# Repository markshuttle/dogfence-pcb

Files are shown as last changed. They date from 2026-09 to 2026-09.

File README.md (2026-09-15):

# Dog Fence Indicator & Surge Protection System

**Draft hardware revision: 1.2.1-dev. Reviewed baseline: 1.1.0. File-verified prototype artifacts are authorized; production and field release remain on hold. No upload or order is authorized.**

This repository documents a 4 km DogWatch SmartFence boundary with local DC fault
indicators and GDT surge paths. The implemented 16-part hybrid includes series
indicator branches and negative-voltage output shunts; it is not a qualified
lightning-protection design or completed hardware test report.

[REMEDIATION](REMEDIATION.md) owns the agreed requirements, issue decisions and
revision-specific results. [BOM.csv](pcb/BOM.csv) and the synchronized CAD/local
libraries own PCB population; [ASSEMBLY](pcb/ASSEMBLY.md#reviewed-components)
explains assembly applicability. [MATERIALS](MATERIALS.md#resistor-procurement-and-history)
preserves purchases, cancellations and allocations. A production pre-order is
not an implemented substitution, and prototype results do not qualify another part.

Use the working schematic, PCB, settings/rules and libraries under `pcb/`, not
generated `build/`, backups or `tmp/` copies, as design sources. File verification
does not close the [engineering holds and release gates](REMEDIATION.md#release-gates).

## 1. Deployment Baseline

| Item | Agreed requirement |
| :--- | :--- |
| Stations | **41**, at 0, 100, ..., 4000 m, covering 40 diagnostic spans. The 0 km and 4 km stations are separate boards at the shed. |
| Station types | **36 standard + 5 earth-connected**, retaining earth-connected locations at 0, 1000, 2000, 3000, and 4000 m. Five locations do not imply five independent electrodes. |
| Field equipment | One identical, fully populated board and two external LEDs per station. [MATERIALS](MATERIALS.md#1-station-inventory) owns total requirements, purchases and shortfalls. |
| Initial order | **Five fully assembled JLCPCB boards**, all required SMT and THT parts fitted. No field soldering. Prototype allocation and later production/spares are separate decisions. |
| Fabrication | Readily available **FR-4, two layers, 2 oz / 70 micrometres copper on both F.Cu and B.Cu, ENIG, nominal 1.6 mm finished thickness**. Green soldermask is the quote default, not a new performance qualification. No imposed high-Tg laminate, gold thickness upgrade, or filled-via process. |
| Enclosure | WISKA COMBI 308 with Essentra LCBSBM-6-01A-RT supports and WISKA **OneGel**, subject to assembled fit and process acceptance. Raised installation, not continuous submersion. |
| TEST duty | Nominal 36 V DC, usually one to two hours. **Continuous-safe normal TEST** is required for accidental extended operation; a timer is not the baseline safeguard. Fault/surge safety needs separate evidence. |
| Visibility | ON/OFF distinguishable at **5 m in full daylight**, at the final minimum field current and actual viewing angles. |

[MATERIALS](MATERIALS.md#assembly-and-quantity-allocation) separates field needs
from prototype consumption, the retained reference and spares. A five-board
prototype order is not five proven field spares.

## 2. Operation And Fault Localization

### Hub Contact Matrix

Both physical cable ends return to the shed. The full
[functional matrix](INSTALL.md#functional-matrix) uses **six independent ends**:
TEST feeds Start A/C positive and Start B negative, leaving End A/B/C individually
isolated. Required ties belong on source-side contacts only. No permanent End A/C
strap, opposite-end B return or dual-B negative return is permitted; those
connections defeat the agreed indication. OFF isolates all six ends at the hub,
but is not demonstrated lightning or maintenance isolation.

Follow [INSTALL's switch/source controls](INSTALL.md#switch-and-supply). Exact
switch configuration, DC suitability and global transfer require approval before
physical terminal assignment; extra poles remain unassigned. No direction
selector, automatic core classification or automatic return to RUN is required.

**TEST and OFF disable RF containment.** Provide clear RUN/OFF/TEST and fence-inactive labeling/indication, independent animal containment during testing, and an explicit operator return to RUN. See [INSTALL.md](INSTALL.md) for the controlled operating instructions and [RISKS.md](RISKS.md) for fault/earthing limitations.

### Indication For A Clean Cut

Use [INSTALL's clean-cut truth table](INSTALL.md#clean-cut-indications) for one
cut site with healthy indicators/GDTs and no additional inter-core shorts. The
first applicable state transition identifies the adjacent 100 m span, including
3900-4000 m; exact broken-core classification is not required. For multiple sites,
[repair and repeat TEST](INSTALL.md#repair-and-retest). Mixed open/short faults or
failed indicators/GDTs need separate troubleshooting; not every dark LED proves a cut.

### Station Connections

Three **WAGO 221-613** three-way splices maintain A/B/C cable continuity and provide short 2.5 mm^2 taps to `J_IN`. Normal perimeter current does **not** pass through every PCB's rails; each PCB draws its local indicator current. Surge current through a board is a different design case.

The [implemented circuit](pcb/ELECTRICAL.md#1-implemented-model) has separate
A-to-B and C-to-B one-way indicator branches. D3/D4 are output shunts after
D1/D2, not additional series parts. GDT paths join the core pairs and the separate
EARTH bus. Standard boards retain all parts but leave external `J_EARTH` unwired;
earth-connected stations follow the accepted site design.

RUN parallels the three cores at each transmitter end. The electrical record
preserves the historical parallel-resistance comparison, not RF compatibility
proof. Actual imbalance, faults, capacitance and earth coupling require checks
with the transmitter and receiver; the boards are not demonstrated RF-invisible.

## 3. Electrical Limits And Open Protection Work

Use [ELECTRICAL's named historical comparisons](pcb/ELECTRICAL.md#2-calculated-results)
and [DESIGN_BOUNDS](pcb/DESIGN_BOUNDS.md) for the current population's
cable/tolerance, leakage, power and fault screens. They are conditional models,
not measurements, enforced source limits, an exhaustive brightness minimum or
thermal qualification. The source/test commands and assumptions travel with those
records; do not copy retired-part values into current operating limits.

- Use **one TEST supply and one disconnected spare**, never interconnected
  supplies. Verify the actual unit and qualified settings under
  [INSTALL](INSTALL.md#switch-and-supply); a larger PSU does not coordinate faults.
- Negative shunts are not forward pulse-current regulators or reversed-lead
  immunity. Reverse recovery is not forward-clamp response. Ordinary RF,
  switching and nearby-lightning behavior remain unqualified.
- Cable-limited faults may not clear the fuse promptly. Powered-GDT recovery is
  unresolved, not an observed latched failure; conditional load lines do not
  predict extinction. Indicator resistors/shunts do not protect upstream GDT paths.
- Resistor wattage and SMT construction do not prove cool OneGel operation.
  Manufacturer mounting/rating transfer and actual chip/pad/PCB/material-interface
  temperatures require separate qualification; retired-part pulse/thermal data do
  not transfer. Continuous-safe normal TEST remains mandatory, without a timer.
- DC sparkover is not transient clamp voltage. Component impulse ratings,
  paralleled pins and heavy copper do not establish assembled surge/current,
  equal-sharing, direct-strike or lifetime ratings.

The [accepted risk boundaries](REMEDIATION.md#agreed-requirements) allow LED
damage from accidental installation polarity errors and rebuilding after a direct
strike, not all ordinary/nearby transient damage. Maintain the
[whole-boundary cattle-fence prohibition](INSTALL.md#cattle-fence-prohibition);
the withdrawn exposure is not qualified safe. [ACCEPTANCE](ACCEPTANCE.md) defines
the unperformed hardware tests; [RISKS](RISKS.md) explains their consequences.

## 4. Hardware Component Selection & Specifications

Use [BOM.csv](pcb/BOM.csv) and [Reviewed Components](pcb/ASSEMBLY.md#reviewed-components)
for the exact population, sourcing identities and assembly requirements. Detailed
component electrical ratings remain in [ELECTRICAL](pcb/ELECTRICAL.md#1-implemented-model);
reviewed drawings, maximum dimensions and rating conditions remain in the
controlled assembly/evidence notes. A C-code is not footprint or stock allocation
approval. The external indicator's limits, polarity, mounting and visibility
requirements are in [LED.md](LED.md).

[MATERIALS](MATERIALS.md#resistor-procurement-and-history) owns cancelled,
superseded and rejected selections. They are not substitutions or a second active
BOM. Sourcing parity does not establish job allocation; unresolved External rows
still block both publication modes under [AGENTS' sourcing rules](AGENTS.md#3-verification-and-publication).

## 5. Unapproved Alternatives

Retain these earlier sourcing suggestions for investigation, **not as approved upgrades or drop-ins**. No purchase, footprint fit, higher assembled surge capability, or lifetime benefit is established by this list. Differences in electrode configuration, body, lead diameter, pin mapping, RF loading, and thermal/pulse behavior may require redesign and new qualification.

| Intended references | Previously suggested alternatives |
| :--- | :--- |
| D1, D2 | Vishay 1N4007GP-E3/54 |
| R1, R2 | Vishay PR02000202201JA100, historical PR02 suggestion; both it and the former 1% FA100 selection are **retired, not the selected 2512 SMT part** |
| GDT_AB, GDT_BC | Littelfuse SH470 |
| GDT_AC | Bourns 2027-47-BLF or Littelfuse CG2-470L |
| Earth GDTs | Littelfuse SL1021A470R |
| J_IN, J_EARTH | Phoenix Contact 1731734, GMKDS 3/ 3-7,62 |
| LED terminals | Phoenix Contact 1715721, MKDS 1,5/ 2-5,08 |
| External LED | APEM Q14P5BXXHG02E, discussed in LED.md |

A higher resistor wattage does not reduce heat at the same resistance/current. A larger LED bezel does not prove better daylight contrast. Global sourcing/private inventory is an option only after engineering approval and a supplier quote; it is not a guaranteed route to stock or a fixed lead time.

## 6. PCB And Assembly Constraints

**Read [ASSEMBLY's Physical Guardrails](pcb/ASSEMBLY.md#physical-guardrails)
before changing geometry or process.** It owns the complete outline/mount,
copper/via, isolation, polarity, placement, land, forming and tolerance inventories.
Preserve protected geometry and distinct local LED mappings; do not narrow copper,
fold branches, add vias or trim courtyards to conceal an assembly problem.

The **2026-09-14 user-approved change** makes GDT_AC the same top-side Ruilon
SMT part as GDT_AB/BC and carries the B crossing on the rear layer. A/C main
rails remain 3.20 mm on both faces; the rear B main rail is **exactly 6.00 mm**,
with the approved front-B stop and minimal rear-return move controlled in
ASSEMBLY. The new **>=3.00 mm A/B/C inter-core copper rule is B.Cu-only**, not
a blanket front-layer rule. GDT_AC's axial overpass and two insertion holes are
retired; only the three earth GDTs still require lead forming. The board
dielectric at the crossing is not qualified impulse insulation. Circuit
connectivity, RUN/TEST operation and the distinct LED mappings are unchanged.

The subsequently approved **1.2.1-dev westward spacing change** relocates the
nine rail vias and three SMT GDTs and shortens front B. The
[current spacing controls](pcb/ASSEMBLY.md#smt-via-relocation) require **>=3.00 mm
between unlike-net pads of different GDTs and between AC pads and front B
copper**, with **3.20 mm nominal minimum**. Each tube's internal land/copper
gaps are a separate scope; neither the new spacing nor DRC proves flashover immunity.

The approved **2 mm east board extension**, still **1.2.1-dev**, makes the
outline **65 x 56 mm** and moves H2/H4 east without moving J_EARTH or functional
copper. [J_EARTH's edge-clearance controls](pcb/ASSEMBLY.md#earth-terminal-edge-clearance)
own the nominal-versus-budgeted body/pose and courtyard margins; neither is
supplier-tolerance or measured-fit approval.

The [retained resistor lands](pcb/ASSEMBLY.md#2512-smt-resistors) are an
alternative to the manufacturer's recommendation, not an exact-fit approval.
Actual parts, stencil/solder process, earth-GDT forming, edge clearance and
enclosure/support fit remain separate acceptance tasks. Source stackup arithmetic is not a finished
thickness guarantee; ENIG is not a hermetic seal. Use the controlled notes and
[ORDERING](ORDERING.md#3-hole-via-and-solder-process) for the actual handoff.

### Via and Component Hole DFM

**Policy updated 2026-09-07. Selected standard process: UNTENTED both sides, no fill/plug/cap, ENIG.** Source openings are nominal 1.80 mm with no via paste; no special 1.00 mm filling or reliable tenting is assumed. Recheck each actual order's processed data and assembly process. References: [JLCPCB capabilities](https://jlcpcb.com/capabilities/pcb-capabilities), [via covering](https://jlcpcb.com/help/article/pcb-via-covering), and [via versus component-hole tolerances](https://jlcpcb.com/help/article/difference-and-tolerance-explanation-between-via-and-pad-holes).

The following limits concern the **hole**, not its copper pad:

| Process | Published guidance | Consequence for the protected 1.0 mm holes |
| :--- | :--- | :--- |
| **Untented, selected** | Standard process; exposed copper receives ENIG. | No seal. Inspect solder ingress/beads and environmental protection. |
| Tented | Ideally at most 0.4 mm; normal coverage guidance at most 0.5 mm. | Larger holes are not guaranteed covered. A KiCad tenting flag is not proof. |
| Soldermask plugged | At most 0.5 mm, no mask openings on either side, at least 0.35 mm process clearance from other mask openings/pads. | Outside the normal limit. Ink plugging is not filled-and-capped via-in-pad processing. |
| Filled and capped | Detailed guide recommends at most 0.5 mm; capability table lists 0.15-0.55 mm. Resolve the applicable limit with CAM. | 1.0 mm exceeds both ranges; any exception needs written process acceptance. |

- Preserve **all 14 stitching vias at 1.0 mm drill / 1.8 mm pad** and the protected copper. Fix surrounding soldering geometry or seek an approved process/layout solution; do not delete or shrink vias to fit a covering option.
- Inspect full drill circles and exposed annuli against actual `F.Mask`, `B.Mask`, and `F.Paste`, then the processed mask/stencil. [ASSEMBLY's SMT/via inventory](pcb/ASSEMBLY.md#smt-via-relocation) records the corrected aperture gaps and selected metric lands; the drawing discrepancy and actual solder-volume/profile acceptance remain held. Adjacent same-net rail-via mask circles intentionally overlap, but no component paste/mask aperture is excused over a via hole.
- Identify treatment by **coordinates and hole function**, never diameter alone. Legacy resistor/diode and GDT_AC insertion holes are retired. All retained connector/earth-GDT insertion holes remain open. Ordinary via diameters may be adjusted in CAM; check that no protected nominal drill was reduced. No fill is requested.
- **70 micrometres of exterior copper is not 70 micrometres of barrel plating.** JLCPCB's published 18 micrometres average hole plating is not a guaranteed minimum in every barrel. Agree any finished minimum used in current/surge calculations separately. Nonconductive fill adds no conductive cross-section.
- Tenting, plugging, opacity, or gel encapsulation does not prove hermetic sealing, freeze-thaw immunity, or an assembled ingress rating.

Use **component PTH pads**, never ordinary vias, for lead insertion. Record the exact manufacturer/MPN, drawing revision, maximum finished lead dimensions, pitch, proposed hole, and assembly allowance. For round holes:

```text
Round pin envelope       = maximum finished lead diameter
Rectangular pin envelope = sqrt(maximum_width^2 + maximum_thickness^2)
nominal finished hole - 0.08 mm >= maximum pin envelope + 0.10 mm
```

The last line uses JLCPCB's ordinary component-hole **+0.13/-0.08 mm** tolerance and the project's starting **0.10 mm diametral allowance after tolerance**. Increase the allowance when required; also account for pin-pitch, hole-position, and forming tolerances, particularly rigid connectors. This is stricter than simply adding 0.10 mm to a nominal pin. Do not assume press-fit tolerances for this order.

The exact [SMA lands/polarity](pcb/ASSEMBLY.md#indicator-sma-and-resistor-assembly),
[resistor lands](pcb/ASSEMBLY.md#2512-smt-resistors) and
[component hole/pad/pin schedule](pcb/ASSEMBLY.md#hole-fit-evidence) are controlled
in ASSEMBLY. Diodes, resistors and all three inter-core GDTs are SMT, not insertion
or axial-forming parts. Allocated THT parts must pass free-insertion, earth-GDT
forming/standoff and solder inspection with separate position/pattern allowances. Supplier CAD or nominal
pitch is not actual lot acceptance.

After drill changes, recheck pad sizes, hole/copper spacing, edge clearances and **at least 0.254 mm nominal component PTH annular ring for two-layer 2 oz fabrication**. Generic via-ring rules do not establish component-pad compliance. Finished-ring acceptance also requires hole and registration tolerances. Resolve fit in CAD, not by forced insertion or reaming plated boards.

DRC alone cannot close hole-fit, solder-wicking, body/forming, or process approval. Record the accepted evidence in the controlled assembly notes, regenerate the production outputs, and inspect the final processed files.

## 7. Enclosure, Cable And Site

Follow [INSTALL's materials/site requirements](INSTALL.md#materials-and-site),
[workshop dry-fit](INSTALL.md#workshop-assembly) and
[gel/service procedure](INSTALL.md#gel-and-service). The coastal, wet and partly
sunlit route requires assembled thermal/environmental qualification, not reliance
on component IP or temperature labels. OneGel is single-component/no mixing;
its conflicting published process/temperature fields and missing thermal data
remain unresolved in [ENVIRONMENT_EVIDENCE](pcb/ENVIRONMENT_EVIDENCE.md).

Cable identity and red/black/plain-green colours are settled; supplied-lot,
UV/wet-conduit and impulse applicability still need evidence. Label A/B/C
end-to-end: plain green is not PE, and **green/yellow is never an active core**.
Keep the boundary electrically separate from supporting fence wires and inspect
and maintain the [whole-boundary cattle-fence prohibition](INSTALL.md#cattle-fence-prohibition).

A qualified installer must approve the site-specific PE/electrode/OEM protection
arrangement, including the proposed shared shed earth. Do not directly earth a
core, switch PE or invent unbonded rods or a DC-negative earth bond. Inventory is
not an approved discharge-path design. Apply [INSTALL's safety controls](INSTALL.md#safety-first).

## 8. Verification And Release

Use the headless environment and full
[verification/publication workflow](AGENTS.md#3-verification-and-publication).
Native DRC/ERC, parity, geometry, population and exported artifacts are checked
against a complete snapshot. All errors and unreviewed diagnostics block; narrow
reviewed warnings remain visible. Tested KiCad is **9.0.7**, not an unverified
7/8 compatibility claim.

```bash
make check
make prototype
```

`make check` verifies without publication and refreshes the draft CPL only after
all file/artifact checks pass. `make prototype` / `make gerbers` may publish
**FILE-VERIFIED PROTOTYPE ONLY** with all five ledger holds deferred, not closed.
Production targets retain their holds and win mixed goals; unresolved External
sourcing blocks both modes. The [east-extension handoff](REMEDIATION.md#east-board-extension)
controls current verification status and the matching source/controlled-note snapshot.

The earlier [westward-spacing checks](REMEDIATION.md#westward-gdt-spacing) and
SMT AC/rear-B publication remain historical evidence for their recorded inputs.
They do not verify the east extension or changed controlled notes, even where
the **1.2.1-dev** identifier is unchanged.

Require matching `build/status.json` and `build/manifest.json` with validated
revision/source/artifact hashes and **status=prototype, mode=prototype**, or
production **status=verified, mode=build**. Shared filenames alone prove nothing.
New attempts quarantine old outputs; run cleanup separately and preserve evidence.

[ORDERING's artifact guide](ORDERING.md#1-before-upload) describes Gerbers,
BOM/CPL, bare-board FlyTest and assembly aids. Generated mode/hold notices travel
inside both ZIPs; the seven controlled notes accompany the full release directory,
not the ZIPs alone. Never hand-edit artifacts or correct signed Y with `abs(Y)`.
Obtain separate processed CAM/stencil and parts-placement/assembly approvals.

The [release-gate definitions](REMEDIATION.md#release-gates) keep Gate P separate
from original A/B/C production/field holds. Supplier part/fit/forming, allocation,
panel/process and CAM/placement remain order tasks. Enclosure dry-fit and
prototype-dependent tests follow receipt, not as prerequisites to prototype files.
Neither file generation nor basic five-board tests authorize upload, an order,
containment/protection use or full rollout.

## 9. Documentation Map

| Document | Role |
| :--- | :--- |
| [REMEDIATION.md](REMEDIATION.md) | Agreed requirements, issue/evidence register, gates and session handoff. |
| [AGENTS.md](AGENTS.md) | Headless tooling, staging, mandatory guardrail reads and documentation maintenance. |
| [INSTALL.md](INSTALL.md), [RISKS.md](RISKS.md), [ACCEPTANCE.md](ACCEPTANCE.md) | Operating, risk and qualification procedures, synchronized by their owners with the final circuit. |
| [ORDERING.md](ORDERING.md), [MATERIALS.md](MATERIALS.md), [LED.md](LED.md) | Quote/approval workflow, procurement ledger, indicator limits and visibility target. |
| [REVIEW.md](REVIEW.md) | Reusable read-only audit brief, not a completed review or sign-off. |
| [ELECTRICAL](pcb/ELECTRICAL.md), [ASSEMBLY](pcb/ASSEMBLY.md), [DESIGN_BOUNDS](pcb/DESIGN_BOUNDS.md) | Circuit/model interpretation, physical/component controls and current parametric screens. |
| [DFM evidence](pcb/DFM_EVIDENCE.md), [environment evidence](pcb/ENVIRONMENT_EVIDENCE.md), [LED research](pcb/LED_PROTECTION_RESEARCH.md), [source research](pcb/SOURCE_PROTECTION_RESEARCH.md) | Manufacturer evidence, named historical investigations and later applicability corrections; not selected circuits or approvals. |
| [Makefile](Makefile), `pcb/pcb.kicad_sch`, `pcb/pcb.kicad_pcb`, `pcb/pcb.kicad_pro` | Build implementation and authoritative design/project sources, together with applicable rules and local libraries. |

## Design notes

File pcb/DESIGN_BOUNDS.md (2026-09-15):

# Conditional Design Bounds

Hardware **1.2.1-dev**, westward GDT/via relocation recorded 2026-09-14; TE
evidence/provenance correction retained from 2026-09-11. This note
owns current parametric screens from `scripts/analyze_limits.py` and
`scripts/design_bounds.py` for the **16-part TE 35212K2FT / BYG23T prototype
circuit**. [BOM.csv](BOM.csv) selects **TE Connectivity 35212K2FT / C4129105**;
**Yageo SR2512FK-7W2K2L / C876850 is not populated or qualified by this model**.
Its independent part/model/process/thermal review and controlled source updates
are required before production use under
[Reviewed Components](ASSEMBLY.md#reviewed-components).

The nodal solver, topology and cable/source/site assumptions are retained;
all normal-model numerical screens are unchanged. These are calculations, not
hardware qualification or closure of **C4/C5/W3/W1/W4** in
[verification.json](verification.json). Those holds are deferred only for
file-verified prototype artifacts, not production/field approval; no physical-test
prerequisite is added to Gate P. [Artifact controls](ASSEMBLY.md#prototype-artifacts)
explain the separate file, supplier and qualification scopes. Purchase history
is in [MATERIALS](../MATERIALS.md#resistor-procurement-and-history), an optional
**repository-only** reference, not part of the flat engineering-note package.

The user-approved AC conversion and subsequent westward placement change the
physical copper paths, not any of the six GDT endpoint connections. The [copper screen below](#ac-conversion-copper-screen)
is separate arithmetic, not a change to either DC script or a thermal
qualification. Native/file verification requires matching current reports and
artifact hashes; earlier results do not verify this changed snapshot.

## Selected Circuit

```text
WIRE_A -> R1 35212K2FT -> D1 BYG23T-M3/TR -> LED_A_POS -> external LED -> WIRE_B
WIRE_C -> R2 35212K2FT -> D2 BYG23T-M3/TR -> LED_C_POS -> external LED -> WIRE_B
D3 BYG23T-M3/TR: cathode LED_A_POS, anode WIRE_B
D4 BYG23T-M3/TR: cathode LED_C_POS, anode WIRE_B
```

D3/D4 are **negative clamps after the series diodes**, not input shunts or
positive-voltage regulators. Negative connector voltage forward-biases the
corresponding clamp. The [forward-only core-to-B model](ELECTRICAL.md#1-implemented-model)
remains applicable to healthy normal TEST; there is no new forward B-to-A/C path. Actual series-diode
reverse leakage, junction capacitance, recovery and harness ringing are not
solved. The electrical regression is not a source-connectivity guard or proof
that physical dark branches have zero leakage.

The user accepts installation lead-reversal LED damage and direct-strike
rebuilding. **Energized cattle fencing is prohibited near the ENTIRE boundary,
including the 4 km cable, every station and the hub**, not just the shed. This
supersedes the earlier 0.5 m / 300 m exposure assumption; no numerical safe
separation is established here. RF, ordinary switching, nearby lightning,
powered recovery and continuous thermal behavior remain unqualified. Normal
TEST must still be continuous-safe; no timer or active current-stage prerequisite
is added.

## Evidence And Inputs

- **User-confirmed reels:** `CM03/05.100`, labelled
  `3 CORE (3 x 35/0.30) TINNED BLACK 100 MTR`. Identity is settled, not measured
  conductor resistance. The user also confirmed **one LRS-75-36 for TEST and
  the second as a spare**, not interconnected supplies.
- **Resistance source:** IEC 60228:2004, edition 3, section 6.2 and Table 3,
  printed page 11, gives **8.21 ohm/km maximum at 20 C** for Class 5,
  metal-coated 2.5 mm^2 copper [1]. The plain-copper column is 7.98, not the
  tinned value. Section 2.1 explicitly includes tin in "metal-coated".
  Nexans reproduces the same values in its February 2021 table, page 3 [2].
- AMC's exact **2026 Update V.3** specifies Class 5 tinned conductors,
  **BS EN 60228:2005**, CM03/05 = 3 x 2.5 mm^2, and -30..70 C [3]. This
  supports using the standard maximum **conditionally**, without demanding an
  absent AMC numerical resistance column. BSI identifies the British edition
  as identical to EN 60228:2005 [4]; no claim is made that it is the latest edition.
- **Separate construction discrepancy:** Table 3 limits wires to **0.26 mm**;
  AMC's representative construction/reel label says **0.30 mm**. AMC permits
  representative strand configurations to differ. Do not call the label proof
  of complete Class 5 compliance or of measured resistance. Retain the 8.21
  conditional design ceiling while the construction declaration is reconciled.
- **Declared model envelope:** 41 stations at 100 m spacing; same-end A/C
  positive and B return; six independent ends and one-way branches. Source
  nominal 36 V; **35 V floor / 40.39597 V upper are current analysis inputs,
  not an enforced operating window or a guaranteed combined MCOV**. The floor
  must include hub/interface/contact losses at the feeds. The legacy **35..37 V
  proposal was never implemented**; selecting `--source-max-v 37` only changes
  a calculation. LRS adjustment is **32.4..39.6 V**; its **41.4..48.6 V OVP**
  enforces neither 37 V nor the 40.39597 V screen [5]. The deliberately stacked
  adjustment/tolerance screen remains:

  `39.6 * 1.01 * (1 + 0.0003 * (50 - 25)) + 0.1 = 40.39597 V`.

  The **+/-1% includes setup, line and load regulation**, not three additive
  tolerances. The **+/-0.03%/C** figure applies over **0..50 C**, not the whole
  -30..70 C operating range. Published ripple/noise is **200 mV peak-to-peak**
  under the stated measurement arrangement; **0.1 V is a selected ripple peak**,
  conservatively treated as continuous here. Accessible setting, tolerance
  interaction, startup/overshoot, malfunction and actual maximum still need
  evidence. A passive design qualified over the real normal source range is
  possible; the model does not demand an active 37 V cutoff to pass W3.
- **Cable/contact corner:** 70 C with the existing copper approximation
  `alpha = 0.00393/K`. Each core in **each 100 m span** is allowed 0.025 ohm of
  additional contacts/splices at service temperature: 1.00 ohm per 4 km core.
  This is a declared budget, not a WAGO specification or a measured result.
  It must bound the individual spans, not merely the whole-core sum. The script
  accepts separate A/B/C budgets and does not apply copper TCR to contacts.
- **R1/R2:** TE Connectivity **35212K2FT** (CGS 3521 Series), 2512 SMT, 2200 ohm,
  +/-1%, **+/-100 ppm/C at 2.2k**, catalogue **2 W P70** [12]. The currently served
  **9-1773463-5 Rev G, 02/2025** method calls for characterization at room and
  minimum/maximum operating temperatures (User Spec); it does **not** explicitly
  specify a 25 C TCR reference or -55/+125 C TCR endpoints. The **25 C reference,
  linear -30..125 C screen and supported -55..125 C helper inputs are declared
  engineering model assumptions**, not TE-confirmed test conditions. The unchanged
  screen gives **2156.22..2244.22 ohm**:
  `Rmin = 2200 * 0.99 * (1 - 100e-6 * (125 - 25))`.
  **No extension to the separate 155 C operating endpoint is modeled.** Temperature
  is an input, not a self-heating result. Aging, assembly/solder drift and
  unbudgeted tap/harness losses are excluded. Catalogue P70/derating transfer to
  the actual two-layer PCB remains conditional as described below.
- **Identity applicability:** JLCPCB independently confirms the TE prototype
  identity [13] and the unpopulated Yageo identity [14], not interchangeability
  or suitability of this TE model for Yageo. The historical rejected-code
  correction remains in [DFM's HP12 investigation](DFM_EVIDENCE.md#hp12-investigation-history).
- **Retained geometry, not an exact TE land-pattern match:** body containment
  does not establish land/process equivalence. Use the detailed
  [assembly land schedule](ASSEMBLY.md#2512-smt-resistors) and
  [TE drawing comparison](DFM_EVIDENCE.md#te-3521-body-and-lands-fit).
  The project alternative remains unchanged and requires W4 placement/stencil/
  solder-process acceptance; no reroute or thermal equivalence follows.
- **D1-D4:** Vishay **BYG23T-M3/TR**, 1300 V repetitive reverse, SMA [8].
  Preserve **36 V / 2.1 V LED + 0.7 V diode** as a named zero-leak historical
  comparison, not measured BYG23T Vf at roughly 15 mA. Its **1.9 V maximum at
  1 A / 25 C** is a 300 us, 1%-duty pulse test, not a minimum or typical value
  at indicator current. The **5.2 V = 3.3 LED + 1.9 diode** high-drop screen
  replaces 4.4 V for headroom/brightness studies. Neither the APEM family 3.3 V
  figure nor the BYG23T test point supplies a full-temperature low-current I/V
  bound. Zero junction drops still screen maximum branch current and heat.
- **Clamp leakage:** the only cited maxima are **5 uA at 25 C / 50 uA at
  125 C**, both at **1300 V reverse**, pulse width <=40 ms [8]. There is no
  guaranteed 5 uA limit at LED voltage across all temperatures. A deliberately
  conservative **50 uA per branch** screen assumes monotone leakage versus
  reverse voltage and temperature for normal positive LED voltage within
  rating and device temperature <=125 C. It is conditional, not a new vendor
  specification. It does not extend to the 150 C junction maximum, avalanche,
  transients or damaged parts.

Sources [1]-[9] preserve earlier evidence; [6]/[7] concern retired axial resistors
and [9] the superseded HP12 selection. For that HP12 SMT conversion, the supplied
research review visually confirmed [9], pages 1, 2, 4, 5, 6 and 8.
For the PS12 selection, the supplied research review read [10], pages
1, 2, 4, 5, 6, 7 and 8, and verified the historical JLCPCB identity [11].
The **2026-09-11 correction** uses the supplied TE review plus a fresh text
extraction of [12] through `https://r.jina.ai/` after direct webfetch returned
PDF binary. It confirms Rev G, 02/2025 and the stated method/mounting text;
this is not a new visual inspection of the pad leaders or supplier acceptance.
The supplied drawing review is controlled in ASSEMBLY/DFM. The live JLCPCB
page [14] was also fetched and independently confirms the Yageo identity.
No vendor reply, received part or physical test is inferred.

1. [IEC 60228:2004 public standard preview, including Table 3](https://cdn.standards.iteh.ai/samples/12024/921fee9a88c24612b68340a7330c2262/IEC-60228-2004.pdf), with [IEC edition metadata](https://webstore.iec.ch/en/publication/1065).
2. [Nexans IEC 60228 classification, February 2021](https://www.nexans.be/en/dam/jcr:efe5d9a2-f346-4047-87b4-99d1e319d768/IEC60228_ENG.pdf).
3. [AMC Tinned Copper 3 Core Cables, 2026 Update V.3](https://cdn.prod.website-files.com/62deaee72baf3ef3b83165ff/69fc985a23120ee62491a529_14%20-%20AMC%20Datasheet%20%20-%20Oceanflex%20Tinned%20Copper%203%20Core%20Cable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).
4. [BSI BS EN 60228:2005 metadata](https://knowledge.bsigroup.com/products/conductors-of-insulated-cables).
5. [Mean Well LRS-75 specification, 2025-04-07](https://www.meanwell.com/Upload/PDF/LRS-75/LRS-75-SPEC.PDF).
6. [Vishay 28766, MBE/SMA 0414, 11-Jul-2018](https://www.vishay.com/docs/28766/mbxsma.pdf), pp. 2-4/8/11: **historical** MBE rating modes and TCR, not the selected resistor.
7. [Vishay PR01/PR02/PR03, 28729, 08-Jul-2025](https://www.vishay.com/docs/28729/pr010203.pdf): **historical, retired PR02 only**. Cu/FeCu ratings, TCR, mounting/hot-spot examples and PR02-specific 220 C limit do not apply to SMT 2512.
8. [Vishay BYG23T-M3, 89429, 25-Feb-2020](https://www.vishay.com/docs/89429/byg23t.pdf): pp. 1-2 ratings, exact `/TR` ordering, leakage/Vf test conditions and typical forward recovery. Original pulse/thermal curves are not a system qualification.
9. [Uni-Royal HP Series, SMD-SP-003, V.7, 08-Jan-2026](https://www.uni-royal.cn/en/images/userfile/file/1784806233a2e6d381ea80b5d9.pdf): **historical, superseded HP12 selection**.
10. [Uni-Royal PS Series, SMD-SP-007, V.7, 08-Jan-2026](https://www.uni-royal.cn/en/images/userfile/file/1784854235b7c79f8d8a205c5d.pdf): **historical PS12 review**, not current population or TE/Yageo specifications.
11. [JLCPCB C2793873](https://jlcpcb.com/partdetail/C2793873): historical Uni-Royal PS122WF2201T4E identity.
12. [TE Connectivity CGS 3521 Series, Data Sheet 9-1773463-5 Rev G, 02/2025](https://www.te.com/commerce/DocumentDelivery/DDEController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): active prototype selection 35212K2FT. P1 catalogue 2 W at 70 C ambient, derating to zero at 155 C, -55..155 C operation and 250/500/500 V working/overload/dielectric ceilings; p2 working-voltage formula; p3 recommended pads and four-layer 2 oz outer / 4 oz inner mounting; p4 +/-100 ppm/C at 2.2k, characterized at room/min/max operating temperatures (User Spec), without numeric TCR reference/endpoints. No short-time overload voltage/duration is established by the 500 V ceiling. AEC-Q200 qualification is not board qualification.
13. [JLCPCB C4129105](https://jlcpcb.com/partdetail/C4129105): exact TE Connectivity 35212K2FT, 2.2k/2 W/1%/100 ppm/2512 prototype identity, not job allocation.
14. [JLCPCB C876850](https://jlcpcb.com/partdetail/C876850): exact Yageo SR2512FK-7W2K2L, 2.2k/2 W/1%/100 ppm/2512 identity. The listing does not establish suitability of the TE model for Yageo or independent manufacturer/process/thermal qualification.

The machine-readable output distinguishes catalogue data, assumptions and unknowns:

| Field | Decision / provenance |
| :--- | :--- |
| `model_scope` in both CLIs | `prototype_only`; selected-part data describes TE 35212K2FT, not Yageo. |
| `resistor.datasheet` in `design_bounds.py` | Document `9-1773463-5`, revision `G`, date `02/2025`. |
| `resistor.reference_temperature_c`, `screen_temperature_range_c`, `supported_temperature_range_c` | Retain `25`, `[-30,125]`, `[-55,125]`; both `reference_temperature_basis` and `temperature_screen_basis` are `declared_engineering_assumption`. `analyze_limits.py` also exposes the reference and linear model under `resistor_model_assumptions`. |
| `resistor.tcr_test_method` | Room and minimum/maximum operating temperatures (User Spec); not numeric test endpoints. |
| `resistor.tcr_test_reference_temperature_c`, `tcr_test_temperatures_c` | `null`: numerical manufacturer test parameters are not established by the reviewed evidence. |
| `resistor.short_time_overload_test_v`, `short_time_overload_test_s` | `null`: do not import the historical PS/HP overload multiplier or five-second duration. |
| `resistor.catalogue_mounting`, `board_rating_transfer_verified` | Four layers, 2 oz outer / 4 oz inner; transfer to this two-layer board is unverified (`false`), not a demonstrated failure. |

## Normal Current

At 20 C the conditional conductor maximum is **32.84 ohm/core**, versus the
old nominal **27.60 ohm/core**. At 70 C it is **39.29306 ohm/core**, or
**40.29306 ohm/core** including the declared contact budgets.

The solver's existing `led_currents_a`, `led_min_ma`, `A40_ma` and related
fields are **branch currents before clamp diversion**, equivalent to LED
current at zero leakage. They are retained for the historical comparisons.
The new `*_after_clamp_leakage_ma` fields subtract at most 0.05 mA locally:

```text
I_branch = max(0, (V_core - V_B - V_LED - V_D) / R)
I_LED_lower = max(0, I_branch - 50e-6)
I_branch = I_LED + I_clamp
P_R = I_branch^2 * R
P_D = I_branch * V_D
P_LED + P_clamp = I_branch * V_LED
```

This is a supported-parameter subtraction screen, not a constant leakage sink
on an unpowered/floating branch or a new nonlinear solver. At fixed conducting
LED Vf, clamp leakage **does not add to PSU/cable/R/series-diode current**. If
leakage consumes the branch current, the fixed-Vf partition needs actual I/V
data; `branch_budget()` rejects an overdrawn partition. The named normal
corners below retain conducting LEDs after diversion; clipped zero bounds in
other input studies are not physical OFF-current predictions.

| Case | Feed V | A40 branch mA | A40 LED lower mA after diversion | Source A |
| :--- | ---: | ---: | ---: | ---: |
| Historical 6.9 ohm/km, 20 C, 2.8 V Vf / 2200 ohm | 36 | 8.044804 | 7.994804 | 0.847705 |
| Standard maximum, 20 C, no contacts, same nominal loads | 36 | 7.300320 | 7.250320 | 0.804701 |
| Declared 70 C cable/contact corner, same nominal loads | 36 | 6.410705 | 6.360705 | 0.752464 |
| Uniform 5.2 V high Vf / 2512 SMT Rmax at every branch | 35 | 5.717067 | 5.667067 | 0.666615 |
| Only A40 high Vf; all other Vf zero; Rmax everywhere | 35 | 4.452016 | 4.402016 | 0.781940 |
| Only A40 high Vf / Rmax; all other Vf zero / Rmin | 35 | 4.277619 | 4.227619 | 0.802694 |
| Previous case with the other positive rail C at zero ohms | 35 | 3.793669 | 3.743669 | 0.860225 |
| Zero cable/contact R, zero Vf / 2512 SMT Rmin everywhere | 40.39597 | 18.734624 | 18.684624 | 1.536239 |

The last row is a zero-drop upper stress screen, not a physical LED operating
point. A real clamp need not draw the full 50 uA, especially at zero bias;
maximum possible LED current uses **zero** diversion, not forced subtraction.

Uniform Vf overstates A40 current by **1.265050 mA** even before the additional
**0.174397 mA** reduction from asymmetric resistor tolerance. Lower resistance
in C can increase shared B loading and further reduce A current. Mirrored
C40 cases are also calculated; they agree only for symmetric cable inputs.
The named corners are **not** an exhaustive joint-tolerance minimum.

For a conservative all-station floor without assuming equal source contacts
or uniform loads, two independent comparisons reuse the existing solver:
ground B and load the positive rail with Rmin/zero Vf at the **35 V floor**;
then hold A/C ideal at the **40.39597 V upper screen** and load B with both
Rmin/zero-Vf channels. Actual positive potentials cannot be lower than the first comparison,
and actual B cannot exceed the second, within the stated healthy passive
envelope. Their worst differences occur at the far end. Subtract the declared
maximum Vf and divide by Rmax, clipped at zero, then subtract the conditional
leakage bound. The positive-rail lower value is **24.8554792613 V**, B upper is
**18.7821480669 V**, and this intentionally loose all-station floor becomes
**0.3891468726 mA branch / 0.3391468726 mA LED after diversion**. It is much
lower than the coupled-corner currents, not predicted installed brightness.

The old **1.4945906084 mA** floor belonged to **MBE 50 ppm/K, 35..37 V and
4.4 V high Vf with zero clamp leakage**. It is reproduced by an explicitly
named historical regression, not silently reused for TE 3521/BYG23T. Even merely
subtracting 50 uA would make that old comparison 1.4445906084 mA; that does not
account for the changed source/R/Vf inputs and is not the current floor.
Neither number is an optical dark threshold. The existing **1 uA** cut-state
classifier tests the ideal one-way model only; reverse leakage through series
D1/D2 can exceed that classifier and is not solved. Verify actual ON/OFF
distinguishability, including leakage-induced glow, sunlit lenses and the
minimum accepted current at **5 m in full daylight**. No brightness or physical
blackout guarantee follows from the cuts passing or the floor being positive.

The independent upper bound is **18.7346235542 mA/branch**,
**1.5362391314 A / 62.0578698666 W** for 82 branches, and
**37.4692471084 mA at the local PCB B tap**. WAGO through-splices
carry distributed perimeter current, not just that tap current. One LRS-75-36
needs at least **82.0871%** of its rated current/power capacity available for this
upper load, before auxiliary/interface losses. Actual input/thermal derating
still applies; its spare contributes no capacity.

## Thermal Screens

TE 3521's **catalogue** rating is **2 W from -55 to 70 C ambient**, derating
linearly to **zero at 155 C ambient** [12]:

`P_allow(T_local) = 2 * clamp((155 - T_local)/(155 - 70), 0, 1)`.

**Mounting transfer is conditional:** TE p3 specifies a **four-layer PCB with
2 oz outer and 4 oz inner copper**. The actual board is **two-layer, 2 oz per
side**. The unchanged equation and all rating-only margins/ceilings below are
catalogue arithmetic, not an established 2 W allowance for this mounting.
Accept the [alternative-land/process review](ASSEMBLY.md#2512-smt-resistors)
and establish actual thermal performance separately. The difference is **not
evidence that the two-layer board fails** and does not authorize a geometry/
topology change.

**155 C is the zero-power ambient/operating endpoint, not a demonstrated
powered-chip or material-interface temperature.** No separate 3521 hot-spot
ceiling or mounted K/W parameter is established in this model. SMT sends heat
through chip terminations, solder lands and the PCB differently from the retired
axial parts; it does not remove the dissipated watts or prove a cooler result.
PR02 body standoff, lead forming and its thermal examples do not apply to the
selected no-hole SMT resistor. Ambient derating alone is not W3 closure.

The TE 3521 family maxima are **250 V working, 500 V overload and 500 V dielectric
withstand** [12]. Rated continuous working voltage (RCWV) is limited by
`min(250, sqrt(P * R_nominal))`: **66.3324958071 V at 2 W / 2200 ohm**.
That is valid catalogue arithmetic, not the qualified working voltage of this
board. The **500 V overload ceiling does not specify a short-time test voltage,
multiplier or duration** for the selected TE part. Both test voltage and duration
are therefore unknown/`null` in this model. The historical PS/HP overload formulas
and PS one-pulse curves are not TE evidence and are not used here. Neither the
working-voltage calculation nor the overload ceiling establishes repetitive surge
or board-lightning qualification. Dielectric withstand is a component test, not
assembled insulation approval or permission to expose this system to that voltage.

| Source-end condition | Branch mA | One resistor W | Two resistors W | Rating-only local ambient ceiling C |
| :--- | ---: | ---: | ---: | ---: |
| 36 V, nominal R / 2.8 V Vf comparison | 15.090909 | 0.501018 | 1.002036 | 133.707 |
| 36 V, 2512 SMT Rmin / zero Vf | 16.695884 | 0.601052 | 1.202104 | 129.455 |
| Legacy 37 V proposal, now 2512 SMT Rmin / zero Vf | 17.159659 | 0.634907 | 1.269815 | 128.016 |
| Current 40.39597 V screen, 2512 SMT Rmin / zero Vf | 18.734624 | 0.756803 | 1.513607 | 122.836 |

At the current upper screen, **0.7568032911 W/resistor** leaves
**1.2431967089 W below catalogue 3521 P70**. The rating-only local ambient ceiling is
**122.8358601301 C**. At 125 C ambient, allowance is only **0.7058823529 W**,
so this screen exceeds it by **0.0509209381 W**. Do not extrapolate below
70 C to permit more than 2 W, or treat the arithmetic ambient ceilings as
simultaneous safe operating points: the resistance model separately assumes
-30..125 C resistor temperature, while powered hot spots exceed ambient.
The lower calculated upper power than the retired PR02 case comes solely from
the changed TCR/reference resistance envelope, not a modeled SMT cooling benefit.

The helper still distinguishes fixed-current ceilings using **Rmax** from
voltage-fed power using **Rmin**. Its thermal-only 70 C source ceiling of
**65.669171 V** is **not** an allowed source voltage: it exceeds the cable's
60 V working rating and the LED-current screen. It neither sizes a substitute
resistor nor supplies a positive-voltage clamp. Under just the selected initial
R/TCR screen, 20 mA with zero drops corresponds to **43.1244 V**, not a hardware
OV limit, startup/aging margin or full-temperature APEM current qualification.

The nominal heat remains **1.0020363636 W in the two resistors**, plus
**0.0211272727 W** in D1/D2 at the illustrative 0.7 V each. At 2.1 V LED voltage,
two 50 uA clamp diversions move at most **0.000210 W** from the external LEDs
to D3/D4, giving **1.0233736364 W** in these PCB parts at the comparison point.
That heat is not removed by SMT mounting or the 2 W resistor rating, and clamp
leakage is not added again to the PSU current or whole-branch input budget.

**Bulk/local interfaces:** **60 C interface** and **110 C film** remain
conservative **proposed development targets**, not user hard future/all-temperature
requirements or measured temperatures. The 60 C example leaves 10 K to the
complete cable's actual 70 C limit; the old 15 K MBE film margin no longer applies.
Film, body, adjacent gel and cable-entry hot spots are different temperatures.
Measure or otherwise establish each with uncertainty; a cool bulk reading
does not establish safe cable or gel contact temperature near a hot resistor.
OneGel's conflicting service fields and missing thermal data remain as recorded
in [ENVIRONMENT_EVIDENCE](ENVIRONMENT_EVIDENCE.md#wiska-onegel); adhesive,
connector and LED limits also apply.

For the **two selected branches only**, assigning all their electrical input to
heat bounds it by **1.5136065821 W** at 40.39597 V. This already includes any
partition between resistor, series diode, LED and clamp; adding a separate
clamp-input load would double-count energy. At an illustrative 30 C outside / 60 C
bulk target, allowable **effective** bulk-to-outside resistance is at most
**19.8202097920 K/W**. At 60 C local ambient / 110 C film, the paired-load effective
film-to-local allowance is **66.0673659733 K/W per resistor**. These are required
heat-rejection capabilities, **not OneGel properties or self-heating claims**.
Add through-contact/auxiliary heat, mutual heating and solar exposure before
using the budget for a real enclosure. 30 C observed outdoor ambient is not a
guaranteed design maximum. No normal TEST timer substitutes for this envelope.

Actual 2512 SMT chip/pad/PCB and adjacent-material temperatures are not calculated
from an assumed package K/W. Instrumented steady-state evidence with both
branches, solar exposure and output-short conditions remains a separate physical
qualification activity, not a new prerequisite imposed on prototype exports.

**Historical only:** the retired PR02 calculation used +/-250 ppm/K and a 20 C
reference, giving **2120.8275..2280.3275 ohm** and **0.7694328710 W** at the upper
source screen. Its **220 C hot-spot limit, typical 75 K/W mounted example and
>=1 mm body standoff** [7] belong to that axial part, not 2512 SMT. The old example's
**57.7074653257 K rise** is not retained as an SMT or OneGel prediction.
The named historical regression also retains the former MBE **2166.5655 ohm**
minimum, **0.631876 W at 37 V** and **0.753190 W at 40.39597 V**, with its
**0.65 W standard / 1 W power rating modes** [6], rather than
calling them 2512 limits. Neither retired resistor's analysis was physical qualification;
their 20 C arithmetic is explicit in the historical test, not a compatibility
mode in the selected-part helpers.

## AC Conversion Copper Screen

**2026-09-14, 1.2.1-dev approved westward geometry, not a current or surge rating.**
[ELECTRICAL: SMT AC Conversion](ELECTRICAL.md#smt-ac-conversion) records the
front B cutback, **exactly 6.00 mm rear B**, minimal return-stem shift,
single-layer A/C stubs and retained six-path connectivity.
Assembly/DFM, not this arithmetic, controls
actual copper, laminate and process acceptance under
[Physical Guardrails](ASSEMBLY.md#physical-guardrails).

Compare equal-length uniform conductors of the same material at the same
initial temperature, using **nominal 0.070 mm surface copper**. The reference
is the old **ideal equal-sharing pair of 3.20 mm rails**, or one ideal
**6.40 mm** strip of the same thickness, **not the selected rear width**:

```text
S_old_ideal = 2 * 3.20 * 0.070 = 0.448 mm^2
S_rear_B   =     6.00 * 0.070 = 0.420 mm^2
S_rear_B / S_old_ideal = 0.9375
R_rear_B / R_old_ideal = 0.448 / 0.420 = 16/15 ~= 1.0666667
DeltaT_rear_B / DeltaT_old_ideal = (0.448 / 0.420)^2 = 256/225 ~= 1.1377778
```

Thus 6.00 mm retains **93.75% of the reference metal area**, with **6.6667%
higher fixed-temperature resistance**. The **13.7778% higher low-rise adiabatic
temperature rise** assumes the same total-current waveform/integral of I^2 dt,
uniform current distribution, constant resistivity/heat capacity and negligible
cooling during that rise. It is a cross-section ratio, not a prediction of
actual pulse temperature, fusing, lifetime or equal transient sharing in the
old dual-layer path. No pulse amplitude or site exposure is selected here.

The last dedicated B stitching via at **X=112.00** and retained GDT_B_E
core-side PTH at **X=131.00** bound the **19.00 mm rear strip** used in this
separate resistance estimate. This idealized length between interlayer datums
does not imply that front copper is absent throughout the interval or that all
current takes this path. With **assumed annealed-copper resistivity at
20 C of 1.724e-8 ohm*m**:

```text
L_strip = (131.00 - 112.00) mm = 19.00 mm
R_strip_20 = rho_20 * L_strip / S_rear_B
           = (1.724e-8 ohm*m) * (19.00e-3 m) / (0.420e-6 m^2)
           = 0.000779904762... ohm = 0.779905... milliohm
```

**Historical 1.2.0-dev comparison:** the former last B via at X=115.50 gave
15.50 mm and **0.636238095 milliohm** under the same assumptions. The approved
westward via move lengthens this modelled strip; the cross-section ratios above
remain unchanged. Neither number is a measured whole-path resistance.

This is **only that uniform strip**, not whole-path impedance or a guaranteed
finished-copper, pin, solder or plated-barrel model. Existing component PTH
leads/solder connect both layers as well as the dedicated stitches; **not all
current is forced solely through the three B via barrels**. Removing the two
AC PTHs removes those particular A/C interlayer links, not the remaining
dedicated stitches, input and earth-GDT links. The new A/C stubs are also
single-layer and cannot be credited with the old dual-layer area. Current
crowding, inductance, real interlayer sharing, joints/barrel copper and actual
thermal spreading remain outside these formulas. Do not credit other GDTs
with guaranteed sharing to reduce stress in this path.

The historical ignored `tmp/gdt-ac-smt-analysis-2026-09-14.py` (repository-only
scratch evidence) compared **3.20/6.40 mm only**; it does **not** validate the
selected 6.00 mm strip. The normal DC scripts, current screens and TE resistor
loss/thermal results above remain unchanged; their model checks do not verify
the copper's actual pulse performance. Widening B
does not establish resistor cooling or OneGel/continuous-duty qualification;
the new front/laminate insulation path and all **C4/C5/W3/W1/W4** and
production/field holds remain open.

## Fault Screen

The existing solver supplies only selected AB/CB prospective CV examples,
with explicitly illustrative **0.25 ohm source series R** and **0.1 ohm arc
slope**. At 40.39597 V / declared cable / zero-Vf 2512 SMT Rmin loads, a near-source
100 ohm fault dissipates **16.0526650917 W** at **0.4006577728 A in the fault**
with just **1.3207708739 A total**, below even the healthy upper envelope.
A hub overcurrent threshold is not complete coverage.
The near-source ideal short's **161.58388 A** is invalid CV demand, not LRS current.

The same far-end 10 V arc case with the selected load gives
**0.1308380267 A / 1.3100921262 W** in the path and **0.9769095285 A total**.
Neither it nor the higher old nominal arc value below is a maximum over
cable/load/fault conditions or evidence of
improved physical recovery. D3/D4 do not alter the upstream GDT paths.

K.12's known 135 V / 1300 ohm DC-feed comparison is retained from
[SOURCE_PROTECTION_RESEARCH](SOURCE_PROTECTION_RESEARCH.md#2-what-holdover-actually-specifies),
sections 2/9 [N1,N2]. Ignoring the test diode
drop gives **103.846 / 96.154 / 92.308 mA** at **0 / 10 / 15 V**. The old
nominal far 10 V arc remains **0.259543 A / 2.602168 W**. Ratios in the new CLI
use the actual modeled terminal voltage, including arc slope, not just its
10 V knee. A simple 40.39597 V source would need at least **388.9982296296 ohm**
for this sufficient pointwise DC-feed dominance, not an acceptable rail-resistor design.
This does not prove dynamic extinction or non-extinction; K.12 also has surge/
RC conditions and does not qualify this powered fence by voltage comparison.
The **0.256 W** bound for a <=0.1 ohm failed-short path requires an **actually
enforced 1.6 A** ceiling and does not cover resistive damage or external energy.
That is an unimplemented historical source proposal, not a newly required
active stage or a safety limit imposed by this update.

**C4 mechanism, not transient approval:** D3/D4 provide an ordinary forward
conduction path for negative LED-connector voltage. BYG23T's datasheet forward
recovery is **typical 9 V peak / 620 ns at 1.5 A and 12 A/us, 25 C** [8],
**not proof of <=5 V at the LED**. The 75 ns reverse-recovery maximum is a
different test and does not fix this gap. No positive regulation or forward
pulse-current limit is introduced, and neither the 1300 V diode rating nor
the 2 W resistor label qualifies ordinary switching/RF/nearby-lightning stress.
The installation-lead reversal exclusion does not waive normal-operation safety.

## Reproduction

Repository-only commands, run from the checkout root:

```bash
TMPDIR=/tmp/opencode python3 -B scripts/design_bounds.py --json
TMPDIR=/tmp/opencode python3 -B scripts/analyze_limits.py --json
TMPDIR=/tmp/opencode python3 -B -W error -m unittest discover -s tests -p test_design_bounds.py -v
TMPDIR=/tmp/opencode python3 -B -W error -m unittest discover -s tests -p test_electrical.py -v
```

CLI output is deterministic and offline, with explicit units and no file writes.
Focused tests reuse `analyze_limits.cut_sweep` for all **280 cuts** at the updated
asymmetric corner with 50 uA ON-current diversion margin. Raw OFF currents must
still be zero; leakage subtraction cannot conceal a forward backfeed. The
original **280 nominal cuts and 615 prospective inter-core fault cases** are
retained, along with repair/retest, floating-island and legacy-topology controls.
No second network solver, full transient solver or shared-source guard is added.

On **Python 3.14.4**, the preceding **HP12** SMT-focused runs passed **23 electrical
tests and 13 design-bound tests**. Both normal `--json` CLIs exited 0; human/JSON/error
paths were also exercised by the isolated suites. These results concern only
the bounded analysis, not the concurrent PCB/production integration.

For the **earlier TE 3521 prototype synchronization on 2026-09-11**, the reproduction commands
passed on **Python 3.14.4**: **23 electrical and 13 design-bound tests, no skips**,
and both `--json` CLIs exited 0. Both CLIs also exited 0 without `--json`.
Those tests predate this evidence/provenance correction; they did not establish
the inherited TCR test conditions, overload rating or actual mounting equivalence.

For the **TE evidence/provenance correction on 2026-09-11, before deduplication**,
isolated tests on **Python 3.14.4** pass: **23 electrical +14 design-bound =37 tests, no failures
or skips**. Both read-only model commands without `--json` exit 0; JSON and
error paths also pass in the focused suites. The nominal **0.501018 W** and
upper **0.756803 W** per-resistor screens, both 280-cut sweeps and existing
615 inter-core fault cases remain unchanged. The owned-file `git diff --check`
passes. No integrated/native or physical qualification result is asserted.

Those suites cover selected 3521 catalogue rating/TCR, the **assumed** 25 C
reference/temperature screen, unknown manufacturer TCR/overload test parameters,
250/500/500 V family ceilings, working-voltage arithmetic, unverified catalogue
mounting transfer, prototype-only scope, historical named values, BYG23T
headroom, clamp diversion/blackout margin, unchanged resistor/PSU power and
nonzero clamp body heat, finite/invalid inputs, thermal arithmetic and CLI JSON.
These checks verify declared calculations, not actual LED polarity survival,
source limits, optical darkness, recovery or physical temperatures. That bounded
analysis update ran no integrated/native, manufacturing/staging, approval or
physical-qualification operation. The dated results do not extend an earlier
artifact PASS to changed note hashes; fresh integrated verification remains
separate from this documentation cleanup.

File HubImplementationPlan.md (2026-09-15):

# Hub Wiring And Protection Implementation Plan

**Reviewed and extended for C5:** 2026-09-15. **Station context:** Dog Fence 1.2.1-dev.
**Proposed subsystem:** A shed-cabinet interconnect and TEST-source protection PCB.
**Proposed directory:** `hub-pcb/`, separate from the implemented `pcb/` design.

**Status: reviewed planning document, not an approved circuit or wiring drawing.**
No hub PCB, component selection, switch pinout, surge rating or C5 closure follows
from this review. The [agreed requirements](REMEDIATION.md#agreed-requirements),
[operating matrix](INSTALL.md#functional-matrix) and
[release gates](REMEDIATION.md#release-gates) remain controlling.

## 1. Review Findings

The wiring-consolidation goal is reasonable, but the original draft mixed three
different jobs: cabinet interconnection, incoming-surge protection and interruption
of PSU-fed remote faults. One PCB may support them; one eFuse cannot establish all
three. The following findings replace the draft's implementation-ready claims.

| Priority | Finding | Required disposition |
| :--- | :--- | :--- |
| High | A 1.5 A total-current trip misses documented remote follow-current and resistive-fault cases. | Do not call the hub an arc-quenching solution or close C5. See [fault coverage](#32-remote-fault-coverage). |
| High | SMCJ58CA can exceed the TPS26600 voltage limits before it even reaches its specified clamp current. | Reject that pairing as a completed protection design; budget both power ports and control pins. See [component review](#4-component-review). |
| High | The draft promises RF neutrality and source isolation without the necessary transmitter and switch evidence. | Retain OEM protection, six independent field ends and global transfer isolation. See [RF routing](#21-smartfence-rf-routing). |
| High | Input reverse-polarity protection does not correct field-core swaps, reversed LED leads or field-side surge voltage. | Specify each fault and its safe response separately. See [polarity scope](#31-polarity-and-miswiring). |
| High | A 470 V GDT, a PE terminal and generic 3 mm spacing do not define an entrance protector or protect 60 V electronics. | Separate discharge paths and establish insulation, residual-voltage and failure-containment requirements before layout. |
| Medium | The 37 V/1.4004 A load budget, eFuse resistance/timing and resistor substitution claims are stale or incorrect. | Use current prototype bounds and exact manufacturer conditions; preserve unselected candidates as research only. |
| Medium | The proposed `build/hub/` output can be removed by the existing station transaction; sibling libraries also violate its local-project validation. | Isolate hub outputs and stage complete local dependencies; do not treat `--board hub` as a path-only change. |

**C5 planning decision:** develop a fault-tolerant TEST-source interface **plus**
qualified station recovery/failure protection and a separate cable/joint safety
case. First evaluate retention of the current stations; require an approved local
redesign wherever retention fails. A hub-only implementation is acceptable only
if the remote safety obligations are independently demonstrated, not assumed.
[Section 3](#32-remote-fault-coverage) specifies mechanisms, failure coverage and
finite decision gates; [C5 release evidence](#35-c5-limits-and-release-evidence)
defines what must be delivered before the hold can close.

## 2. Proposed Wiring

### 2.1 SmartFence RF Routing

**Recommended baseline: keep the SmartFence boundary-output pair on its OEM
protected wiring path to the rotary switch's RUN source-side contacts, not through
the TEST power electronics.** "Straight to the switch" does **not** mean bypassing
the OEM lightning/surge protector.

This recommendation assumes "antenna leads" means the two conductors connected to
the transmitter's **`LOOP` socket**. Any separate communications antenna/coax belongs
with its OEM radio equipment and should go through **neither** this switch nor an
ordinary hub-PCB terminal network. Identify the actual connector before wiring.

The [SmartFence owner's guide, Rev. E.1, June 2026][dw-guide], printed pp. 11-12,
specifies the boundary connection through its surge protector, original zip cord
to `LOOP`, and a separate `GND` connection. It does not approve this six-end selector
modification. Preserve the transmitter's OEM supply and any backup arrangement;
do not power it from the 36 V TEST source.

```text
SMARTFENCE RUN BRANCH, outside the PCB's TEST electronics:
  SmartFence LOOP pair
       <-> original OEM wiring / OEM surge protector
       <-> direct paired wiring to RUN source buses T1 and T2
                                             |
                                         RUN throws
                                             |
                                      SIX independent
                                      rotary-switch poles
                                             |
                                       six commons
                                             |
  4 km cable <-> HUB PCB: six separate field-interconnect paths
                 Start A/B/C and End A/B/C

TEST BRANCH, on a segregated section of the SAME hub PCB:
  One LRS-75-36 (+/-), existing fuse/holder pending coordination review
       -> reviewed input/reverse-polarity and port protection
       -> Q: current/OV control and reverse blocking
       -> K1 -> K2: independent normally-open two-pole DC disconnects
       -> protected TEST source harness -> TEST throws of the same switch
          positive to Start A/C throws; negative to Start B throw
          End A/B/C TEST throws remain individually unconnected

ENTRANCE PROTECTION, separate function, topology/parts not yet selected:
  Six field paths -> reviewed surge branches -> accepted earth/discharge bar
  Required PE/OEM grounds remain unswitched, outside the mode-selection paths.
```

This is a **functional proposal**, not physical terminal numbering. T1/T2 have the
meaning defined in INSTALL: protected transmitter connections. RUN grouping is
Start A/B/C to T1 and End A/B/C to T2, only on RUN source-side contacts. The OEM
protector's exact terminals, physical position and permissible switch placement
need regional OEM acceptance. A protector connected only through RUN contacts
cannot be credited with protecting the field-side switch terminals or TEST
electronics in OFF/TEST; the separate entrance stage must address those exposures.

**The six field paths on the PCB still carry RF in RUN**, even when the
transmitter-side pair bypasses the PCB. Keep these paths passive and separate
from the TEST regulator/eFuse, reverse-polarity devices, sensing returns and
control ground. Any protection or sensing branch attached to them needs loading
and isolation assessment in every mode. Do not add a blanket PE/DC-negative plane
under them without a justified coupling and insulation design.

A passive PCB route for the transmitter pair is not inherently forbidden. Regional
[DogWatch dealer evidence][dw-frequency] gives 4/8 kHz at family level, not a verified
frequency or loading allowance for the installed SmartFence. Short traces at those
frequencies are not automatically a controlled-impedance RF design problem. Direct
wiring is preferred here to minimize added interfaces and coupling to TEST circuitry.
If complete RF-harness consolidation is later wanted, use a separately reviewed
passive RF section, never the DC conditioning chain.

Neither a single-point hub clamp nor low-capacitance station GDTs prove acceptable
RF loading. Inter-core and core/earth capacitances are different network elements;
adding every capacitor as though it were across the transmitter is also invalid.
Obtain output/load limits for the exact transmitter and assess the actual cable,
station and hub network. Verify receiver coverage and loop monitoring with required
OEM protection retained in both the reference and modified configurations.

### 2.2 PCB Interfaces And Isolation

The proposed interfaces below define electrical roles, not connector pin numbers.

| Interface | Connection and constraint |
| :--- | :--- |
| PSU input | One LRS-75-36 positive/negative pair, with the existing fuse/holder subject to coordination review. The second PSU stays disconnected as a spare. |
| Protected TEST source harness | Positive split to the two Start A/C TEST throws and negative to the Start B TEST throw. A PCB positive split is permitted only within this source-side harness, not on field/common nets. |
| Switch-common harness | Six separately identified connections, one for each boundary end. No copper bus joining commons. |
| Field terminals | Six individually accessible paths: Start A, Start B, Start C, End A, End B, End C. No permanently paralleled cores or End A/C strap. |
| Surge-earth connection | Only according to the accepted discharge/bonding drawing; not a DC-negative or logic-ground connection by default. |
| Reset/status harness | Touch-safe, appropriately protected control wiring with no hidden bypass around source isolation or input reverse protection. |

Use the complete [RUN/OFF/TEST matrix](INSTALL.md#functional-matrix), not a new
matrix in this plan. OFF disconnects all six ends from the sources **at the hub**;
TEST keeps the three End connections individually open and uses the same-end feed
and return. This does not make the distributed field wiring globally voltage-free.
Preserve the WAGO through-splice/PCB-tap station architecture.

The provisional [CA10.A364/WAA364](pcb/ENVIRONMENT_EVIDENCE.md#ca10a364-switch)
has eight poles, but supplied configuration, DC application and **global
break-before-make in both directions** remain unapproved. All old-source paths
must open before any new-source path closes. Individual-pole timing, centre-off
and an eFuse's off state are not substitutes. Both TEST positive and return must
be disconnected from the field/RF branch in RUN. The two extra poles remain
unassigned; do not assume they provide reset, mode sensing or safety isolation.

Keep the 0 m and 4000 m shed-end stations as the same passive evaluation baseline
as the other 39; do not modify station CAD/BOM in this planning task. If C5 requires
local protection changes, propose them for every applicable station, not just the
two shed ends. A serviceable shed hub is a sensible place for source controls,
but a local hub arrestor does not insert a quenching element into a remote bare-GDT
path. No special-station redesign, doubled-tooling-cost claim or assumed outdoor
mounting of both shed-end boards is needed to justify this proposal.

### 2.3 Mechanical And Earthing Boundary

Target one serviceable low-voltage/field-interface PCB in a guarded cabinet,
with an appropriate 35 mm DIN carrier if accepted. The LRS chassis supply retains
its own mounting/ventilation requirements; it is not inherently DIN-mountable.
Mains distribution and required protective-earth continuity stay outside this PCB.
No required PE connection may depend on a removable ordinary PCB connector/trace.

The draft's 72/108 x 100 mm sizes, 2-layer/2 oz construction, terminal families,
1.50 mm power traces and 3.00 mm separation are **planning candidates, not approved
dimensions or insulation ratings**. Select them from thermal, fault-current,
impulse, pollution/environment, access and enclosure requirements. A 300 V connector
marking does not establish surge withstand or safe interruption; do not hot-unplug
field or power connectors unless specifically rated and authorized.

Keep the field entrance/discharge area physically separated from protected
electronics, with short, direct, suitably rated discharge connections. A reviewed
external DIN surge module may be necessary if impulse paths or failure containment
cannot be supported on the interconnect PCB. The single-PCB wiring goal must not
force high-energy diversion through small control traces or bypass OEM protection.

The qualified installer must accept the actual building PE/electrode bonding,
OEM protector/transmitter grounds and proposed shared shed-end station earth.
Do not copy US outlet-faceplate instructions into an Isle of Man installation,
add arbitrary unbonded rods, directly earth a core, bond DC negative by assumption,
or switch PE. OFF is not demonstrated storm isolation. Do not handle boundary
conductors during storms; follow [INSTALL's safety controls](INSTALL.md#safety-first).

## 3. Protection Requirements

### 3.1 Polarity And Miswiring

| Fault or mistake | Required treatment |
| :--- | :--- |
| Reversed PSU input | Block unsafe energization and protect the complete hub, including auxiliary supplies, sense pins, reset wiring and any externally referenced connections. Specify sustained-voltage/current and temperature limits. |
| Field/load drives the output above the input | Provide reverse-current blocking **and** a separate energy/clamp budget. Blocking alone does not absorb energy or protect an isolated OUT pin. |
| Negative field-side pulse or combined reversed-input/energized-output condition | Check positive and negative limits at every power/control port, including IN-to-OUT differential stress. Input reversal protection is not output surge protection. |
| Start/End or A/B/C swap, short, or wrong switch harness | Prevent with distinct/keyed connectors, permanent labels and isolated continuity checks. Input polarity protection cannot correct these errors; no automatic polarity bridge belongs in the RUN path. |
| Reversed external LED flying leads | The user's acceptance of accidental installation LED damage remains. Verify/correct polarity while isolated; this hub does not make the station LEDs reversal-proof. |
| Foreign supply or mains at a field terminal | Not covered by the nominal 36 V reverse-input function. Prevent by segregation and identification; define credible misconnection withstand/safe-failure requirements rather than imply universal protection. |

Mark field connections by **end and core**, not permanent positive/negative roles,
because all three cores carry RF in RUN. Verify the colour-to-core mapping end to
end. The supplied plain-green core is active, never PE; green/yellow is reserved
for protective earth. The accepted LED-damage risk does not waive hub/source,
earthing, continuous-duty or ordinary-transient safety.

### 3.2 Remote Fault Coverage

**C5 remains open.** Source shutdown can remove PSU follow energy only if the fault
is detected and the actual source paths open. It cannot remove all energy already
stored in the cable or delivered by an external surge.

The existing [powered-fault model](pcb/ELECTRICAL.md#4-powered-faults-c5-open)
already supplies counterexamples to the proposed 1.5 A trip. The following are
conditional DC calculations: 36 V, 41 stations, 27.6 ohm per 4 km core,
2200 ohm/2.8 V branches, 0.25 ohm source-path resistance, and 0.1 ohm slope for
the assumed ignited arcs. They are not measured tube behavior or a dynamic PSU model.

| Modeled AB fault | Total source A | Fault-path A | Fault-path W |
| :--- | ---: | ---: | ---: |
| 10 V ignited arc at 4 km | 0.979810 | 0.259543 | 2.602168 |
| 15 V ignited arc at 4 km | 0.913626 | 0.134598 | 2.020787 |
| 100 ohm fault at 0 km | 1.197071 | 0.357007 | 12.745423 |
| Hard short at 4 km | 1.112913 | 0.507648 | 0 ideal, excluding real contact resistance |

The current [upper-screen fault case](pcb/DESIGN_BOUNDS.md#fault-screen) is also
material: at **40.39597 V**, the declared hot cable/contact corner and zero-Vf
TE R-min loads, a near-source 100 ohm AB fault dissipates **16.052665 W** at only
**1.320771 A total**. This is a separate model case, not a measured worst case
or a reason to reuse the nominal table's inputs for every result.

All are below 1.5 A; some dissipate material local power without reaching either
the eFuse threshold or PSU overload. Normal and fault current ranges overlap.
Lowering a threshold, detecting a current step, or memorizing an assumed healthy
startup load does not establish complete coverage of a cable being tested for damage.
An AC short can also mask a cut without drawing significant additional current.

Do not infer certain holdover or certain extinction from these calculations.
The original "36 V above 135 V" statement was arithmetically wrong. Current Ruilon
data gives typical arc/glow test points of **15 V at 1 A / 135 V at 10 mA** for
SMD5050-470NA and **10 V / 60 V** at those currents for 2R470TD-8. Those are not a
10-50 mA holding-current specification or a 10-100 ms recovery guarantee. The
separate telecom holdover test network is discussed in
[SOURCE_PROTECTION_RESEARCH](pcb/SOURCE_PROTECTION_RESEARCH.md#2-what-holdover-actually-specifies).

Nor is exceeding 2 A a prompt fuse trip: the selected 2 A Littelfuse 217 specifies
**60 minutes minimum at 3 A** under its test conditions. LRS-75 overload is
**110-150% of rated power**, with unestablished actual hiccup/clearing waveforms.
The existing fuse/holder is intended as backup wiring protection, pending
coordination review, not as a remote-arc detector.

#### C5 Resolution Path

Address three independent obligations. Passing the first is not permission to
skip the other two. The proposed default is **retain-and-qualify**, with a required
retain-or-redesign decision before field design freeze, not indefinite research
followed by an unqualified installation.

| Obligation | Exit for retaining the current station/installation | Required response if the exit is not met |
| :--- | :--- | :--- |
| **Powered GDT recovery** | The actual Ruilon population recovers, or undergoes credited safe interruption, within accepted voltage/current/energy/temperature limits on every relevant powered path, including post-stress conditions. | Evaluate the supported DC-recovery cells below or qualified local interruption. Change every affected path; a new device only at the hub leaves remote bare paths intact. |
| **Damaged station/protector safety** | Each credible failed-open, failed-short, intermediate-resistance or tracking state is benign continuously, or a qualified safeguard interrupts/contains it before its limits are exceeded. Include joints, PCB/taps and adjacent materials, not just the tube body. | Prefer qualified local thermal opening at the hazardous path. If no suitable branch assembly can be established, propose a reviewed local module or station redesign. Healthy-tube extinction is not this evidence. |
| **Cable and splice safety** | Credible hazardous shunt and series faults are detectably outside permitted observations before damage, or have a demonstrated benign continuous thermal/containment envelope. | Require an approved spatial sensing/local-protection or cable/installation change. Station GDT protection cannot stand in for protection of the intervening cable. |

The designer and qualified laboratory must define the credible fault set and
abnormal-condition limits from actual materials and exposure. This is not a demand
to detect every infinitesimal leakage or survive arbitrary simultaneous failures.
It must include faults present before TEST starts, faults developing during TEST,
credible common-cause surge damage and failure of a credited protective element.
Neither a successful nominal run nor the user's acceptance of direct-strike
rebuilding removes those obligations.

If a hazardous class is unobservable at the hub and unprotected locally, **C5 cannot
close while station/installation changes are prohibited**. The required output is
a specific approval request describing the necessary change and its impacts, not
a lower current threshold or a claim that supervision makes the fault harmless.
The current station Gate P files remain usable for their authorized evaluation
scope; no station geometry, BOM or field wiring changes are authorized here.

#### Detection Credit

Use instrumentation for the functions it can demonstrate. Do not add increasingly
complicated hub sensing without a measurable separation margin between permitted
operation, including all required clean cuts, and hazardous states.

| Technique | Useful function | Coverage limitation |
| :--- | :--- | :--- |
| Total-current/current-limit trip | Gross overload and some shorts | Misses the documented sub-rated faults. Total-energy accumulation without an independent fault decision would eventually stop healthy continuous TEST. |
| Separate A/C feed measurements | Diagnostics and validated abnormal-current patterns | Clean cuts legitimately create imbalance; symmetrical faults can remain balanced. Fault current can replace some indicator current instead of adding its full value to source current. |
| Residual current, `I_A + I_C - I_B` | Returns outside the monitored conductors | AB/BC paths and two-tube earth loops can have zero residual while heating. It is not a differential-fault or universal earth-fault detector. |
| Surge/voltage/current event latch | Fast shutdown for demonstrated event classes | A remote event can be attenuated or missed; an existing resistive fault need not create a detectable event. Do not credit every station merely because a hub clamp has an event output. |
| ADC/model comparison or startup baseline | Characterization of a bounded network | Resolution cannot remove model ambiguity. Never learn a possibly damaged cable as the healthy reference or attach shared-reference End sensing that creates a hidden return. |
| Local thermal sensing/opening | Acts on heat that hub electrical readings may miss | Must cover the real hot spot with qualified response, coupling, power/failure behavior and interruption. A bulk box-temperature sensor or communications heartbeat alone is insufficient. |

Periodic blanking, polarity alternation or diagnostic voltage excursions are
**not** the baseline solution. They change the TEST waveform/topology and need
explicit approval and renewed functional/transient qualification. Periodic arc
quenching would still not remove a permanent resistive fault; repeated reapplication
can repeat its heating. Normal TEST remains steady, continuous-safe DC with no
session timeout or automatic retry into a known fault.

#### Local Recovery And Failure Protection

Use these ordered evaluation routes, not an interchangeable protection BOM:

| Route | Basis and design action | Limit that must still be closed |
| :--- | :--- | :--- |
| **1. Retain Ruilon** | Request an application envelope for SMD5050-470NA and 2R470TD-8, then perform bounded powered type tests where necessary. Record actual source/cable RLC, recovery voltage, temperature, both pulse polarities, life conditioning, residual current and restart conditions. | [SMD5050 A3][ruilon-smt] and [2RD-8 A6][ruilon-earth] do not supply a powered extinction-time/network guarantee. Check supplied-lot applicability; neither typical arc/glow data nor post-reflow recovery language supplies it. Damaged-device safety is separate. |
| **2. DC-rated stack fallback** | Evaluate **TDK LN8-A1200DC-4 / B88069X1993B501**, version 05, 2019-07-25, with its exact three-capacitor network in each affected path. [The manufacturer][tdk-dc-stack] specifies 48 V +/-20% DC with a **30 A DC-source condition**. This is the preferred already-supported recovery fallback where primary surge capability and a mechanical redesign are acceptable. | Compare the actual source and stored-energy network with the specified test circuit; do not infer arbitrary dynamic recovery. With its capacitors, front voltage is <850 V initially but <1600 V after life under the stated test, not automatically better insulation coordination. Include capacitor/stack failures and local damaged-state protection. |
| **3. Series GDT/MOV alternative** | Evaluate **Bourns GMOV-14D500K** or an equivalently supported series cell if its actual surge/thermal envelope is accepted. The MOV supports the DC voltage after the surge rather than leaving only a bare arc path. | GMOV has **no thermal fuse** according to the [manufacturer's explanation][gmov-failure]. A shorted MOV returns the bare-GDT problem; common-cause damage can defeat both elements. Its surge ratings are not equivalent to every present station tube. Recovery does not close damaged-device containment. |

The detailed historical cells are in
[SOURCE_PROTECTION_RESEARCH](pcb/SOURCE_PROTECTION_RESEARCH.md#4-dc-power-and-mov-alternatives).
They are not current station assemblies. Do not leave an original bare tube in
parallel with a replacement cell, put a blocking element only in the external
EARTH lead, reuse retired AC holes, or treat a carrier as automatically compliant
with [the current physical guardrails](pcb/ASSEMBLY.md#physical-guardrails).

**Preferred damaged-device mechanism: a qualified local opening assembly.** Place
the interruption in the actual surge/fault branch, with thermal coupling to every
credited heat source. It must carry the specified surge waveform/charge/repetition,
interrupt the full DC recovery voltage and relevant current/inductance, operate
before adjacent materials exceed their limits, and remain safely open without
tracking, restrike or hazardous leakage. Qualify aging, soldering, OneGel exposure,
mechanical movement and loss-of-protection indication/service. No reviewed generic
thermal fuse or the previously suggested TMOV establishes this combined duty.

A guaranteed low-resistance fail-short mechanism is an alternative **only** with
limits for pre-activation temperature, final resistance and continuous connection
heating, including low-power faults that might never activate it. Its diagnostic
masking and core/EARTH consequences need explicit acceptance. Do not turn that
fault disposition into an intentional direct core-earth bond. A TCO in a surge
branch is distinct from the required PE conductor: **PE is never opened**.

If branch-local protection cannot be qualified, an alternative proposal is a local
module disconnecting all three **station taps**, leaving WAGO through-splices
intact. It still needs actual sensor coverage, DC/impulse interruption and fit
review; it is a station wiring/protection change, not a hub-only fix. It cannot
isolate a fault in the through-cable or splice. No such module is selected here.

#### Fault Coverage Matrix

For each row, record the exact credited mechanism, numerical limits, failure
assumptions, test/report identifier and final service disposition. A proposed
mechanism or a blank evidence cell is **HELD**, not PASS.

| Fault class | Required coverage and discriminator |
| :--- | :--- |
| AB/BC ignition | Independently qualify both paths' recovery or local interruption over source/cable/load asymmetry. Below-threshold follow current cannot rely on hub overcurrent. |
| AC ignition or short | Include asymmetry, cuts and other fired/failed paths. Equipotential A/C in one healthy case is not universal safety; a short can mask a later cut. |
| Intermediate-resistance GDT/cell/PCB/tap fault | Sweep resistance and location, including the documented multiwatt cases. Demonstrate benign temperature or effective local interruption/detection, not just intact-GDT recovery. |
| Single core/EARTH path | Bound actual leakage, capacitance, common-mode and external energy. Zero steady DC in an ideally floating circuit is not zero voltage or touch-safety evidence. |
| Two earth tubes sharing an unwired EARTH node | Treat as AB/BC/AC differential paths. An external earth-lead device is bypassed; residual-current balance can remain zero. |
| Earth paths between stations | Test actual source/return combinations and site impedances, unequal sharing and one tube already failed short. A surviving element may see full recovery voltage; no DC-negative/PE bond is needed to form the loop. |
| Stable failed-short component | Bound real device/joint resistance and continuous temperature under the actual current ceiling and protective-failure envelope. Zero-ohm model dissipation is not real thermal evidence; record diagnostic masking and replacement. |
| Failed-open protector/local release | Demonstrate safe loss-of-protection indication and a service restriction before renewed reliance. An open DMM reading does not prove a functional arrester. |
| Clean cuts; cuts plus other faults | Preserve all 280 clean-cut diagnoses without tripping simply for low load/imbalance. Apply fault-safety criteria to remaining energized paths in mixed cases; localization may be ambiguous and islands may remain charged. |
| Cable shunt or concentrated series/joint fault | Apply the separate cable safety case below. Current can decrease; local station protection and residual-current sensing cannot cover every such fault. |
| Q shorted; one disconnect or driver stuck closed | The surviving independent shutdown path must remove both TEST source conductors within its accepted energy/time limits. Include upstream PSU capacitance and actual current, not the failed Q's nominal limit. |
| Sensor/reference/controller failure; source OV/dropout | Fault analysis must demonstrate release despite a stuck controller, missing/plausible-stuck sensor, reference fault or repeated hiccup. Shared surge damage and other common causes cannot be labelled independent. |
| Fault before startup; reset held or supply cycled | Startup protections remain active; no automatic re-energization or repeated reset attempts into the fault. Verify a new deliberate reset action and disconnect feedback. |
| Selector contact remains connected | Exact selector/interlock design must prevent unsafe RF/TEST connection. K1/K2 interrupt TEST only and cannot be credited with opening a welded RUN path; obtain an accepted interlock or separately reviewed source-isolation change if needed. |
| External surge/earth rise | Use the coordinated entrance/local discharge and insulation design in all modes. Removing TEST power does not remove externally supplied energy; direct-strike rebuilding is not blanket nearby-event acceptance. |

#### Cable And Joint Coverage

Electrical terminal measurements determine aggregate behavior, not the spatial
distribution of heating. Within a span, the same series resistance can be
distributed through sound cable or concentrated at a bad joint. Establish whether
the observationally overlapping cases are thermally benign; do not infer that
they are harmless from low total current or that every small resistance is hazardous.

If a hazardous cable class cannot be separated with adequate margin, the release
decision must require a qualified physical containment/installation solution or
additional spatial protection. Per-span current comparison could address some
shunt faults, but not every series hot spot; a station thermometer does not monitor
100 m of cable. Any sensing/power/communications design credited for shutdown must
survive the core cuts that TEST is required to diagnose, or provide another safe
means of completing that diagnosis. Do not silently introduce a new feed, a fourth
conductor, wireless safety dependence or a changed TEST waveform. Those need a
specific proposal and user approval.

Use the existing
[failure-coverage record](pcb/SOURCE_PROTECTION_RESEARCH.md#6-failure-coverage-and-prototype-boundary)
as supporting evidence. Recovery, damaged-station safety and cable/joint coverage
must all have accepted dispositions before claiming full C5 closure.

### 3.3 Surge Coordination

Separate these functions in the circuit and acceptance records:

| Function | Boundary |
| :--- | :--- |
| Field-entrance surge diversion | Six distinct field connections; differential and common-mode exposure in RUN/OFF/TEST and during transfer. Must not introduce permanent end ties. |
| OEM transmitter protection | Retained OEM arrangement in the RF branch; not replaced or qualified by the custom hub. |
| TEST electronics protection and shutdown | Positive/negative surges at IN and OUT, control-pin stresses, stored energy, reverse energy, follow current and independent interruption if a semiconductor fails short. |

A **series** GDT/MOV branch and a **parallel** GDT/MOV pair are not interchangeable.
A series MOV can limit follow current in its own branch; a parallel MOV does not
insert impedance into a conducting bare-GDT path. A hub hybrid also leaves remote
bare paths unchanged. Specify firing/clamp coordination and failed-device behavior,
not "series or parallel" as an assembly choice.

MOV capacitance, TVS pulse capability and thermal failure behavior are part-specific.
The draft's blanket station-MOV prohibition and 20-50 A 8/20 us limit for all SMT
TVSs are withdrawn. Small TVSs can be coordinated secondary protection, not assumed
replacements for a high-energy primary. Do not sum all 246 protection capacitances
as one transmitter shunt or assume incident kA currents from GDT component ratings.
A shunt across an LED alone still does not guarantee forward pulse-current control.

Specify residual voltage and energy at the switch, cable, connectors, PCB barriers
and electronics, including lead inductance and clamp tolerances. The cable's 60 V
DC service rating is not impulse withstand; the station GDTs' specified impulse
sparkover can reach 950/1100 V at 1 kV/us. Neither those parts nor a new hub are
qualified by nominal 3 mm gaps, solder mask, gel, copper thickness or kA labels.
Direct-strike survival is not required; ordinary switching/RF and a defined
nearby-lightning scope remain. The entire-boundary energized-cattle-fence
prohibition remains, not a test configuration to reintroduce.

### 3.4 Source Control And Operator State

Recalculate normal input/output limits using
[DESIGN_BOUNDS](pcb/DESIGN_BOUNDS.md#evidence-and-inputs), including hub/contact
losses and auxiliary power. The current TE prototype zero-drop/R-min upper screen
is **1.536239 A at 40.39597 V**, before new bypass/auxiliary loads. This voltage is
a declared adjustment/tolerance screen, not an enforced or guaranteed maximum.
The draft's **1.4004 A at 37 V** came from a historical resistor model; neither that
load budget nor the historical 35-37 V window is the current source specification.

Do not freeze 8 kohm current programming, 36.8 V OV or 30 V UV thresholds yet.
Choose operating and fault limits with tolerance, startup, ripple, thermal and
visibility margins. Qualifying the actual normal source range is an alternative
to a precision operating cutoff; source-malfunction protection still needs review.
A lower cutoff alone does not qualify closed-OneGel station temperatures.

#### Independent Shutdown

Adopt the following **functional design target**, not a selected relay/controller
BOM: a single credited protective-device failure must not defeat TEST-source
energy removal, and one welded disconnect must not defeat two-conductor TEST
isolation. Use **Q plus two independently driven, normally-open, two-pole DC
disconnects K1 and K2 in series**. Each disconnect opens positive before its A/C
split and negative before the Start B source contact. One relay plus Q alone is
not redundant galvanic isolation of both conductors under a welded-contact fault.

Q supplies fast limiting/reverse blocking/shutdown. Two protection channels must
be able to release their respective K devices without permission from a common
MCU; each also requests Q shutdown and fault latching. Provide independent
source/output OV supervision and the required fault/health inputs with separate
references/release paths. Shared PSU loss must de-energize the system safely.
Diagnostic software may inhibit or request shutdown, but cannot override a trip.
Do not derive both release channels solely from Q's `FLT` output: a failure of Q
or that signal must not erase the only detection needed to operate the surviving
disconnect. Verify each credited trigger through its applicable independent path.
Detection credit remains limited by the matrix above: duplicating an overcurrent
detector does not detect the sub-rated faults.

Specify actual DC breaking/current/voltage/inductance ratings, contact feedback,
driver failure behavior, coil-suppression release delay and proof-test method.
Prove each isolation path without removing the remaining field-isolation barrier.
Review common-cause surge/contamination, shared-reference faults, and bypasses
through sensing, fuse-holder indicators, auxiliary wiring or test instruments.
Two copies sharing a vulnerable node are not independent protection. External
approved DIN hardware is acceptable where PCB hardware cannot meet the duty.
No SIL/PL or certified functional-safety claim follows from this block diagram.

The exact selector/interlock remains part of the safety case. TEST-position
feedback alone does not prove every RF contact is open. Establish the accepted
mode/isolation proof without assigning spare poles or modifying OEM RF protection
in this plan; if the chosen fault contract needs additional RF isolation, obtain
its separate OEM/design approval.

#### State And Reset Contract

| State | Required behavior |
| :--- | :--- |
| Unarmed | Q disabled, K1/K2 released after initial power-up, brownout/control loss or leaving the permitted mode. Source restoration alone cannot enable TEST. |
| Precheck | Require verified TEST isolation, valid source/references/protection, released reset button and satisfactory disconnect feedback. Do not require a healthy-cable current signature that rejects legitimate cuts. A known fault requires inspection/disposition before reset. |
| Startup | One deliberately requested, energy-bounded transition to normal TEST. Independent OV/OC and local safeguards remain active; bound any device-specific startup flag masking and maximum startup duration. Failure to establish the expected state latches off. |
| TEST enabled | Steady DC, continuous-safe within the qualified normal envelope. Valid clean cuts remain diagnosable; no periodic blanking or session timeout. All credited fault channels remain active. |
| Tripped | Disable Q and release K1/K2, verify the expected contact/output state, record the reason and inhibit retry. Discharge only nodes actually connected to the reviewed discharge network. Persistent feedback failure inhibits reset. |
| Reset | Require fault disposition, valid source/mode, protection readiness and a fresh release-then-press action. A held button, cleared fault flag or mains power cycle is not permission for repeated re-energization. Reset never selects RUN automatically. |

Retain fault/service information across power loss where needed to enforce the
reset restriction. Specify how physical inspection/authorization is recorded;
do not make a fleeting fault LED the only record of a known damaged protector.

Opening a pass FET does not actively force its output to zero. Budget cable/hub
capacitance, inductance, turn-off overshoot and upstream energy through a failed
switch, then establish interruption time, discharge and recovery before reset.
Use measured or justified conservative bounds and `integral(v*i*dt)`; do not assign
an arbitrary safe arc duration. A fault-triggered shutdown is not a timer on healthy
TEST, which must remain continuous-safe.

Label power indication **TEST SOURCE AVAILABLE/ENABLED**, as appropriate to what
is actually sensed, and **TEST FAULT/TRIPPED**, not "NORMAL" or containment health.
Mode labels must independently identify TEST/OFF as **NO CONTAINMENT** and require
deliberate restoration and verification of RUN. Use [INSTALL](INSTALL.md#switch-and-supply).

### 3.5 C5 Limits And Release Evidence

Replace guessed trip values with a **completed numerical fault contract** owned by
the future hub electrical record and accepted test protocol. For each credited
mechanism, specify source voltage/current versus time, permissible output/drop,
IN/OUT/control/common-mode limits, cable/source RLC and stored-energy bounds,
temperature/energy limits at the actual material interfaces, detection uncertainty,
maximum clearing time, recovery/off interval and post-fault service condition.
Record provenance and covered failures for each value. Missing limits hold the
corresponding stress test or release claim, not unrelated bounded evaluation work.

Use these design/acceptance calculations, with valid operating-region assumptions:

```text
Healthy load:
  I_limit,min > I_healthy,max + I_added_downstream,max + design_margin
  P_field + P_interface_loss + P_auxiliary <= accepted_derated_PSU_capacity

Resistive path in a valid linear/CV region:
  I_fault = V_th / (R_th + R_fault)
  P_fault = V_th^2 * R_fault / (R_th + R_fault)^2

Continuous benign-state acceptance at every affected interface:
  T_measured,max + measurement_uncertainty + uncovered_corner_allowance
      <= accepted_temperature_limit
  R_failshort,max <= P_continuous,accepted / I_fault,max^2

Detected-fault interruption:
  t_clear = t_detection + t_logic + t_actuator + t_current_extinction
  E_fault = integral(v_fault(t) * i_fault(t) dt)
  E_C = 0.5 * v^T C v; E_L = 0.5 * i^T L i
  E_stored,max + P_feed,max * t_clear + E_overshoot,max + E_external,max
      <= E_allowable
```

Use a justified local allocation or conservative total-network bound for the
energy inequality; do not double-count the same pulse/capacitor contribution.
`P_feed,max` must remain valid with the credited failed protection element.
If Q is shorted, its former current ceiling no longer bounds feed power or the
upstream PSU capacitor discharge. Check the voltage/time and temperature criteria
as well as joules; an allowable pulse energy is not continuous thermal approval.
If the remaining energy budget is nonpositive, the architecture must change.

The current conditional healthy screen is **1.536239 A / 62.057870 W**, excluding
new bypass/auxiliary loads. Do not double-count leakage already passing through
R1/R2. The old 8 kohm eFuse setting's approximately **1.4236 A minimum** does not
cover that screen. Neither the historical **1.6 A ceiling** nor **0.10 ohm failed
short** is guaranteed; their illustrative **0.256 W** must be recalculated from
the adopted source and failure envelope. Do not raise the current limit without
rechecking local fault energy and source/interface thermal margins.

For a detector credited with remote safety, demonstrate that uncertainty-expanded
permitted observations, including clean cuts, and hazardous observations are
separable **within the allowed clearing interval**. Include sensor saturation,
drift, noise, startup and fault evolution. Overlap requires local protection,
benign-state evidence or an approved requirement/design change, not more ADC bits.

For recovery, qualify the actual current/voltage trajectory, restart conditions
and off time. A lumped `R*C*ln(V_initial/V_reset)` discharge estimate applies only
to the connected network it models, not every cut island or externally charged
core. Neither K.12's 150 ms nor a proposed 10-100 ms interval is a universal safe
duration. Use [the existing energy analysis](pcb/SOURCE_PROTECTION_RESEARCH.md#7-cable-and-source-energy-bounds)
for the distinction between source-fed, stored and external energy.

**Required closure deliverables:**

| Deliverable | Owner and completion criterion |
| :--- | :--- |
| Fault contract | Electrical designer plus qualified reviewer/lab: accepted numerical bounds, credible faults/common causes, safety functions and test stop conditions. No safety-critical TBD remains for the claimed scope. |
| Station retain-or-redesign report | Protection/assembly engineer plus lab: separate recovery and damaged-state evidence for the actual population/process. A failure produces a specific local-change proposal and renewed affected checks, not automatic retention. |
| Cable/joint coverage report | Electrical/site reviewer: demonstrate detector margins or benign physical bounds for each hazardous class. Otherwise specify the required spatial/installation change and obtain approval. |
| Hub implementation package | Hub designer: actual Q/K1/K2/control/port-protection circuit, tolerances, state transitions, failure analysis, single-path proof tests and source/thermal/energy budgets. An unimplemented block diagram does not complete this deliverable. |
| Integrated qualification and service record | Qualified lab/site reviewer: each fault-matrix row linked to actual measurements, protective-failure tests, uncertainty and accepted recovery/replacement/return-to-service instructions; preserve failures and sample history. |

Only after those deliverables support the implemented revision may the design
owner propose evidence-backed C5 closure in REMEDIATION and the machine ledger.
An independently aborted recovery test is a failed DUT recovery result unless a
different **implemented and credited** safeguard achieved the required safe
outcome; the laboratory abort is never that production safeguard. Preserve
separate C4/W3/site/supplier holds. A bounded prototype may defer qualification
explicitly, but full C5 closure cannot contain an unprotected hazardous class.

## 4. Component Review

These corrections retain candidate identities for traceability, not as a hub BOM.

| Draft candidate or claim | Reviewed correction and remaining work |
| :--- | :--- |
| **TPS26600PWPR**, 40 milliohm / <=0.10 W | [TI SLVSDG2G][ti-tps2660] specifies total `R_ON` **150 milliohm typical**, 160 maximum at 25 C and 250 maximum over the specified junction-temperature range. At 1.5 A, `I^2 R` is 0.3375 W typical or 0.5625 W using the full-temperature resistance limit, not <=0.10 W. Limiting-state loss requires `(VIN-VOUT)*I` and transient thermal/SOA assessment. |
| **8.00 kohm +/-0.1% current setting** | `I_OL[A] = 12 / R_ILIM[kohm]` gives 1.50 A nominal. TI's 1.425-1.575 A limits expand to about **1.4236-1.5766 A** with resistor tolerance alone, before TCR and application allowances. Preserve the table's input/drop conditions; not a universal peak ceiling or adequate healthy-load margin. |
| **<250 ns latched disconnect** | Fast-trip response is **250 ns typical**, at roughly `1.87*I_OL + 0.015 A`, not at 1.5 A. The FET subsequently turns back on into limiting. **402 kohm MODE-to-RTN** provides latch-off only after thermal shutdown. MODE-open TPS26600 circuit-breaker operation retries; TPS26601 is a different option. An external latch must account for startup and fault-flag deglitch; no complete maximum disconnect time is established. |
| **SMCJ58CA input TVS** | [Littelfuse][lf-smcj] gives 58 V standoff, **64.4-71.2 V breakdown** and **93.6 V maximum clamp at 16.1 A, 10/1000 us, 25 C**. This is not protection for the eFuse's ordinary 62 V absolute maximum. TI's limited 70 V/10 ms/25 C allowance for IN and IN-OUT is not an unrestricted OUT allowance. Select a coordinated clamp, limiting impedance and adequately rated switch from the complete transient envelope. |
| **Series diode/FET for all polarity faults** | TPS26600 already has conditional reverse-input protection down to -60 V and reverse-current blocking; redundant series parts are not automatically needed. TI requires correct **RTN/GND** treatment: tying them together disables reverse-input protection. OUT-to-RTN remains **-0.3 to 62 V**; reverse-current blocking is not an energy rating. Protect control circuits and combined-port conditions too. |
| **REF5025ID + TLV1701, 36.8 V +/-0.2 V** | [REF5025ID][ti-ref50] has an 18 V maximum input; [TLV1701][ti-tlv1701] operates up to 36 V, with 40 V supply absolute maximum. They need an appropriately protected auxiliary rail. The historical 136.8 kohm/10 kohm divider gives **36.70 V nominal**, with a limited 36.51-36.89 V static screen, not a complete cutoff guarantee. Include bias/offset, temperature, noise, readiness, hysteresis and delay. An output-only monitor cannot validate an excessive input while disconnected before reset. |
| **MOV-14D101K / TMOV14RP115E** | Not interchangeable: [Bourns][bourns-mov] specifies **85 VDC MCOV / 165 V max clamp at 50 A** for the former; [Littelfuse][lf-tmov] specifies **150 VDC / 300 V at 50 A** for the latter. Neither clamps a 62 V power port safely by itself. TMOV's thermal function has specific abnormal-overvoltage conditions and requires containment of possible heating/arcing/venting; it is not proven 36 V damaged-GDT interruption. |
| **GMOV-14D500K station alternative** | [Bourns][bourns-gmov] describes a series GDT/MOV mechanism, not "back-EMF": 65 VDC MCOV, <=4 pF at the stated conditions, up to 800 V front-protection level and 150 V **typical** clamp. Its 16.5 mm diameter/20 mm height maxima do not establish a drop-in or prove every possible mounting impossible. No reviewed fit/recovery/containment is demonstrated; current station outline is **65 x 56 mm**, not 63 x 56. |

Use [the existing source-interface research](pcb/SOURCE_PROTECTION_RESEARCH.md#candidate-source-parts-and-behavior)
for the historical calculations and their limitations, not as permission to
populate those parts. No TVS, relay/disconnect, controller or surge branch is
selected by this review.

### Station Resistors

Do not turn the hub project into a second station BOM or resistor-selection task.
[ASSEMBLY](pcb/ASSEMBLY.md#reviewed-components) owns the implemented TE 35212K2FT
prototype population and [MATERIALS](MATERIALS.md#resistor-procurement-and-history)
owns the unimplemented Yageo production order. TE's nominal 2 W does not qualify
the actual two-layer/OneGel mounting, and prototype results do not qualify Yageo.
Keep station placement, lands, routing and topology unchanged.

Corrections to the draft's alternative table, without selecting replacements:

- **Yageo SR2512FK-7W2K2L:** [SR V.14, 2025-02-14][yageo-sr] gives 2 W for the
  7W option and **500/1000 V family working/overload ceilings**, not 200/500 V.
  Actual working voltage is also power/resistance limited. Pulse, thermal,
  land/process and source/model review remain, not "pending only W3".
- **Bourns CHP2512-FX-2201ELF / CRM2512-FX-2201ELF:** retain as unselected
  candidates. [CHP][bourns-chp] gives **250/500 V**, not 300/600 V, and mounting/
  board-temperature conditions for its 3 W rating; [CRM][bourns-crm] has a stated
  copper-area basis for 2 W. Do not transfer AEC-Q200 status from A/Q variants
  to an ordinary MPN, rank pulse margin from watts, or claim drop-in approval.
- **Vishay CRCW25122K20FKEGHP / TT PWC2512LF2K20F:** remain unselected.
  [CRCW-HP][vishay-hp]'s 1.5 W ambient and 2 W terminal-temperature conditions
  differ; [PWC][tt-pwc]'s 1.5/2 W ratings use different termination copper areas.
  Neither proves this assembly safely dissipates 0.756803 W per resistor.

`950 V / 2200 ohm` and `950^2 / 2200` are instantaneous stress screens only,
not pulse-energy, repetitive endurance or complete branch-voltage predictions.
GDT sparkover timing, clamping, overshoot and exact resistor pulse curves matter.

## 5. Implementation Sequence

The following work is **proposed**, not performed by this review. Keep a bounded
bench-evaluation scope possible without pretending unresolved field safety is
complete. Do not make this hub work a new prerequisite for station Gate P files.

### Phase 1: Interface And Protection Decisions

1. Identify the installed SmartFence/regional model, `LOOP` wiring, OEM protector,
   supply/backup and accepted earthing arrangement. Obtain acceptance of the
   nonstandard loop, selector and entrance protection; record loading limits.
2. Accept the exact switch article, factory links and DC/global-transfer application
   before assigning physical terminals. Produce a six-end harness schedule keyed
   to the canonical INSTALL matrix, including all source and sensing connections.
3. Complete the [C5 fault contract](#35-c5-limits-and-release-evidence) before
   selecting limits or crediting a detector. Establish the independently protected
   fixture scope, numerical stop conditions and sufficient sample allocation.
4. Execute the station retain-or-redesign decision and the separate cable/joint
   coverage assessment. Request approval for any necessary local or installation
   changes; do not freeze a hub-only field design with those obligations unresolved.
5. Implement the proposed independent shutdown/state architecture using actual
   parts and accepted port, thermal and insulation budgets. Complete the hub and
   remote coverage records before claiming a C5-complete design. Bounded prototypes
   can carry explicit qualification deferrals; no board size or arbitrary trip
   threshold substitutes for a resolved protection mechanism.

### Phase 2: Hub Sources And Layout

1. Create `hub-pcb/hub.kicad_pro`, `.kicad_sch`, `.kicad_pcb`, `.kicad_dru`,
   local library tables/definitions, reviewed `BOM.csv` and a hub-specific
   `verification.json`. Use conventional numbered references where practicable;
   station diagnostic exceptions/approval hashes do not authorize hub warnings.
2. Keep libraries within the complete staged hub project using `${KIPRJMOD}`.
   Do not depend on `${KIPRJMOD}/../pcb/DogFence.pretty`: the current validator
   rejects that escape and an isolated hub snapshot would lack the dependency.
   Reused definitions must be deliberately reviewed and snapshotted locally.
3. Capture the field interconnect, TEST-only path, protected auxiliary power,
   Q/K1/K2 shutdown/proof-test paths and actual entrance branches as distinct
   domains. Review every connector pin, source-side tie and failure bypass.
4. Lay out to the accepted carrier, thermal and insulation requirements, with
   independent geometry guards for discharge paths, isolation, copper/drills,
   component seating and service access. Do not transfer station-specific 3 mm
   rules or footprint assumptions into a different surge assembly without review.

### Phase 3: Verification Tooling

1. Preserve existing station targets, `build/`, mirrors and release semantics.
   Prefer separate hub output/staging namespaces such as **`build-hub/`** and
   **`tmp/hub-manufacturing/`**. The station transaction quarantines/removes all
   of `build/`; merely using `build/hub/` is unsafe. Add scoped cleanup, locking
   and cross-board concurrency tests before enabling simultaneous builds.
2. Reuse tested parsing/export primitives, but explicitly separate project names,
   source/note inventories, geometry guards, net/BOM expectations, diagnostic
   reviews, manifests and mirrors. The present `scripts/manufacturing.py` is
   station-specific; a `--board` flag alone does not make its validators generic.
3. Add proposed `check-hub` and `prototype-hub` targets only after the complete
   hub pipeline exists; keep `make check` station behavior unchanged. Both
   transactions must retain strict diagnostics, pre/post source hashes, private
   exports, artifact validation and mode-specific publication gates. Hub holds
   and prototype-file authorization require their own review, not copied approval.
4. Use the CLI resolver's actually probed KiCad 9 invocation, tested here as
   `/snap/bin/kicad.kicad-cli`. Run project-aware native checks in complete
   Snap-accessible staging; retain readable and JSON reports on failure too.
   Extend unsupported geometry with tested validators, never silent exclusions.

### Phase 4: Models And Controlled Records

1. Reuse the 41-station solver, all 280 clean-cut cases and existing 615
   prospective inter-core fault cases. Add focused hub
   connectivity/state/fault tests, including both legacy backfeed/masking
   negative controls. A DC load-line test must not assert GDT extinction.
2. Test actual current/OV tolerances, auxiliary/startup/reset behavior, fast-trip
   versus latch timing, thermal loss, reversed input, energized output, shorted
   switch and port-clamp limits. Include the below-threshold faults in section 3
   as **missed by overcurrent-only protection**, not falsely passing arc-clearing
   tests. Add fault-matrix coverage for floating-EARTH bypasses, mixed cuts/faults,
   sensor/controller failures, Q short, each K/driver stuck closed, reset held,
   brownout and upstream stored energy. Sweep fault resistance/location and
   asymmetric/earth paths; do not treat the existing DC solver as a transient or
   spatial thermal model. Bench-test the actual states and single-path proof tests.
3. Create hub electrical and assembly/DFM records that own the accepted circuit,
   interface schedule, limits, source evidence and unclosed holds. Keep BOM
   identity in CAD/BOM and purchases in MATERIALS. Ship essential context within
   a self-contained hub package rather than relying only on this root plan.
4. Update INSTALL, ACCEPTANCE, RISKS, REMEDIATION and tooling guidance when an
   actual design changes their scope. Record numerical acceptance limits,
   instrumentation/uncertainty and required evidence before hardware tests.
   **Do not mark C5 resolved merely because a hub board or model exists.**

## 6. Verification And Acceptance

### File And Prototype Scope

For a separately authorized hub prototype-file release, require complete current
sources, reviewed exact population/sourcing, local libraries, native DRC/ERC with
no unreviewed warnings, full schematic/PCB/native-netlist/IPC connectivity checks,
and independent source/export geometry checks. Connectivity is compared by
terminal membership and supported coordinate tolerances, not "bit-level parity"
between unlike file formats.

Validate Gerbers/drills, signed-Y CPL, BOM, assembly data and archive contents;
require a matching hub revision/source/artifact manifest and explicit deferred
holds. Exercise failed/stale builds, mixed publication goals, scoped cleanup and
real serial/parallel publication. Rerun affected station regressions and refresh
its matching artifacts if shared tooling or controlled inputs change.

File verification does not authorize uploading, ordering, installation or surge
tests. Supplier CAM/placement, allocated parts, panel/process and received fit
acceptance are separate. The existing station Gate P does not automatically
authorize publication of a new hub design.

### Hardware And Field Scope

1. Verify the full accepted contact matrix and absence of unintended source/field
   ties with sources and field disconnected. Obtain rated DC/global-transfer
   evidence; static continuity alone cannot prove dynamic transfer isolation.
2. Qualify source loss, reversed input, reverse output energy, clamp behavior,
   independent interruption, latch/reset and continuous normal thermal duty
   against declared limits. Verify TEST/OFF labels and deliberate RUN restoration.
3. Measure RF operation with the actual transmitter/receiver and intended cable/
   station network, checking coverage, unwanted responses, branch stress and
   loop-alarm limitations. A resistor-only DC emulator is not an RF-equivalent
   4 km cable; remaining parallel cores can conceal a core break from the OEM alarm.
4. Use a qualified, independently protected fixture for powered recovery/fault/
   surge tests. Measure local branch voltage/current/temperature and energy,
   with independent abort and containment; do not rely on the hub current trip
   being evaluated. Execute every row of the C5 fault matrix and validate the
   numerical fault contract, including fresh/conditioned components, both surge
   polarities and relevant RLC/temperature/source extremes. A resistor mounted
   elsewhere is not proof of a damaged tube's internal/contact hot spot. Test
   residual energy and re-energization, and inhibit repeated restart after a
   failed test. Do not perform ad-hoc field
   lightning tests or use ordinary grounded instruments on exposed surge paths.
5. Complete all [C5 closure deliverables](#35-c5-limits-and-release-evidence),
   including the cable/joint and damaged-device reports, then close only
   evidence-supported scopes in REMEDIATION and the appropriate machine ledger.
   C4/C5/W3 and supplier/site holds remain until their actual
   criteria are met; direct-strike survival and a board-level kA rating are not
   acceptance claims.

### Review Evidence

The **initial 2026-09-15 review** changed the plan and its REMEDIATION handoff only.
It checked project requirements, source/control logic and manufacturer documents;
no schematic, PCB, BOM, library, rule, approval hash or generated artifact changed.
Retrieved PDF text supports the cited specification corrections, not fine drawing
inspection or acceptance of the actual supplied equipment.

| Command run during review | Result and scope |
| :--- | :--- |
| `python3 -B scripts/analyze_limits.py` | Exit 0; reproduced 280 clean-cut cases and the conditional below-threshold fault examples. |
| `python3 -B scripts/design_bounds.py` | Exit 0; reproduced the current TE 1.536239 A / 0.756803 W-per-resistor upper screen and its assumptions. |
| `TMPDIR=/tmp/opencode python3 -B -W error -m unittest discover -s tests -p test_electrical.py -v` | 23 tests PASS. |
| `TMPDIR=/tmp/opencode python3 -B -W error -m unittest discover -s tests -p test_design_bounds.py -v` | 14 tests PASS. |
| `git diff --check` and `git diff --no-index --check /dev/null HubImplementationPlan.md` | PASS, including the untracked plan. |
| Independent document reviews | RF/switch/earthing, protection corrections, local links and current-tooling constraints reviewed; no remaining scoped findings after removing the implied fuse-coordination approval. No full Markdown-renderer or external-link reachability test claimed. |

These are existing model regressions, not hub implementation or physical tests.
No native KiCad check or publication was run for this root-document-only review;
the existing station package was left untouched. No supplier/OEM acceptance,
upload, order, hardware qualification or issue closure is implied.

The **C5 planning follow-up on 2026-09-15** adds the three-obligation resolution
path, limited detector credit, ordered local recovery/failure alternatives,
fault matrix, Q/K1/K2 independence and state requirements, numerical acceptance
equations and five closure deliverables. This is an actionable design and
qualification plan, not a completed C5 protective circuit. Station changes remain
approval-required proposals; the existing station design and all release holds
are untouched. Follow-up verification is recorded in
[REMEDIATION](REMEDIATION.md#hub-c5-closure-planning), separately from the initial
review results above.
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

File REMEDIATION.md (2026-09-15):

# Remediation Plan

Prepared: 2026-09-06. Reviewed hardware baseline: v1.1.0.
Implementation handoff: **2026-09-15, hardware 1.2.1-dev**.

**The user-approved 2.00 mm east board extension and consistency fixes are
file-verified; fresh 1.2.1-dev Gate P prototype files are published.** See
[East Board Extension](#east-board-extension) for this source and its verification
status. [Westward GDT Spacing](#westward-gdt-spacing) and
[SMT AC Conversion](#smt-ac-conversion) preserve earlier snapshots, not
verification of the changed source or notes. The
next board priority remains the five-prototype **P3/P4 supplier queue**, not renewed
switch/environmental research. [Reviewed Components](pcb/ASSEMBLY.md#reviewed-components)
owns the implemented population and assembly limits;
[MATERIALS](MATERIALS.md#resistor-procurement-and-history) owns purchasing history.
All engineering and supplier/physical acceptance holds remain open.

This is the starting context and implementation checklist for subsequent sessions. It consolidates the review and the user's later decisions, including changes to the originally proposed TEST wiring. It is not manufacturing approval, a completed hardware test report, or a board-level lightning certification.

## Start Here

1. Read [AGENTS.md](AGENTS.md) for operating instructions and physical guardrails, then this file. Read the relevant source files before editing them.
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

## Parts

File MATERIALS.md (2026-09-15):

# Materials And Procurement Tracker

**Draft hardware revision 1.2.1-dev; reviewed baseline 1.1.0. Procurement reconciliation: 2026-09-11.**

This ledger preserves recorded **ORDERED**, **ON HAND**, existing and pending items. ORDERED alone does not mean delivered, inspected, suitable for the revised design, or allocated to a particular test/field unit. Only the user-confirmed corrections below update purchase history; this document places no order and claims no supplier allocation. Confirm receipts and usable quantities before ordering shortfalls.

The field baseline is **41 stations at 0, 100, ..., 4000 m**, including two separate shed-end boards, with **36 standard + 5 earth-connected stations** and one additional shed control hub. This ledger covers PCB procurement and external system materials; [pcb/BOM.csv](pcb/BOM.csv) controls only PCB population and sourcing metadata, not all system purchases.

**Gate P covers file-verified prototype artifacts, not upload/order authorization or allocation.** The five planned prototypes still need supplier acceptance under [ORDERING](ORDERING.md); production/field [release gates](REMEDIATION.md#release-gates) remain held. [ACCEPTANCE](ACCEPTANCE.md) controls qualification and sample use, not purchase status.

Manufacturer sources and unresolved product/process discrepancies are in [pcb/ENVIRONMENT_EVIDENCE.md](pcb/ENVIRONMENT_EVIDENCE.md). The latest reel-label and TEST/spare confirmations below supersede the research handoff's earlier open cable-identity and PSU-allocation statements.

## 1. Station Inventory

Field requirements below exclude spare/attrition quantities and additional assemblies retained or consumed by qualification.

| Item | Recorded quantity / status | 41-station requirement | Balance / qualification |
| :--- | :--- | :--- | :--- |
| PCBA | **5 prototypes planned**, no confirmed fabrication order. Earlier 40-board follow-on figure was planning, not a purchase. | **41 installed boards** | Quote five complete prototypes first; determine follow-on quantity using section 2. Standard JLCPCB two-layer FR-4 / 2 oz both sides / ENIG is available; nominal 1.6 mm, green mask default. Selected via process is **UNTENTED both sides, no fill/plug/cap**, not a special filling request. Availability is not design-specific CAM/process acceptance; no assumed high-Tg upgrade. |
| Panel LEDs | **80 APEM Q10F5SXXSG02E, ORDERED** | **82**, two per station | **Shortfall 2**, before separate prototype use/loss or spares. No-internal-resistor model, not a regulated 2 V lamp. Limits and 5 m daylight acceptance: [LED.md](LED.md). |
| Installation LED spares | **Required by the user's accepted polarity-error replacement strategy; quantity unallocated, no additional order recorded** | In addition to the 82 installed LEDs and any retained/consumed test units | Allocate before installation. The existing two-LED field shortfall is not spare stock. This acceptance concerns indicator damage from installation errors, not overheating or general surge qualification. |
| Adhesive PCB supports | **160 Essentra LCBSBM-6-01A-RT, ORDERED** | **164**, four per station | **Shortfall 4** before extra assemblies. Nominal 9.53 mm spacing, 3.18 mm support hole and 1.57 mm panel specification; obtain tolerances and verify board/box/adhesive fit. |
| Through-splice connectors | **120 WAGO 221-613, ORDERED** | **123**, three per station | **Shortfall 3** before extra assemblies. Three-way 0.5-6 mm^2 / listed 41 A component series; verify applicable conductor/termination data. Each splices incoming/outgoing core and PCB tap. |
| Junction boxes | Prior plan: **40 WISKA COMBI 308, Pending**; none recorded ordered | **41 field boxes** | All 41 remain to procure, plus any separate test/spare boxes. **PP enclosure with TPE gasket, not polycarbonate**. Nominal external 85 x 85 x 51 mm; dry-fit the complete assembly, not the PCB alone. |
| Boundary cable glands | Prior plan: **80 M20 glands/locknuts, Pending**; none recorded ordered | **82 boundary-cable entry positions** at two per field box | If both entries use glands, procure 82 correctly sized glands, **plus separately determined earth/hub entry hardware**. Select the actual WISKA-compatible gland/seal arrangement and cable diameter range, not M20 thread or an IP68 label alone. |
| OneGel | Confirmed **WISKA OneGel**, correcting the mistaken **MP0100** identity. Historical record: **approximately 7-8 litres, ORDERED**, quantity **unverified**; not a new purchase. | Old planning estimate only: **7.38-7.79 litres** for 41 boxes at **180-190 ml/box**, not a validated fill requirement | **Single-component 300 ml cartridge, 10108963; no mixing.** Reconcile cartridge count, usable yield, dispensing waste and qualified fill/test needs. Cure/temperature conflicts and material acceptance remain open; no proven surplus or assembled thermal/IP qualification. |
| Internal PCB tap wire | **Approximately 20 m, ON HAND**, spare 2.5 mm^2 cable strippings | **123 taps**, about **18.45 m of single-conductor wire** at 0.15 m/tap | Verify usable single-core length, A/B/C identification and actual routing; nominal 1.55 m remainder is before trimming, test use and waste, not reserved spare stock. Never use green/yellow for active A/B/C taps. |
| Historical WAGO Gelbox suggestions | Earlier candidates: WAGO **207-1333** size 3 or **207-1331** size 1; optional planning quantity 40 or 120, **no purchase recorded** | Not part of the agreed station baseline | **Not a supported 221-613 selection:** **207-133x is the 4 mm^2 connector series**, not a verified match for the 6 mm^2-series **221-613**. Retain as history only; no substitute, fit or allocation approved. See the environment evidence. |

WISKA's published COMBI 308 IP66 membrane / specified IP67 gland arrangements are **component/enclosure conditions**, not a tested rating for drilled LED lids and gel-filled stations. Earth wire entries may need different approved sealing hardware; do not assume multiple single cores seal in an ordinary single-cable gland. Both shed-end boxes and hub-side cable tails must be counted in the final entry drawing.

## 2. Prototype And Spare Allocation

The initial requirement is **five individual fully assembled boards**, including all SMT and THT work, 2512 SMT resistor assembly and controlled earth-GDT lead forming, with **no field soldering**. The authorized design specifies **16 electrical parts (nine SMT, seven THT)** plus four mounting footprints. Five boards therefore need **80 electrical parts before attrition**; these are design/population counts, not accepted assemblies or purchase quantities. Use the reviewed [PCB BOM](pcb/BOM.csv) for their identities and sourcing metadata.

D1-D4 remain **Vishay General Semiconductor BYG23T-M3/TR / C145454**: five boards need twenty fitted diodes before attrition; no new diode purchase is recorded.

### GDT Procurement And History

**Design-quantity update, 2026-09-14, not a purchase:** the user-approved
GDT_AC conversion selects **Ruilon SMD5050-470NA / C39692533**, the same reviewed
SMT identity as GDT_AB/BC. Five boards now require **15 fitted SMT GDTs instead
of 10, plus actual supplier-specified attrition**. The extra five fitted parts
are a requirement, not an order, receipt, stock quote or PCBA-job allocation.
Reusing the reviewed code does not establish current stock or reserve parts.

**Retired AC selection:** **Bencent B5G470L / C5337217**, formerly five fitted
positions in the five-board plan. Removing those positions and their axial
forming task does **not** cancel, return or reallocate any purchase; no such
user-confirmed transaction is recorded for this change. Preserve any actual
legacy purchase/receipt history separately from the revised requirement.

The three **Ruilon 2R470TD-8 / C2836978 earth GDTs per board** remain axial:
**15 fitted across five boards**, plus the supplier's actual attrition. Their
forming/fit/process acceptance remains open. The existing Ruilon metric/inch,
placement/stencil/profile hold also applies to the third SMT position; use
[ORDERING's process queue](ORDERING.md#3-hole-via-and-solder-process), not an
assumed approval from the repeated code. No new GDT purchase, cancellation or
allocation is claimed here.

### Resistor Procurement And History

**Active prototype BOM only:** **TE Connectivity 35212K2FT / [C4129105](https://jlcpcb.com/partdetail/C4129105)**, 2512 SMT, 2.2 kohm / 2 W / 1% / +/-100 ppm/C, AEC-Q200 qualified. In stock at JLCPCB as an Extended Part. Selected for the five prototype boards (ten fitted resistors plus supplier-defined attrition), not a recorded TE purchase or PCBA-job allocation.

**User-confirmed production order:** **Yageo SR2512FK-7W2K2L / [C876850](https://jlcpcb.com/partdetail/C876850)**. The JLCPCB listing confirms YAGEO, 2512 SMT, 2.2 kohm / 2 W / 1% / 100 ppm/C identity. The user confirms this order with an advised **20-day wait**, not receipt, inspection or PCBA-job allocation; its quantity is not established here. Do not transfer the cancelled PS12 order's 110-piece quantity to Yageo. No Yageo manufacturer mounting, thermal or pulse qualification is claimed from the identity listing.

**Corrected code history:** the earlier **C19451159** pairing with SR2512FK-7W2K2L was a documentation error, not the user's ordered part. The confirmed production order is C876850 above; the rejected pairing is not a separate purchase or a substitute.

**Historical order record, 2026-09-08:** **110 Uni-Royal PS122WF2201T4E / [C2793873](https://jlcpcb.com/partdetail/C2793873), ORDERED into the user's JLCPCB parts library**. The former shared prototype/production plan budgeted 55 two-resistor populations, not approved boards: 10 prototype plus 82 field resistors would have left 18 before attrition if prototypes were not reused. This preserves the original order and planning arithmetic, not available stock.

**Current PS12 disposition, 2026-09-11: CANCELLED AND REFUNDED** by JLCPCB due to distributor stockout. No receipt, inspection or allocation is established by the historical order. Its former 18-part arithmetic balance is not current spare stock and is not transferred to TE or Yageo.

Yageo remains a **production selection awaiting separate engineering review and integration**, not a second implemented BOM. Before production release, review its own manufacturer/rating, land-pattern, thermal, pulse and process evidence; update the controlled BOM/CAD, libraries, models and notes and reverify. TE prototype results do not establish Yageo thermal qualification. Procurement lead time does not close any engineering hold.

**Superseded, not ordered:** the prior **Uni-Royal HP122WF2201T4E**, HP12 / 2512, 2.2 kohm / 2 W / 1%, had pending `External` sourcing with no verified code. Its [SMD-SP-003 V.7 datasheet](https://www.uni-royal.cn/en/images/userfile/file/1784806233a2e6d381ea80b5d9.pdf) and [NAC Semi listing](https://store.nacsemi.com/products/detail?stock=XSJMZ0000010410), retrieved MOQ 3,600, remain historical evidence, not an order or current procurement queue. **C2791283 in commit `02661d8` is HP122WJ0472T4E, 4.7 kohm / 5%, not HP122WF2201T4E**; that mapping remains rejected and must not be renamed as PS12 history.

**Retired design/procurement history:** onsemi **1N4007G** and Vishay **MBE04140C2201FC100** preceded the PR02/BYG23T hybrid implemented after checkpoint `ad282e3`. That hybrid selected **Vishay BCcomponents PR02000202201FA100**, copper-lead PR02, 2.2 kohm / 2 W / 1% / +/-250 ppm/K, with external sourcing, no verified LCSC code and the [Vishay inventory reference](https://www.vishay.com/search?type=inv&query=PR02000202201FA100). Only **Mouser availability** was identified, not JLC allocation, purchase or reservation. **C3009798 was a rejected 220-ohm part**; the earlier PR02 **JA100** suggestion was not the selected **FA100** 1% variant. These axial selections and their forming/standoff instructions are now retired, not substitutes or current procurement tasks. Preserve any actual legacy purchase/receipt separately if confirmed; the SMT change neither invents purchases nor reallocates old parts.

Current R1/R2 metadata is **manufacturer `TE Connectivity`, MPN `35212K2FT`, C4129105, `Sourcing=LCSC`, empty `Sourcing Reference`** in the prototype BOM/CAD only. This resolves prototype resistor sourcing, not file verification or qualification. Public stock and this ledger do not set machine allocation: whole-BOM **`allocation_verified` remains `false`**. Obtain accepted PCBA-job allocation and supplier-specific attrition separately; unresolved External sourcing still blocks prototype and production publication. [REMEDIATION](REMEDIATION.md) owns file/publication results.

### Assembly And Quantity Allocation

Use the adopted [hole/pin and SMT-land controls](pcb/ASSEMBLY.md#physical-guardrails), [assembly envelopes](pcb/ASSEMBLY.md) and [DFM evidence](pcb/DFM_EVIDENCE.md) on the procurement traveller. TE 35212K2FT's **6.45 x 3.40 x 0.65 mm maximum body** fits the existing body envelope, but its recommended lands differ from the retained **alternate project lands**. Obtain supplier placement/stencil/solder acceptance for that difference, **not resistor holes, axial standoff or forming**; no exact-fit claim or geometry change follows from the TE evidence. Retained Kefa **E pin/body limits** and the independent **0.050 mm radial per-pin pattern limit for Kefa/earth GDTs** are controlled incoming requirements, not manufacturer guarantees or accepted lots. Inspect every allocated controlled-envelope part, including attrition, with uncertainty and separate pattern/body checks. W4 actual lot fit, solder fill and earth-GDT forming remain open. Apply [J_EARTH's current edge-clearance and inspection requirements](pcb/ASSEMBLY.md#earth-terminal-edge-clearance) to panel acceptance and the later complete-enclosure dry-fit; nominal in-board body/pose and courtyard margins do not approve supplier tolerances or physical fit. Physical dry-fit is not a prerequisite to generating prototype files.

- Retain at least **one unpotted reference**. Identify boards used for destructive tests, gel trials or earlier design revisions; do not automatically count them as field spares or installed boards.
- Let **p** be same-release prototypes individually accepted and allocated to the field, and **s** the explicitly approved field-spare quantity. With one retained reference, **0 <= p <= 4**; more test retention/losses can reduce p. The follow-on assembled-board requirement is **41 - p + s**. Neither p nor s is yet allocated; TE-built prototypes are not automatically same-release Yageo field units.
- Bench tests can share suitable removable LEDs/harnesses. Do not deduct the same purchased LEDs/supports/WAGOs from both a retained test box and the field inventory. Record actual consumption and recovery.
- If **q extra complete station assemblies** remain outside the 41 field units, those assemblies plus the field require **41 + q boards/boxes, 82 + 2q LEDs, 164 + 4q supports, 123 + 3q WAGOs**, and **82 + 2q boundary glands** where using two glands per box. Count any additional unboxed reference/test boards, loose harnesses, test losses, earth/hub entries, cable, gel and consumables separately. This is an allocation formula, not an order.
- As a budgeting example only, five separately boxed prototypes would use 10 LEDs, 20 supports, 15 WAGOs, five boxes, ten boundary glands and about 2.25 m of single-core tap wire. Not all five need be boxed or potted; preserve the unpotted reference and determine gel use from the test plan. Those items are **not new purchases** recorded here.

The field-only shortfalls of **2 LEDs / 4 supports / 3 WAGOs** are therefore minimums against the recorded orders, not a complete shopping list for qualification and spares. Five prototypes do not imply a purchase of five spare enclosures or ten spare LEDs.

## 3. Shed Hub Inventory

| Item | Recorded quantity / status | Current requirement / action |
| :--- | :--- | :--- |
| Previously described 4PDT centre-off switch | **1, ORDERED** in the historical record; exact received identity not verified | Preserve the purchase record, **not the old wiring design**. That description does not meet the six-independent-cable-end requirement. Keep unapproved for this function pending identity and contact review; no replacement purchase recorded. |
| Eight-pole switch candidate | **Kraus & Naimer CA10.A364**, provisional; no purchase recorded. Replaces the earlier **CA10.A362** candidate, not the recorded old-switch purchase. | Current **WAA364 (formerly A364), eight poles/eight stages, 1-0-2, 60 degrees**, not six-pole. Obtain the complete offered order code, contact development, DC load-breaking and global-transfer approval before assigning physical numbers. The six-end matrix is unchanged; **two extra poles remain unassigned**. A 20 A thermal rating is not DC or lightning-isolation approval. |
| Historical PSU description | Earlier record: **one 36 V PSU ORDERED, believed LRS-35-36**; identity was not confirmed | Preserve the belief as history, **not a separate confirmed unit or third PSU**. The current confirmed order is the two LRS-75-36s below. |
| TEST PSU and disconnected spare | **2 MEAN WELL LRS-75-36, ORDERED**, user confirmed | Each **36 V / 2.1 A / 75.6 W**. **One for TEST; second a disconnected spare**. No parallel, series, separate-channel or opposite-end feeding. Verify receipts/nameplates and qualified output settings; the order does not resolve C5 fuse/GDT coordination. |
| Fuse holder and fuses | **1 Phoenix Contact 3004139 (UK 5-HESILED 60) holder, one working fuse plus 5 spare Littelfuse 0217002.MXP fuses, ORDERED** | Historical specification is 5 x 20 mm, fast 2 A. Verify supplied parts and 36 V indicator operation. Published fuse DC interrupting capability does not demonstrate clearing of every cable-limited fault or a safe powered GDT. |
| Switchboard jumper wire | **Approximately 3 m of 2.5 mm^2 tri-rated single-core copper, ON HAND** | Check usable lengths, insulation, termination and identification against the approved six-end hub layout; no fixed unverified terminal numbering. |
| DogWatch SmartFence transmitter and protector | **1 system, Existing** | Confirm actual model, all supply/backup sources and regional OEM requirements for the proposed boundary and earthing. |
| Hub enclosure / mounting plate | **1, Pending** | Select after switch/PSU dimensions, protective segregation, terminal access, ventilation and labeling/indication requirements are established. |

The same-end TEST connection is **Start A/C positive, Start B DC negative, End A/B/C individually isolated**; RUN connects all start cores to T1 and all end cores to T2 using source-side ties. OFF isolates all six cable ends. See the [functional matrix](INSTALL.md#functional-matrix); no permanent field-end straps or unverified switch pin assignments. TEST/OFF mean the RF fence is inactive, not storm-safe isolation.

For source sizing, use [ELECTRICAL's named load cases](pcb/ELECTRICAL.md#2-calculated-results) and [DESIGN_BOUNDS](pcb/DESIGN_BOUNDS.md). Budget the working PSU for the full 41-board load, including the low-cable-resistance case, actual input/thermal derating and added protection/auxiliary loads. Five-board operation does not establish full-system capacity; the disconnected spare contributes none. Neither supply wattage nor a DC calculation resolves cable-fault clearing or powered-GDT recovery.

Those models cover the **TE-prototype / BYG23T population**, not retired-part values or unreviewed Yageo extrapolations. Their voltage screens are declared inputs, not enforced source limits or continuous-duty approval. TE's catalogue power/derating transfer from its reference mounting to this two-layer board remains unverified, not a demonstrated failure. SMT does not remove dissipated heat or prove cooler OneGel operation; procure and qualify for the intended population and actual material interfaces.

## 4. Cable And Site Materials

| Item | Identity / purchase status | Requirement / evidence |
| :--- | :--- | :--- |
| Boundary cable | User confirms actual **AMC Oceanflex CM03/05.100** reels labelled `3 CORE (3 x 35/0.30) TINNED BLACK 100 MTR`, with **red, black and PLAIN green** cores. Earlier supplier reference **P01018 / [12 Volt Planet](https://www.12voltplanet.co.uk/CAB3CTNTW2.5PNT.html)** retained. No new order recorded; total purchased/usable length still needs reconciliation. | 4 km route plus measured tails, bends, slack and installation allowance. AMC **2026 Update V.3 CM03/05 row**: **3 x 2.5 mm^2, Class 5 tinned copper, 7.4 mm maximum OD, 60 V max DC, -30 to +70 degrees C complete cable**. Identity is settled; distinguish supplied manufacturing revision/lot and conditional standard-resistance applicability below. |
| Route supports and conduit | No purchase quantity/status recorded | Survey the 0.3-1.0 m elevated timber-fence route and driveway/gate crossings. Verify exposed UV/weather suitability and wet-conduit compatibility; conduit can flood and is not electromagnetic shielding. Do not assume the cable is SWA/armoured or mains-rated. |

The older listing's 105-degree core reference is not a complete-cable rating; no -40-degree arctic or impulse-withstand claim is established. The confirmed plain-green core is not green/yellow. Record and verify A/B/C assignments end-to-end, with no green/yellow active conductor. The current V.3 sheet does not automatically establish which manufacturing revision applies to supplied stock.

Use the [conditional cable-resistance evidence](pcb/DESIGN_BOUNDS.md#evidence-and-inputs), not an assumed reel measurement or an invented AMC numerical specification. Reconcile the **0.30 mm strand label/representative construction versus the standard's 0.26 mm maximum** and applicable supplied-lot declaration before relying on the design ceiling; do not reopen settled reel identity or colours.

Select materials for the [coastal/solar/wet-route conditions](INSTALL.md#materials-and-site), including salt and condensation, not just nominal outdoor ambient. Inspect and maintain the [whole-boundary cattle-fence prohibition](INSTALL.md#cattle-fence-prohibition); changed land use or reintroduced exposure requires reassessment before use. Keep the boundary electrically separate from supporting fence wires.

## 5. Earthing Inventory

Earth-connected station locations remain 0, 1000, 2000, 3000 and 4000 m. The proposed shed connection is shared with the DogWatch protector and both shed-end boards. **Five stations do not automatically require five independent electrodes.** A qualified installer's site-specific PE/bonding design and regional OEM instructions determine installed allocation.

| Item | Recorded quantity / status | Action before installation |
| :--- | :--- | :--- |
| Copper-bonded steel rods | **5, ORDERED**. Historical requested specification: UL 467 / BS EN 62561-2, minimum 250 micrometres copper | Confirm actual manufacturer, dimensions and conformity evidence. Preserve stock; do not automatically install one unbonded rod per station or claim a service-life guarantee. |
| Rod clamps | **5, ORDERED**, described as bronze/brass B-clamps for 5/8-inch rods | Verify supplied rod diameter, conductor number/size, torque, corrosion suitability and approval. Do not assume two conductors are permitted in a clamp without its instructions. |
| Green/yellow earth wire | **Approximately 30 m total of 2.5 mm^2 6491X, ORDERED** | Historical plan used two parallel 2.5 mm^2 leads at each earth station. Final size, routing, termination and quantity are subject to the earthing/protection design; combined area is not proof of equal surge sharing or adequacy. |
| Inspection pits | **5, Pending** in the earlier plan | Final count follows actual electrode design and inspection access, not simply station count. |

The PCB's three `J_EARTH` pins are connected together; this does not create a 72 A terminal rating. Do not directly earth a fence core or assume PSU negative should be bonded to earth. Inventory ownership is not installation authorization or evidence of a qualified surge path.

## 6. Tools And Consumables

All tools below were pending in the existing ledger unless explicitly identified as an added requirement. No tool purchase is asserted.

| Tool / item | Recorded status | Use / qualification |
| :--- | :--- | :--- |
| 10 mm step drill / punch | Pending | Nominal Q10 LED cutout; use the exact indicator drawing, tolerance, seal and panel-thickness requirements. |
| Terminal screwdriver | Pending | Earlier suggested 3.0-3.5 mm flat blade; verify actual screw fit and manufacturer's terminal torque. |
| Wire strippers / cutters | Pending | Suit the cable cores and fine LED flying leads without strand damage. |
| IPA cleaning wipes | Pending | Earlier proposed support-base cleaning; verify enclosure/adhesive/gel compatibility and required preparation rather than assuming any solvent process is suitable. |
| Digital multimeter | Pending | De-energized continuity/diode checks and appropriate DC measurements per [INSTALL](INSTALL.md#optional-dmm-checks) and [ACCEPTANCE](ACCEPTANCE.md); not proof of GDT firing, tiny leakage or surge survival. |
| Outdoor labels / tags | Pending | **41 station positions, 0 to 4000 m**, A/B/C identities, LED polarity, and clear hub RUN/OFF/TEST/fence-inactive labeling. |
| Suitable torque tool for LEDs | Required; no purchase recorded | APEM mounting torque **0.20-0.25 Nm**, subject to exact supplied model instructions. Do not substitute terminal screw torque. |
| Thermal logging and qualification equipment | Required scope; no purchase recorded | Determine with ACCEPTANCE and qualified test personnel. Temperature must be measured; touch is not thermal acceptance. |

## 7. Outstanding Procurement Actions

- Confirm quantities/receipts/usable stock without inventing new orders: **user-confirmed Yageo SR2512FK-7W2K2L / C876850 order (20-day wait)**, **80 LEDs, 160 supports, 120 WAGOs**, gel, hub items, rods/clamps/wire and on-hand tap/jumper wire. Preserve the historical 110-part Uni-Royal order separately from its current cancelled/refunded status.
- Allocate prototypes, retained reference, test consumption and any spares. Field minimum shortfalls remain **2 LEDs, 4 supports and 3 WAGOs** before those allocations.
- Procure **41 field enclosures** and choose/count **82 boundary gland positions** plus approved earth/hub entries and any separately allocated test/spare boxes. These remain pending, not purchased.
- Inspect receipts/nameplates and qualified output settings for the **two ordered LRS-75-36s**, retaining **one TEST / one disconnected spare** allocation. Reconcile the old ordered switch; quote **CA10.A364/WAA364** only as a provisional eight-pole candidate, subject to DC/contact/global-transfer approval.
- Record the cable's supplied manufacturing revision/lot and total usable length; confirm conditional standard-resistance applicability and resolve the strand-construction discrepancy, alongside environmental/impulse evidence, without reopening product identity or colours.
- Reconcile OneGel cartridge count and usable yield against the **unverified historical 7-8 litres**, not a new purchase quantity. Resolve the manufacturer process/temperature conflicts and material compatibility, component/enclosure fit and site earthing design.
- Obtain independent allocated-part E/pattern/body reports, earth-GDT forming/solder-fill acceptance and the Ruilon metric/inch resolution for all three SMT GDT positions. Include explicit placement/stencil/solder acceptance for TE on the retained alternate project lands and the BYG23T process. Design limits and standard untented fabrication are not lot/process approval; no special filling concession is requested.
- Obtain **job-specific allocation of ten fitted TE Connectivity 35212K2FT / C4129105 resistors and fifteen fitted Ruilon SMT GDTs**, plus accepted line-specific attrition for five prototypes; use the [GDT requirement/history update](#gdt-procurement-and-history), not the former ten-SMT-GDT budget or an assumed Bencent cancellation. Allocate later production/spares separately against the [production resistor order](#resistor-procurement-and-history) after quantity, receipt, inspection and production-part review/integration are established. Whole-BOM `allocation_verified` remains `false`. Cancelled, rejected and superseded selections in that history are not stock or current procurement tasks; no axial-resistor or GDT_AC forming applies to SMT. Request the five-board JLCPCB quote and parts/attrition/CAM/placement/solder/earth-GDT-forming approvals only after separate authorization to share/order; prototype file publication does not grant it.

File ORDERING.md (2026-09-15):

# JLCPCB Prototype Ordering Guide

**Draft hardware revision 1.2.1-dev; reviewed baseline 1.1.0. File-verified prototype artifacts are authorized; uploads and orders are not. Production/field holds remain in force.**

The agreed first order is **five individual, fully assembled boards**, with no field soldering. This guide describes the required quote and approval process; it does not certify the current files as ready for upload. **Gate P is the authorized file-verified prototype-artifact scope**, separate from the original [A/B/C production/field gates](REMEDIATION.md#release-gates). Supplier CAM, placement, allocated parts and separate user authorization remain necessary before an actual order.

The field requirement is **41 stations, 36 standard + 5 earth-connected, and 82 LEDs**, including both shed-end boards. Future production quantity depends on qualified prototype reuse, retained/destructive test units, and explicitly approved spares. Do not turn a five-board prototype order into five multi-up panels or automatically reorder the old production quantity. [MATERIALS](MATERIALS.md#assembly-and-quantity-allocation) controls quantity allocation.

## Board Finalization Queue

For **board/prototype-file** work, follow P3/P4 while preserving the
[physical guardrails](pcb/ASSEMBLY.md#physical-guardrails) and
[prototype population](#4-parts-and-allocation). Keep the supplier-response queue
below for a later, separately authorized five-board order. Do not restart switch,
cable or environmental research; those independent holds do not themselves
select a different circuit.

| Next board decision | Exact response/evidence needed |
| :--- | :--- |
| **SMT job allocation** | Accept **ten fitted TE prototype resistors and fifteen fitted Ruilon SMT GDTs, each plus supplier-specified attrition**, for five boards; record packaging and exact job allocation under [Parts And Allocation](#4-parts-and-allocation). No resistor or GDT_AC lead forming/insertion-hole approval is needed. |
| **Remaining part/fit acceptance** | Exact KF129 variant and allocated Kefa/earth-GDT pin/body/pattern limits; accepted forming drawings for the three axial earth GDTs. The retained hole/body envelopes are already implemented, not still awaiting a CAD resize; actual lot acceptance remains open. |
| **SMT and THT process** | Accept the retained **alternate project resistor lands for TE**, not a claimed manufacturer-exact pattern, and the selected metric Ruilon/SMA lands. Resolve Ruilon's 4.00 mm/0.165-inch conflict and approve actual placement, processed stencil and heavy-copper solder/inspection process for **all three SMT GDT positions**, including GDT_AC. |
| **Panel and drill preservation** | Drawing for five finished individual boards with the [revised outline and four mount positions](pcb/ASSEMBLY.md#physical-guardrails), retaining all fourteen 1.00/1.80 untented vias and protected copper; apply [J_EARTH's edge/fit requirements](pcb/ASSEMBLY.md#earth-terminal-edge-clearance). |
| **Placement approval** | Compare all sixteen anchors and 34 terminal datums in generated Assembly.txt with exact supplier models, using the pad-outline/courtyard Assembly.pdf. Pin numbers/nets are explicit in the text; native PDF pad numbering is not assumed. Record any supported model transform; do not hand-edit CPL or PCB pads to fix import conventions. |

This is a **supplier-response checklist, not an order authorization or a claim
that responses have been received**. [Gate P](REMEDIATION.md#release-gates) may
publish checked prototype files with **C4/C5/W3/W1/W4 deferred, not closed**;
every file/sourcing check still applies. Supplier responses above are order
tasks. Enclosure dry-fit and prototype-dependent physical tests follow receipt
under [ACCEPTANCE](ACCEPTANCE.md), not as prerequisites for prototype files.
Original A/B/C holds remain; no upload is authorized.

External material/switch evidence and unresolved discrepancies remain in [ENVIRONMENT_EVIDENCE](pcb/ENVIRONMENT_EVIDENCE.md), not this board-response queue.

## 1. Before Upload

Use the working design/project sources under `pcb/`, not backups, archived ZIPs or scratch copies. `pcb/BOM.csv` is reviewed sourcing data; `pcb/CPL.csv` is a **native-generated draft reference**, not an independently edited coordinate list or upload approval. [Electrical analysis](pcb/ELECTRICAL.md) and [controlled assembly notes](pcb/ASSEMBLY.md) record the current corrections and remaining decisions.

For Gate P file verification and the later, separately authorized supplier review, verify the actual implementation and reports for:

- The authorized **16-part SMT/THT hybrid** and [six-end functional matrix](INSTALL.md#functional-matrix). D3/D4 are output shunts after D1/D2, not extra series parts or qualified forward pulse-current regulators. The [electrical record](pcb/ELECTRICAL.md#9-simplified-indicator-direction) controls protection limitations; historical active candidates are not required purchases.
- Exact parts and local footprints against the [BOM](pcb/BOM.csv) and [reviewed component index](pcb/ASSEMBLY.md#reviewed-components), not retired selections or stock-library substitutes. D1-D4, R1/R2 and all three inter-core GDTs are SMT; GDT_AC's former axial part and two holes are retired. The retained resistor lands are an alternative to TE's recommendation requiring supplier acceptance under section 3.
- The adopted [hole/pin/pattern limits](pcb/ASSEMBLY.md#hole-fit-evidence), [body envelopes](pcb/ASSEMBLY.md#body-and-courtyard-evidence), real courtyards, reproducible local libraries, legend and earth-GDT forming drawing. Actual allocated-lot fit and solder/process acceptance are supplier order tasks, not file-check results. A standard-looking footprint name or matching C-code is not a mechanical match.
- All three SMT GDTs' mask/paste geometry around the protected vias, native signed-Y placement, and complete population/net parity. Verify the [layer-specific rail/crossing guardrails](pcb/ASSEMBLY.md#physical-guardrails): **exactly 6.00 mm rear B main width**, approved front-B stop and rear-return move, and **>=3.00 mm different-core A/B/C clearance on B.Cu only**. Both native and independent geometry checks are required; do not impose that inter-core rule on F.Cu's reviewed SMT gaps.
- Verify the approved **1.2.1-dev westward placement** and its separate **>=3.00 mm unlike-net inter-GDT pad / AC-pad-to-front-B copper controls**. Accept processed clearances and placement against [the current evidence](pcb/DFM_EVIDENCE.md#westward-clearance-evidence), not the old coordinates or a blanket 3 mm front-layer claim.

Use the [current normal-current cases](pcb/DESIGN_BOUNDS.md#normal-current) and [thermal screens](pcb/DESIGN_BOUNDS.md#thermal-screens) to define separate qualification work, not procurement acceptance bands, enforced source limits or a guaranteed field-current minimum. Preserve INSTALL's [one TEST source/disconnected spare configuration](INSTALL.md#switch-and-supply) and [whole-boundary cattle-fence prohibition](INSTALL.md#cattle-fence-prohibition); neither is changed by a PCB order.

Apply [AGENTS' verification/publication workflow](AGENTS.md#3-verification-and-publication) for complete-project DRC, ERC, parity, geometry, population and artifact checks. Errors, unreviewed warnings/export diagnostics and stale review inputs block; narrowly reviewed diagnostics remain visible. Do not weaken gates or refresh approval hashes to obtain a package.

`make check` verifies without publication; `make prototype` / `make gerbers` may publish **FILE-VERIFIED PROTOTYPE ONLY** after all file/sourcing checks. Unresolved external sourcing blocks both modes; file parity or public stock is not job allocation. Production targets retain all engineering holds and win mixed goals. Detailed native commands, diagnostic reviews, locking and evidence-preserving cleanup belong to AGENTS.

Current verification for the approved **2 mm east board extension**, still **1.2.1-dev**, is controlled by the [east-extension handoff](REMEDIATION.md#east-board-extension). Require a fresh matching source/controlled-note snapshot and manifest; the earlier [westward-spacing](REMEDIATION.md#westward-gdt-spacing) and SMT AC/rear-B checks are historical and do not verify the changed geometry or notes. A shared revision label, part selection or old PASS is not current release evidence.

| Intended file | Use after verification |
| :--- | :--- |
| `build/Gerbers.zip` | PCB quote/fabrication: F.Cu, B.Cu, F.Mask, B.Mask, F.SilkS, B.SilkS, F.Paste, Edge.Cuts and separate PTH/NPTH drills. Generated mirror: `pcb/Gerbers.zip`. |
| `build/BOM.csv` | Assembly references, population and reviewed sourcing identities. |
| `build/CPL.csv` | Native-generated placement for **all required SMT and THT** parts, excluding mechanical holes/DNP items. |
| `build/pcb.d356` | IPC-D-356 connectivity for bare-board test/CAM comparison. |
| `build/FlyTest.zip` | Netlist and fabrication package for bare-board electrical testing, not an assembled functional/surge test. |
| `build/README.txt` | Generated mode and open-hold notice, included inside both ZIPs so prototype restrictions travel with the files. |

Inspect fresh exported geometry, layer/drill classification, schematic/PCB/IPC connectivity, BOM/CPL completeness, and archive members. Check `build/status.json`, `build/reports/verification.json`, readable/JSON DRC/ERC reports, and the published `build/manifest.json` revision/source/artifact hashes. Require **`status=prototype`, `mode=prototype`** for prototype files, or **`status=verified`, `mode=build`** for production files. **No matching manifest means no current file-verified package; neither pair authorizes upload or order.** Both modes use the same filenames and Gerber mirror. Assembly outputs include native pad outlines and courtyards in `Assembly.pdf`, exact footprint/terminal datums with pin numbers/nets in both coordinate conventions in `Assembly.txt`, `ViaTreatment.csv` and all seven controlled engineering notes. These are supplier-review aids, not accepted centroid corrections. Never hand-edit generated Gerbers, drills or ZIPs to bypass a failed check.

Compare the reports with [ASSEMBLY's expected file inventory](pcb/ASSEMBLY.md#reviewed-components). Design counts alone are not evidence that the current native exports passed.

## 2. Quote Specification

After Gate P file verification and **separate authorization to share the files**, request the actual quote at [JLCPCB](https://jlcpcb.com/quote). Capture the accepted options and any exceptions in the release record. The current authorization is file generation only, not this upload/quote/order step.

JLCPCB offers **standard two-layer FR-4 with 2 oz copper on both sides and ENIG**. Use the standard quote options for this combination, not an assumed special-stackup exception. No special CAM approval is implied or recorded; availability does not accept this design's hole/via, land-pattern, soldering or assembly details. The design-specific reviews below remain required.

| Item | Five-board prototype baseline / supplier confirmation |
| :--- | :--- |
| Quantity | **Five individual usable boards, all five fully assembled**. State panel-to-individual-board conversion explicitly. |
| Material | Readily available standard **FR-4**. Do not impose High-Tg 170, a particular Shengyi grade, or a claimed lifetime requirement without an approved engineering need. |
| Layers / size | **Two layers, 65 x 56 mm** per individual board. Both layers carry isolated fence and earth copper; B.Cu is not a blanket ground plane. |
| Thickness | **Nominal 1.6 mm finished board**. Confirm supplier measurement convention, including over-mask thickness, tolerance and support fit against the [controlled stackup/acceptance requirements](pcb/ASSEMBLY.md#thickness-and-process), not just the nominal arithmetic. |
| Copper | **2 oz / 70 micrometres on both F.Cu and B.Cu**. This does not specify finished barrel plating or an assembled surge rating. |
| Finish / mask | **ENIG, green soldermask default**. Record actual finish specification; do not mandate 2-microinch gold or claim a pore-free environmental seal. |
| Hole/via process | Selected standard **UNTENTED on both sides, no fill/plug/cap** for all **14 protected 1.00 mm nominal drill / 1.80 mm copper vias**, with nominal **1.80 mm F.Mask/B.Mask openings and no via paste**. Preserve positions/drills and inspect the processed data; this is not a sealed-hole process. See section 3. |
| Assembly | All **nine SMT and seven THT parts per board**, top-side, fitted and soldered, with three SMT inter-core GDTs and controlled lead forming for the three axial earth GDTs. Confirm against the accepted design before quote acceptance. |
| Service | Current public guidance permits THT under **both Economic and Standard PCBA in principle**. Confirm the exact mixed SMT/THT, 2 oz/ENIG job, part sourcing, manual operations and test scope in the actual quote. |
| Panel / tooling | Supplier-proposed rails, fiducials and tooling, with an approved drawing and depanelization method. Standard PCBA processing-size requirements may require panelization for this small board. |
| Solder process | Explicit acceptance of heavy-copper soldering, 2512 / all three Ruilon GDT / BYG23T SMT paste volume, THT fillets/barrel wetting and earth-GDT forming/standoff inspection. No axial resistor or GDT_AC forming, field soldering or forced insertion/reaming to repair fit. |
| Additional coating | Not part of the agreed baseline. Do not assume **OneGel** makes coating universally redundant or that adding coating is automatically compatible. Its process/material acceptance remains open under the [OneGel evidence](pcb/ENVIRONMENT_EVIDENCE.md#wiska-onegel) and [installation controls](INSTALL.md#gel-and-service). |
| Testing | Agree bare-board continuity/isolation test coverage and any assembled testing separately. Do not label flying probe as LED, reversal, thermal, RF or surge qualification. |
| Price / schedule | Obtain a dated itemized quote: PCB finish/copper, parts, loading/extended fees, attrition, SMT/THT labor, forming, tooling, tests, shipping and applicable taxes/import costs. No fixed stock, cost or lead-time promise is established here. |

The supplier must propose the actual panel/rail dimensions. The old **73 x 76 mm** assumption is not an approved panel plan, and rail removal is not automatic. Confirm five finished boards will be delivered in the agreed condition, with no cuts/tooling holes in protected functional copper and no damage to board edges or mounting features. Absence of fiducials on the single PCB is not itself a defect if approved panel fiducials/tooling satisfy assembly needs.
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

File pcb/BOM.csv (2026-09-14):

Comment | Designator | Footprint | LCSC Part # | MPN | Manufacturer | Sourcing | Sourcing Reference
KF128-7.62-3P | J_IN | DogFence:KF128_7.62_3P_Input | C474957 | KF128-7.62-3P | Cixi Kefa Elec | LCSC
KF128-7.62-3P | J_EARTH | DogFence:KF128_7.62_3P_Earth | C474957 | KF128-7.62-3P | Cixi Kefa Elec | LCSC
KF129-5.08-2P | J_LED_A | DogFence:KF129_5.08_2P_LED_A | C475092 | KF129-5.08-2P | Cixi Kefa Elec | LCSC
KF129-5.08-2P | J_LED_C | DogFence:KF129_5.08_2P_LED_C | C475092 | KF129-5.08-2P | Cixi Kefa Elec | LCSC
2.2k 2W | R1 | DogFence:R_2512_6332Metric | C4129105 | 35212K2FT | TE Connectivity | LCSC
2.2k 2W | R2 | DogFence:R_2512_6332Metric | C4129105 | 35212K2FT | TE Connectivity | LCSC
BYG23T-M3 | D1 | DogFence:BYG23T_SMA_K_Right | C145454 | BYG23T-M3/TR | Vishay General Semiconductor | LCSC
BYG23T-M3 | D2 | DogFence:BYG23T_SMA_K_Right | C145454 | BYG23T-M3/TR | Vishay General Semiconductor | LCSC
BYG23T-M3 | D3 | DogFence:BYG23T_SMA_K_Right | C145454 | BYG23T-M3/TR | Vishay General Semiconductor | LCSC
BYG23T-M3 | D4 | DogFence:BYG23T_SMA_K_Right | C145454 | BYG23T-M3/TR | Vishay General Semiconductor | LCSC
SMD5050-470NA | GDT_AB | DogFence:SMD5050-470NA | C39692533 | SMD5050-470NA | Ruilon | LCSC
SMD5050-470NA | GDT_BC | DogFence:SMD5050-470NA | C39692533 | SMD5050-470NA | Ruilon | LCSC
SMD5050-470NA | GDT_AC | DogFence:SMD5050-470NA | C39692533 | SMD5050-470NA | Ruilon | LCSC
2R470TD-8 | GDT_A_E | DogFence:2R470TD-8_P15.24mm | C2836978 | 2R470TD-8 | Ruilon | LCSC
2R470TD-8 | GDT_B_E | DogFence:2R470TD-8_P15.24mm | C2836978 | 2R470TD-8 | Ruilon | LCSC
2R470TD-8 | GDT_C_E | DogFence:2R470TD-8_P15.24mm | C2836978 | 2R470TD-8 | Ruilon | LCSC

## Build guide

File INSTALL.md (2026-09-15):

# Installation and Operation

**Draft revision: 1.2.1-dev. Production/field release remains held; prototype-file authorization is not installation approval.**

This manual applies the [agreed requirements](REMEDIATION.md#agreed-requirements) to installation and operation; it is not an approved hardware release. **Gate P permits file-verified prototype artifacts only**, not uploads, orders or installation. Supplier acceptance and production/field qualification remain separate under the [release gates](REMEDIATION.md#release-gates).

[ELECTRICAL](pcb/ELECTRICAL.md) records the remaining circuit limits: negative clamps are not qualified pulse protection, powered-GDT recovery is unresolved and actual OneGel thermal testing is unperformed. Use [ACCEPTANCE](ACCEPTANCE.md) for controlled prototype qualification and commissioning records, and [RISKS](RISKS.md) for limitations. Do not roll out this draft or rely on it for containment or lightning protection.

[MATERIALS](MATERIALS.md) owns purchases, receipts and allocations, including [resistor history](MATERIALS.md#resistor-procurement-and-history); [ENVIRONMENT_EVIDENCE](pcb/ENVIRONMENT_EVIDENCE.md) owns manufacturer/site evidence and unresolved discrepancies.

## System Layout

- Install **41 stations at 0, 100, ..., 4000 m**, with one board and two external LEDs per station: **82 LEDs and 40 diagnostic spans**. The 0 m and 4000 m stations are separate stations even though both cable ends reach the shed.
- Retain the five earth-connected station locations at 0, 1000, 2000, 3000, and 4000 m, subject to the accepted earthing design. This leaves **36 standard stations**. Five earth-connected stations do not imply five independent earth electrodes.
- Preserve the WAGO through-splice/PCB-tap arrangement. Use three WAGO 221-613 splices and four supports per station. Reconcile total requirements and prototype/spare allowances against the [recorded inventory](MATERIALS.md#1-station-inventory); required quantities are not evidence of purchases.
- The first order is five fully assembled prototypes, with no field PCB soldering. Retain an unpotted reference and qualify the assembly before preparing the perimeter batch; passing basic tests on five boards is not field-release approval.

Each core has its own through-splice. Do not join different cores at a station:

```text
Incoming A ---- WAGO A ---- Outgoing A
                  |
                J_IN A

Incoming B ---- WAGO B ---- Outgoing B
                  |
                J_IN B

Incoming C ---- WAGO C ---- Outgoing C
                  |
                J_IN C
```

At the two shed-end stations, the corresponding hub lead occupies the end connection. Normal perimeter current follows the cable and WAGO splices, not a series path through every PCB. Each PCB takes its local indicator current; surge current through a board is a separate qualification case.

## Safety First

- **TEST and OFF disable the RF fence.** Secure animals using independent containment before selecting either mode, opening a box, or testing the transmitter. Do not use an animal as a test receiver. Provide clear hub mode indication and an operator reminder to restore RUN.
- OFF is ordinary hub disconnection, **not demonstrated lightning isolation or safe maintenance isolation**. Long outdoor conductors can acquire dangerous induced voltage even with local supplies off. Do not handle the fence, earth connections, or test equipment during electrical storms.
- Before wiring or resistance checks, isolate the transmitter, TEST PSU, their mains feeds and every battery/backup source using the accepted safe-isolation procedure. Prevent reconnection, allow stored energy to discharge, and verify absence of voltage before touching terminals, using a suitable instrument and a check-before/check-after procedure. Then disconnect all six boundary ends from the hub and keep them individually separated for the work/checks. Energized cattle fencing is prohibited near the entire boundary, stations and hub; if discovered, **stop work/use** and arrange safe isolation and reassessment before handling conductors or resuming use. Apply the [whole-boundary prohibition](#cattle-fence-prohibition) below. A switch label or fuse-holder lamp is not an isolation test.
- A qualified installer must design and install the mains enclosure, protective earth (PE), supply protection, bonding, electrode arrangements, and transmitter protectors to applicable Isle of Man/regional and OEM requirements. Do not copy US outlet-faceplate grounding instructions into this installation. Never switch PE as part of RUN/OFF/TEST.
- Retain the actual DogWatch transmitter's required protector(s) and obtain regional OEM approval for this nonstandard boundary configuration. The station boards are not replacements for the OEM protection. A nominal 36 V supply is not permission to touch wet or surge-exposed wiring.

### Cattle-Fence Prohibition

**No energized cattle fencing is permitted near the whole 4 km boundary cable, any station or the hub**, as explicitly confirmed by the user. The former **0.5 m / up to 300 m parallel scenario is withdrawn and historical**, not an accepted installation or current energizer-on/off test requirement. Inspect the whole route, including every station and the hub, before use and maintain the prohibition. If land use changes or the hazard is reintroduced, reassess before use; no numerical safe separation, zero induction or zero lightning exposure is established. Ordinary RF, switching and nearby-lightning exposure remain relevant.

## Materials and Site

| Item | Installation requirement / unresolved evidence |
| :--- | :--- |
| Indicators | Purchased baseline **APEM Q10F5SXXSG02E**, the **no-internal-resistor** option. Published family limits are **20 mA maximum forward current and 5 V maximum reverse voltage**, subject to applicable temperature/pulse conditions. `02` does not mean regulated 2 V operation. Use the qualified board drive, not a direct 36 V connection. |
| Boundary cable | User-confirmed **AMC Oceanflex CM03/05.100** reels labelled `3 CORE (3 x 35/0.30) TINNED BLACK 100 MTR`. AMC **2026 Update V.3** lists **3 x 2.5 mm^2, Class 5 tinned copper, 7.4 mm maximum OD, 60 V max DC, -30 to +70 degrees C** complete-cable service. Product identity is settled; confirm supplied manufacturing-revision/lot applicability and reconcile the [conditional resistance/strand-construction evidence](pcb/DESIGN_BOUNDS.md#evidence-and-inputs). A model ceiling is not a reel measurement. |
| Core identification | Confirmed colours are **red, black and PLAIN green**, not green/yellow. Plain green is an identified active core, **not PE**. Identify every core end-to-end and record/label its A/B/C assignment at every termination; no colour-to-net mapping is assigned here. **GREEN/YELLOW MUST NOT BE USED AS AN ACTIVE A, B, OR C CONDUCTOR**, including by re-sleeving it. |
| Cable exposure | The older listing's 105-degree core reference is not a complete-cable rating. Obtain evidence for exposed-weather/UV service, wet conduit, and the required insulation/impulse performance. The 60 V operating rating neither establishes surge withstand nor proves failure at every brief higher voltage. Do not assume armoured, arctic, or mains cable properties. |
| Enclosure | WISKA **COMBI 308**, **polypropylene (PP) with TPE gasket, not polycarbonate**, external dimensions 85 x 85 x 51 mm. Internal usable space must be measured with the actual assembly. Its published IP66 membrane/IP67 specified-gland arrangements are not automatic ratings for a drilled, wired, gel-filled assembly. No continuous submersion is intended. |
| Supports and gel | Essentra **LCBSBM-6-01A-RT** supports and confirmed WISKA **OneGel**, correcting the mistaken MP0100 identity: **single-component 300 ml cartridge, order no. 10108963; no mixing**. Obtain the exact support tolerance/retention drawing and supplied-lot gel process/safety clarification before filling. Do not substitute a related gel formulation's instructions. |
| Environment | Isle of Man, less than 1 km from the coast, with frequent rain, salt and possible condensation. Observed outdoor ambient is approximately **-10 to +30 degrees C**; some boxes receive direct sun. These observations are not lifetime extremes or maximum internal temperatures. Gel, cable, seals, adhesives and electronics need a qualified solar/thermal envelope. |

Route the cable mostly 0.3-1.0 m above ground on timber fencing, with abrasion protection, suitable supports, slack for movement, and no electrical connection to the horizontal supporting metal wires. The supporting fence is not energized. Plastic conduit under driveways/gates can become wet and is not electromagnetic shielding; verify cable suitability, mechanical protection, drainage arrangements, and utility locations before ground work.

## Hub Wiring

### Functional Matrix

The following is a **functional contact matrix, not a physical terminal-number diagram**. T1 and T2 mean the transmitter's two boundary connections through the required OEM protector arrangement. They do not authorize bypassing those protectors.

| Boundary-cable end | RUN | OFF | TEST |
| :--- | :--- | :--- | :--- |
| Start A | Transmitter T1 | Isolated | +36 V |
| Start B | Transmitter T1 | Isolated | DC negative |
| Start C | Transmitter T1 | Isolated | +36 V |
| End A | Transmitter T2 | Isolated | Isolated |
| End B | Transmitter T2 | Isolated | Isolated |
| End C | Transmitter T2 | Isolated | Isolated |

Use **six independent boundary-end connections**, individually accessible and isolated at the hub in OFF. All three End connections remain **separately isolated in TEST**. Required RUN ties and the TEST positive tie belong on the appropriate **source-side contacts**, never as permanent boundary-side straps. TEST feeds and returns at Start; no additional End return connection is permitted.

**No permanent End A/C strap, opposite-end B return or dual-B negative return is permitted.** An End A/C strap can backfeed a broken core; an opposite-end-only B return leaves both sides dark after a complete cut; connecting both B ends to negative masks a B-only break.

The transmitter must be isolated from the TEST source in TEST, and the TEST source isolated from the boundary/transmitter in RUN. Transfer must also preserve isolation: **all old-source connections must break before any new-source connection can make across the entire six-end contact program**, in either direction. Per-pole timing or a centre-off label alone does not establish this global break-before-make requirement.

### Switch and Supply

1. Confirm the actual switch and obtain its manufacturer's contact development, DC load-breaking suitability for the actual circuit, global transfer sequence, mounting details, and applicable insulation conditions. **Kraus & Naimer CA10.A364** is provisional; the current **WAA364 (formerly A364) is eight-pole, 1-0-2 centre-off, 60-degree switching, not six-pole**. The six-end matrix is unchanged and the **two extra poles remain unassigned**. Its 20 A thermal rating does not prove DC breaking or lightning isolation. Previously purchased switch inventory is not evidence of compliance. Do not assign terminal numbers or energize the hub until the exact offered program is accepted.
2. Use **one MEAN WELL LRS-75-36, 36 V / 2.1 A / 75.6 W, for TEST; keep the second disconnected as a spare**. No parallel, series, separate-channel or opposite-end feeding is authorized. Verify receipt/nameplates and the intended unit's output setting against the [hub inventory](MATERIALS.md#3-shed-hub-inventory); an order is not inspected hardware. LRS-75-36 has adjustable output and hiccup overload protection. Set and record only the voltage range authorized by the final electrical/thermal analysis; do not raise it to compensate for poor visibility.
3. Install the PSU using its actual mounting and ventilation instructions inside a dry, guarded mains enclosure. Do not assume an LRS chassis supply snaps onto DIN rail. A 35 mm rail may carry the compatible fuse holder and other approved rail-mounted parts. Keep mains terminals finger-safe and mains wiring segregated from the field/test wiring as the installer specifies.
4. Verify the specified **Littelfuse 0217002.MXP, 2 A 217-series fuse**, and **Phoenix Contact UK 5-HESILED 60 / 3004139** holder against supplied items and the final source design. The fuse has published DC interrupting data; its unresolved issue here is clearing coordination with cable-limited faults and PSU hiccup behavior. Do not assume every short clears it, or change its value without analysis. The LRS-75-36 does not resolve C5.
5. With sources and field disconnected, verify the accepted wiring against every cell of the functional matrix. Check that no source, protector connection, test lead, jumper or label creates an unintended field-end tie. Static continuity checks supplement, but do not prove, rated DC breaking or transfer timing. Record the accepted terminal drawing separately once the exact hardware is confirmed.

The [WAA364 catalogue contact/link schedule](pcb/ENVIRONMENT_EVIDENCE.md#catalogue-contact-schedule)
is now recorded as design-review evidence, **not the supplied-switch pinout**.
Its eight separate fixed common links remain connected in `0`; do not mistake
them for a common bus or assign two field ends to one link. No catalogue pole
or `1`/`2` detent has been assigned a DogFence wiring or RUN/TEST role.

The [source-envelope study](pcb/DESIGN_BOUNDS.md#evidence-and-inputs) uses conditional calculations, not hardware-enforced or approved installed voltage limits. Establish actual adjustment, tolerance, ripple and startup behavior, including hub/interface losses in the feed limits; PSU OVP is not a precision operating limiter. Qualifying the real normal source range is an alternative to imposing a new precision cutoff; it does not settle source-malfunction or GDT recovery safety.

Label the actual detents only after their function is verified; do not assume a particular UP/DOWN orientation:

| Label | Operator meaning |
| :--- | :--- |
| **RUN - RF FENCE SELECTED** | Confirm transmitter and receiver operation before relying on containment. |
| **OFF - SIX ENDS ISOLATED - NO CONTAINMENT** | Neither source connected to the boundary at the hub; not lightning-safe isolation. |
| **TEST - 36 V CABLE TEST - NO CONTAINMENT** | Independent animal containment required. **RESTORE RUN AFTER TEST.** |

## Workshop Assembly

After receiving the prototypes, first dry-fit a complete assembly. Do not drill or prepare all lids until that fit and the process have been accepted. Use the reviewed [PCB BOM](pcb/BOM.csv), [placement and assembly controls](pcb/ASSEMBLY.md#placement-and-polarity) and [DFM evidence](pcb/DFM_EVIDENCE.md) for received-part identity, lands, retained holes, pin-pattern, body and earth-GDT-forming limits.

The prototype uses 2512 SMT resistors, SMA diodes and **three SMT inter-core GDTs, including GDT_AC**. There are no resistor/diode/AC insertion holes or axial-resistor/AC standoff/forming requirements; the three earth GDTs remain axial. The retained **project-alternative resistor lands differ from TE's recommendation** and require supplier placement/stencil/solder acceptance; body fit is not an exact land-pattern match. Yageo needs [separate review and controlled source updates](ORDERING.md#7-prototype-acceptance-and-later-orders): neither its order nor TE testing authorizes substitution. Controlled envelopes are not accepted lots or assembled hardware.

1. Match each received board to the reviewed revision, BOM and assembly drawing. Inspect workmanship and run the all-five basic checks in [ACCEPTANCE.md](ACCEPTANCE.md). Board outline is nominally 65 x 56 mm with four 3.2 mm mounting holes at the [current controlled positions](pcb/ASSEMBLY.md#physical-guardrails); actual thickness and hole tolerances must suit the supports. No forcing leads into undersized holes, reaming finished plated holes, or field PCB soldering is allowed.
2. Check the **Essentra LCBSBM-6-01A-RT** drawing against actual holes and finished board thickness, including fabrication tolerance. The listing's nominal 3.18 mm support hole, 1.57 mm panel and 9.53 mm spacing are not a universal fit guarantee. Verify all four locks engage without board damage or flex. Qualify adhesive retention, surface preparation and the adhesive's cure/dwell conditions on COMBI 308's PP substrate. Use IPA only if accepted by the material/adhesive instructions, and allow the surface to dry fully. Gel is not a permanent structural support.
3. Lay out both lid indicators to suit real viewing angles and internal clearances. The earlier approximately 35-40 mm centre spacing is only a dry-fit starting point. Use the exact APEM cutout tolerance and lid-thickness instructions; the nominal cutout is 10 mm. Deburr without damaging the sealing surface. Install the specified seal, washer and nut in the model's documented order. Published Q10 tightening guidance is **0.20-0.25 Nm, subject to the exact Q10F5SXXSG02E instructions**; use a suitable low-range torque tool and record the instruction revision. Do not over-compress the seal or crack the lid.
4. Position the board with `J_IN` toward the incoming tap wiring and `J_EARTH` toward the earth wiring. In the controlled board view, `J_IN` opens left, `J_EARTH` right, `J_LED_A` north and `J_LED_C` south. The two LED connectors are intentionally oppositely oriented; verify both `+` and `-` markings against the actual assembly drawing rather than assuming matching rotations. D1/D2 cathodes face right; D3/D4 cathodes face left to LED positive, with their anodes right to B. Do not infer all four orientations from the local cathode-right footprint name.
5. Trial-fit **all** contents: three WAGO 221-613s, actual incoming/outgoing cable and glands, three pigtails, earth conductors where applicable, supports, both LED bodies, lid seals, plugs, and a suitable terminal screwdriver. Allow cable bend radii, wire strain relief and lid service slack. Close the lid fully and verify no wire or LED body presses on a GDT, solder joint or PCB. Use the [current body/seating and crossing controls](pcb/ASSEMBLY.md#placement-and-polarity), including actual SMT solder seating height; **GDT_AC has no raised-overpass lead-forming or height-gauge requirement**. Inspect the three axial earth GDTs at the unchanged **9.00 mm centre pitch** against their accepted forming drawing and controlled maximum-body/pose envelopes, not an assumed 1 mm air gap. Do not apply retired PR02 standoff/forming instructions to SMT resistors. Record actual clearances and inspect seating, leads and joints again after lid closure/re-entry. Solder mask, tape or gel cannot excuse contact, bad forming or unqualified insulation; the rear B crossing requires the separate workmanship and [qualified insulation/transient checks](ACCEPTANCE.md#qualified-fault-tests).
6. Prepare labelled A/B/C pigtails, nominally 2.5 mm^2, with lengths determined by the dry-fit; approximately 120-150 mm is a starting allowance, not a prescribed bend geometry. Use a separately identified permissible active conductor for each core. Follow the terminal manufacturers' conductor range, strip length, ferrule policy and screw torque. Do not solder-tin stranded wire ends, put multiple wires in an unapproved clamp, or leave stray/exposed strands.
7. Connect each pigtail between its own WAGO and the matching `J_IN` **A, B or C** marking. Connect each actual APEM anode to its channel's `+` and cathode to `-`; verify the supplied lead identification rather than relying solely on assumed red/black colours. **The implemented negative shunts do not protect reversed LED flying leads or establish pulse-safe reversal survival.** The user accepts indicator damage from accidental low-voltage installation polarity errors and requires [installation spares](MATERIALS.md#1-station-inventory), with quantity still to allocate. Check before power; correct suspect wiring and replace damaged indicators while isolated, not by leaving a dark/miswired branch powered. This does not waive safe wiring or continuous TEST thermal requirements.
8. Seat one conductor per WAGO port, close each lever and perform a gentle retention check. The WAGO 221-613 strip marking is the authority (nominally 13 mm); use the PCB terminal's own specification for its end of a pigtail. Record torques, component identities, clearances and photographs before gel makes inspection harder.

Use [J_EARTH's edge-clearance and inspection requirements](pcb/ASSEMBLY.md#earth-terminal-edge-clearance) in the dry-fit: its unchanged body/pose envelope and full courtyard are **nominally inside the extended east edge**, not supplier-tolerance or measured-fit approval. Inspect actual lot, routed edge, supports/enclosure and wire/tool access; record clearances with uncertainty. Stop for interference or missing fit/access acceptance before potting or preparing the remaining lids.

All fourteen stitching vias retain their **1.00 mm nominal drill / 1.80 mm copper and positions**, but are intentionally **UNTENTED on both sides, with nominal 1.80 mm mask openings, no via paste and no fill/plug/cap**. Adjacent same-net rail-via mask openings intentionally overlap; this is distinct from an SMT mask/paste aperture over a via hole or annulus, which is not permitted. Inspect the actual solder/cleanliness process and processed data per ORDERING/ACCEPTANCE. Neither exposed ENIG nor OneGel seals a via.

## Field Mounting

1. Label stations by distance, **0 m through 4000 m**, with A/C lens identification and the direction from Start toward End. Orient the lid toward the patrol track at the angles used for the 5 m visibility acceptance test.
2. Mount boxes raised, typically **0.8-1.2 m above ground** where safe and accessible, away from strimmers, standing water and predictable animal/mechanical damage. Use the enclosure's approved mounting bracket or mounting points. On timber, choose suitable corrosion-resistant fasteners for the post and bracket; on other supports, use an accepted UV/corrosion-resistant mounting method without crushing the enclosure or electrically joining fence conductors to metalwork. Do not make unapproved penetrations through the sealing envelope.
3. Prefer downward cable entries. Form drip loops below the entries, approximately 50 mm where compatible with the cable's minimum bend radius, so runoff does not lead into the gland. Select each gland by the **measured jacket diameter**, clamping/sealing range, enclosure thread/seal system and exposure, not just by the label M20. Do not assume one ordinary gland seals two cables, or that a conduit fitting seals the cable. Fit approved plugs/seals to unused entries.
4. Remove only enough jacket for the accepted layout, keeping the jacket under the gland's sealing/strain-relief area. Maintain A-to-A, B-to-B and C-to-C continuity in the three independent WAGO splices. Support the cable externally so the splices, PCB taps and lid leads carry no cable tension. Check every termination before closing the box.
5. Install earth connections **only to the accepted site drawing**. At the five earth-connected stations, use `J_EARTH`, never an A/B/C terminal. Standard stations leave the external `J_EARTH` connection empty; they have no assured local common-mode discharge path. The three earth terminal positions share a PCB net, but their ratings cannot simply be added and equal surge-current sharing is not established.

The user's proposal to share local earth between the DogWatch protection and the two shed-end boards must be reviewed against the **actual building PE/electrodes**, regional OEM instructions, and touch/step-potential and bonding requirements. Do not install arbitrary unbonded rods, directly earth a fence core, or assume DC negative should be earth-bonded. The [earth hardware inventory](MATERIALS.md#5-earthing-inventory) is not approval of electrode placement, conductor sizing or multiwire clamping. The installer must specify compatible clamps, conductor routing and mechanical protection, inspectable connections, and any electrodes/bonds. Check buried services before any electrode or conduit work. Never remove protective earth casually as part of fault diagnosis.

## Commissioning and Diagnosis

### Optional DMM Checks

These are low-voltage diagnostic checks, not insulation or arrester qualification:

1. Secure animals and isolate **all six boundary ends from the hub, transmitter, PSU and every backup source** as described in [Safety First](#safety-first). Both physical cable ends are at the shed. Verify de-energization before selecting resistance mode. Do not use resistance mode on RUN or TEST wiring.
2. Measure **Start A to End A**, then **Start B to End B**, then **Start C to End C**, leaving the other ends separately isolated. Record lead resistance/compensation, instrument range and uncertainty, cable temperature and the commissioning baseline for each core. An ideal **individual 4 km / 2.5 mm^2 copper core is about 28 ohms at 20 degrees C**, not zero and not a three-core parallel-loop reading. Use verified cable resistance/tolerance data and installed connection losses to set actual limits, not an arbitrary tolerance around 28 ohms.
3. Unexpected or changing readings require sectional investigation. Connected indicator/protection branches can affect measurements; follow the final circuit's measurement procedure and disconnect electronics for cable-only measurements where necessary. These checks aid diagnosis but do not replace LED span localization or rule out every short.
4. **Never apply a high-voltage insulation tester/megger through connected boards, LEDs, transmitter, protectors or PSU.** Any cable-only insulation test requires all electronics removed from the test circuit and an installer-approved test voltage/procedure appropriate to the actual cable. A DMM-open GDT only shows no detected conduction at that meter's test conditions; it does not prove that the arrester will fire or survive a surge.

### Normal Commissioning

Complete the controlled [acceptance programme](ACCEPTANCE.md) on the approved prototype configuration before field release. Initial workmanship, dry-fit and normal electrical checks precede potting the selected qualification units; potted thermal/material tests are still required before rollout. Record the final source setting and per-station currents/voltages instead of copying old aggregate-current or uniform-brightness assumptions.

Use the [TE-prototype / BYG23T bounds](pcb/DESIGN_BOUNDS.md), not retired-part values or unreviewed Yageo extrapolations. Their temperature/reference inputs are engineering assumptions, not verified TE test conditions or measured operating temperatures. Screens are not approved source limits, exhaustive minimum current or guaranteed brightness. Catalogue resistor power/derating transfer to this mounting remains unverified, not a demonstrated failure; SMT does not eliminate loss or prove cooler operation. Measure the actual chip/pad/PCB and gel/cable interfaces and qualify 5 m daylight indications for the intended population. No OneGel thermal test has been performed.

In a healthy qualified TEST installation, both indicators should be on at all **41 stations**, including the separate shed-end stations. Same-end feeding creates a brightness/current gradient; the final minimum current must still pass 5 m daylight visibility at real angles. In RUN, verify the actual transmitter, boundary field and receiver behavior with the required protectors fitted. Indicators should not give misleading light in RUN; their darkness is **not** proof that a series diode blocks RF or that the added circuit is transparent. Confirm that the whole-boundary cattle-fence prohibition remains satisfied; energizer-on/off testing is not part of the accepted installation. Series-diode leakage and possible OFF-state glow still need actual observation, not an ideal-model blackout assumption.

### Clean-Cut Indications

For **one clean damage site** in a span, healthy boards/LEDs/GDTs, and no other inter-core shorts, the required steady-state truth table is:

| Cut cores | Before the cut | After the cut |
| :--- | :--- | :--- |
| A | Both on | A off, C on |
| B | Both on | Both off |
| C | Both on | A on, C off |
| A + B | Both on | Both off |
| A + C | Both on | Both off |
| B + C | Both on | Both off |
| A + B + C | Both on | Both off |

The aim is the damaged **100 m span**, not exact broken-core classification. B-only and several multi-core cuts have the same indication. All-on indications do not certify freedom from shorts; an A-C short, for example, can create backfeed and mask an open. A failed local LED, loose tap, damaged branch or failed GDT can also mislead the display. An isolated dark station with healthy stations beyond it calls for local inspection, not an automatic conclusion that the preceding cable span is cut.

### Repair and Retest

1. Secure independent animal containment and notify the responsible operator. Use only the accepted hub switching procedure to select TEST, with the transmitter isolated and the supply at its qualified setting. Typical TEST use is one to two hours; **continuous-safe normal TEST is required** for accidental extended use, but this remains a qualification requirement, not a demonstrated property of the current draft. A timeout or automatic return to RUN is not the baseline safeguard.
2. Check the **0 m station first**, then follow increasing distance and record both LED states at every station. If the source-end indicators are wrong, investigate the hub, PSU/fuse/protective shutdown, polarity and local assembly before assigning a cable fault. Do not repeatedly reset protection or replace fuses without finding the cause.
3. Use the **first applicable LED-state transition** to identify the span between adjacent stations. Include the final **3900-4000 m** span and inspect the 4000 m station separately from the 0 m station at the shed. LEDs show a steady network state, not a timed sequence.
4. Isolate all sources and six ends before opening wiring. Inspect/repair the identified span and its terminations using an approved cable joint or replacement section with suitable mechanical and environmental protection. Replace defective PCB assemblies rather than improvising field soldering. Investigate shorts, earth faults and local indicator failures separately when the pattern does not fit the clean-cut assumptions.
5. Restore the accepted TEST configuration and check **all 41 stations again**. Multiple damage sites may only become apparent after the first repair; repeat location, isolation, repair and retest until the required normal indications and electrical checks are restored.
6. Close and reseal repaired boxes using the qualified material process. **The operator must restore RUN**, verify the transmitter has returned to normal, and check boundary/receiver operation before removing independent animal containment. TEST/OFF do not automatically restore the RF fence.

## Gel and Service

**Hold OneGel application until the supplied-lot process and compatibility are accepted.** Use the single-component cartridge without mixing; do not add a catalyst, prescribe a heat cure or assume self-levelling pour behaviour. WISKA's published **20 min versus no curing time**, and **-20 to +90 versus -60 to +200 degrees C** temperature entries require a dated OneGel-specific clarification, including separate application/service limits. Do not prescribe a curing interval or select the wider range as the assembly envelope. **No thermal conductivity is published in the reviewed sources.** See [the manufacturer evidence and conflicts](pcb/ENVIRONMENT_EVIDENCE.md#wiska-onegel).

Retain the supplied cartridge/lot and storage record, technical/safety document revisions, preparation and application conditions, accepted coverage/fill/vent method and re-entry instructions. Confirm compatibility with COMBI 308 PP/TPE, the exact Essentra supports/adhesive, cable sheath/core insulation, WAGO 221-613 contacts/housings, LED rear seals/leads, components and residual assembly materials. No fixed fill volume or usable cartridge yield is established by the historical quantity estimate in MATERIALS.

1. Complete the documented pre-potting inspections and electrical checks on a clean, dry, unpowered assembly. Photograph the wiring and record the board/parts revision and measured fit. Leave the designated reference prototype unpotted.
2. Prepare the assembly and material exactly as accepted, including compatible cleaning, full drying and any adhesive dwell requirements. Protect the enclosure gasket and gland sealing surfaces. Do not apply OneGel over water, salt or incompatible flux residue.
3. Dispense from the cartridge using the accepted fill level, orientation and venting process to obtain the specified coverage, including beneath the PCB and around the actual wiring. A closed fill/vent method may be used only if the manufacturer-compatible process has been validated on the real assembly. A vent overflowing does not demonstrate a void-free interior; do not force an arbitrary full-to-the-roof fill or add unapproved ports. Record actual material consumption and any void/coverage inspection.
4. Follow the clarified application/post-application conditions and refit the accepted plugs, glands and lid seals at their specified torques. Perform the post-process normal electrical, fit, sealing and instrumented thermal checks in [ACCEPTANCE.md](ACCEPTANCE.md). No hermetic seal, automatic IP68 rating or multi-decade lifetime follows from adding gel.

For service, isolate the installation first and follow the exact material's accepted re-entry, PPE, cleaning and repair instructions. Do not assume OneGel always peels off cleanly by hand or that fresh material may be dispensed over contaminated or removed gel without approval. Replace damaged seals, supports, glands or assemblies as needed; re-inspect and retest after disturbance. Agree inspection intervals with the installer for this coastal site and inspect after suspected surge damage, water ingress or mechanical impact. Keep installation, repair, source-setting and qualification records with the live release checklist in [REMEDIATION.md](REMEDIATION.md).

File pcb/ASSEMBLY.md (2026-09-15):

# Controlled Assembly Notes

Document: DF-ASM-1.2.1-dev. Updated 2026-09-15 for hardware **1.2.1-dev**.

**DEVELOPMENT / FIVE-BOARD PROTOTYPE SCOPE.** These instructions control the
selected **16-part SMT-resistor/BYG23T hybrid**, not a qualified field protection
design. [Reviewed Components](#reviewed-components) identifies the active BOM
and substitution restrictions; [Physical Guardrails](#physical-guardrails)
indexes the binding placement, fit/forming and process controls.

The **2026-09-15 user-approved east board extension** moves only the east outline
and H2/H4 **2.00 east**, leaving all copper and electrical components unmoved.
[Earth Terminal Edge Clearance](#earth-terminal-edge-clearance) controls the
current nominal/conditional margins and panel/fit acceptance; the dated
[East Board Extension](DFM_EVIDENCE.md#east-board-extension) records the mechanical
change without new part or datasheet claims.

The **2026-09-14 user-approved westward spacing change, hardware 1.2.1-dev**,
moves the nine rail vias and three SMT GDTs with their existing front takeoffs,
and shortens front B. It retains the **1.2.0-dev SMT AC / exactly 6.00 mm rear-B
conversion**, not the raised axial AC tube. Current instructions below follow
the [westward selection](DFM_EVIDENCE.md#westward-spacing-selection); the
[initial SMT conversion](DFM_EVIDENCE.md#smt-ac-crossover-selection) and
[retired forming drawing](#gdt_ac-forming-drawing) remain dated historical
evidence. Earlier native results do not verify the changed outline or this note;
require fresh integrated results for the source-matched snapshot. No hardware
or crossover qualification follows from the new nominal gaps.

## Prototype Artifacts

**FILE-VERIFIED PROTOTYPE ONLY** is a file-publication scope, not upload/order
authorization or field qualification. All file, native diagnostic, geometry,
connectivity, population and sourcing checks still apply; unresolved or incorrect
sourcing blocks both modes. For prototype publication, the open
[verification ledger](verification.json) holds **C4 (transient response),
C5 (powered recovery), W3 (continuous thermal), W1 (GDT-land/via process) and
W4 (allocated-lot/fit/assembly process)** are reported as deferred, not closed.
Production publication retains these holds, including mixed production/prototype goals.
Gate P does not close the original A/B/C production/field gates.
Switch/environmental qualification and received-board dry-fit do not gate
prototype files; their later acceptance duties remain open.

Both modes share filenames. Require a matching `manifest.json` with validated
revision/source/artifact hashes and **status=prototype, mode=prototype**, distinct
from production **status=verified, mode=build**. Private checked exports are not
publication. Changed controlled-note hashes require fresh artifact evidence;
unchanged filenames or revision labels do not make an earlier package current.

The full release ships **all seven controlled engineering notes flat**, with
[BOM.csv](BOM.csv), [verification.json](verification.json), generated CPL,
assembly aids and reports. Root guides are **not included**; their links here
are supplementary repository-only references. `Gerbers.zip` and `FlyTest.zip`
carry fabrication/bare-board-continuity payloads, **not the full engineering-note
set**. Both ZIPs must include generated `README.txt` mode/hold notices stating
**FILE-VERIFIED PROTOTYPE ONLY** and the deferred holds in prototype mode.
Flying-probe continuity is not assembled functional or surge testing.
`Assembly.pdf` and `Assembly.txt` do not reproduce this controlled note.
Never hand-edit generated artifacts.

An actual order still needs separate authorization and accepted exact parts,
job allocation, placement, fit/forming, processed CAM/stencil, panel and mixed-
assembly process. Whole-BOM **`allocation_verified` remains `false`**; public
identity/stock is not allocation. No supplier response or hardware test is
implied. Optional repository-only references: [AGENTS.md](../AGENTS.md) for
verification commands and [REMEDIATION.md](../REMEDIATION.md) for release decisions
and dated, revision-specific results.

## Physical Guardrails

Preserve these constraints and the detailed controls indexed below unless the
user explicitly approves a reasoned physical design change. This is the human
assembly owner; the current PCB and project/rule files remain design sources,
with independent executable geometry guards. Correcting a rating claim is not permission
to weaken construction, substitute stock-library geometry or alter it in CAM.
Dimensions and coordinates follow [Drawing Conventions](#drawing-conventions).

| Feature | Protected geometry / control |
| :--- | :--- |
| Board outline | **65.00 x 56.00**, from **(97.00,94.50) to (162.00,150.50)**. |
| Mounting | Four **3.20 NPTH**: **H1=(101.50,99.00), H2=(157.50,99.00), H3=(101.50,146.00), H4=(157.50,146.00)**; all nominal centres **4.50** from their adjacent board edges. Preserve **6.40-diameter keepout collar markings** and the larger **6.90-diameter / 3.45-radius front/back mechanical courtyards and copper keepouts**. Supports must not contact functional copper. |
| Fence rails | A/C remain full **3.20 width on both F.Cu and B.Cu**, with unchanged paths. The approved B main segment at **Y=122.50** is **3.20 F.Cu, X=106.00..115.00**, and **EXACTLY 6.00 B.Cu, X=106.00..131.00**, not the proposed 6.40. Preserve all stitching vias at the [1.2.1 coordinates](#stitching-via-identification) and the [SMT AC crossover controls](#smt-ac-crossover); no waist relief or narrowed thermal spokes. |
| EARTH bus | Matching solid **4.50-grid copper on both sides**, bounding **X=143.99..157.25, Y=111.25..133.75**. Preserve slit-free continuity, all five EARTH vias and the three paralleled J_EARTH pins. Do not add a blanket earth plane across the isolated fence nets. |
| Fence/EARTH isolation | **>=3.00 copper separation on both F.Cu and B.Cu**; nominal source-analysis global minimum remains **3.25**. The earlier **8.44** clearance to earth-GDT input pins is a historical geometry comparison, not a new measurement; remeasure revised outputs. |
| Rear core isolation and B returns | Require **>=3.00 between every different A/B/C net on B.Cu**, including pads and returns, in native rules and independent geometry checks. Approved nominal all-core minimum remains **3.02**. Retain the **1.60-wide** B-return stem at **X=136.50**, with **3.10** A/C gap, following the 1.2.0-dev shift from X=135.50. Keep all Y coordinates, widths and terminal endpoints, including **Y=107.20/137.80** return arms, unchanged. The westward selection does not authorize another rear reroute. |
| Front GDT spacing | The approved nominal **unlike-net inter-GDT pad minimum is 3.20**, not a blanket front-copper rule or a guaranteed finished 3.00 gap. Preserve the [selected stubs and metric lands](#smt-via-relocation), including each tube's **2.80 land / 1.80 connected-copper gap**. |
| Legend | Native **1.00 height / 0.15 stroke**, with **0.15 pad clearance**; retain A/B/C/EARTH, polarity/cathode identification, underside references and **1.2.1-dev** identification. Inspect processed printing. |

The two-layer/2 oz project rules also require track width **>=0.1651**, general
copper clearance **0.20**, hole clearance **0.25**, copper-edge clearance **0.50**
and nominal component-PTH ring **>=0.254**. These include conservative project
requirements, not only fabricator minima; do not weaken them to obtain a PASS.
Via-ring rules are not component-ring or pin-fit evidence.

Detailed inventories remain in their working sections, not in a second table here:

- [Thickness And Process](#thickness-and-process): two-layer FR-4/2 oz, stackup,
  ENIG, finished-thickness/support acceptance and heavy-copper assembly controls.
- [Placement And Polarity](#placement-and-polarity): all component origins,
  rotations and terminal nets, distinct complete LED mappings, GDT pitches and
  protected indicator routing, including takeoffs, cathode links and shunts.
- [Indicator SMA And Resistor Assembly](#indicator-sma-and-resistor-assembly)
  and [2512 SMT Resistors](#2512-smt-resistors): exact lands, body/courtyard
  limits, mask/paste choices and the TE alternate-land acceptance hold.
- [Axial Forming Approval](#axial-forming-approval): remaining **earth-GDT**
  bend/pitch, height and process approval. [GDT_AC Forming Drawing](#gdt_ac-forming-drawing)
  is retained **only as historical B5G470L evidence**, not a current forming hold.
- [Hole Fit Evidence](#hole-fit-evidence) and
  [Body And Courtyard Evidence](#body-and-courtyard-evidence): hole/pad/ring
  schedule, pin/pattern/body envelopes and neighbour gaps.
- [Earth Terminal Edge Clearance](#earth-terminal-edge-clearance): J_EARTH
  extents, nominal/conditional edge margins and revised-outline/panel/fit acceptance.
- [SMT Via Relocation](#smt-via-relocation): approved westward vias/AB/BC stubs,
  unchanged stub Y endpoints, metric lands, aperture gaps and W1 process hold.
- [SMT AC Crossover](#smt-ac-crossover): front-only A/C takeoffs, front-B
  cutback, rear-B crossover, removed AC barrels and source-only clearance limits.
- [Stitching Via Identification](#stitching-via-identification): all **fourteen**
  protected **1.00 drill / 1.80 copper** vias by net/coordinate, both-side mask
  openings, no paste and selected untented/no fill/plug/cap process.

[README's master DFM policy](../README.md#via-and-component-hole-dfm) remains
the normative policy owner (**repository-only reference**).
[DFM_EVIDENCE.md](DFM_EVIDENCE.md) supplies drawing provenance and tolerance
proofs, not replacement policy or supplier approval. The local controls above
and the inspection duties below remain applicable without the root guides.

## Reviewed Components

[BOM.csv](BOM.csv), synchronized PCB/schematic and local libraries control the
machine population and sourcing identities. This human index identifies assembly
applicability, not purchases, stock, allocation or substitution approval.

The board has **16 electrical parts, all top-side: nine SMT and seven THT**,
plus four mechanical hole footprints. Expected inventory is **eight nets,
34 electrical terminals, 52 IPC records (18 SMT +30 plated +4 NPTH),
30 PTH hits (16 component +14 via),
four NPTH, F.Mask 52, B.Mask 34 and F.Paste 18 apertures**, with **nine local
footprints and six symbols**. These are design expectations, not a native-check
result or measured hardware acceptance.

| References | Current manufacturer / exact MPN / code | Assembly applicability |
| :--- | :--- | :--- |
| R1, R2 | **TE Connectivity 35212K2FT / C4129105** | Prototype population only; CGS 3521 / 2512 SMT, 2.2 kohm / 2 W / 1%, +/-100 ppm/C, AEC-Q200. [Retained alternative lands and mounting limits](#2512-smt-resistors); no insertion holes or axial standoff/forming. |
| D1-D4 | **Vishay General Semiconductor BYG23T-M3/TR / C145454** | SMA; D1/D2 series and D3/D4 negative output shunts. [Lands and polarity inspection](#indicator-sma-and-resistor-assembly); no diode holes. |
| GDT_AB, GDT_BC, GDT_AC | **Ruilon SMD5050-470NA / C39692533** | All three inter-core tubes are nonpolar SMT; [selected metric lands and processed-stencil hold](#smt-via-relocation), plus [AC crossover controls](#smt-ac-crossover). No AC insertion holes or raised forming requirement remain. |
| GDT_A_E, GDT_B_E, GDT_C_E | **Ruilon 2R470TD-8 / C2836978** | Formed THT from each core to EARTH; [forming limits](#axial-forming-approval) and [body-gap inspection](#body-and-courtyard-evidence). |
| J_IN, J_EARTH | **Cixi Kefa Elec KF128-7.62-3P / C474957** | Listed component data: **24 A / 300 V**, not an assembled rating or new verification. Confirm exact supplied-part applicability using the [existing Kefa evidence and rating caveat](#evidence-links). THT; opposite wire openings, [controlled pin fit](#hole-fit-evidence) and [body/panel envelope](#body-and-courtyard-evidence). |
| J_LED_A, J_LED_C | **Cixi Kefa Elec KF129-5.08-2P / C475092** | Listed component data: **24 A / 250 V**, not an assembled rating or new verification. Confirm exact supplied-part applicability using the [existing Kefa evidence and rating caveat](#evidence-links). THT; [distinct pad mappings](#placement-and-polarity), outward openings and [variant/lot acceptance](#hole-fit-evidence). |

Yageo SR2512FK-7W2K2L / C876850 is **not populated by this BOM**. Before its
production use, independently review its manufacturer/model, footprint/placement,
stencil/solder process and thermal evidence, deliberately update BOM/CAD/local
libraries/model/notes and repeat affected checks. TE prototype results do not
qualify Yageo or authorize an automatic substitution. Retired onsemi/MBE/PR02,
HP12, PS12 and Bencent B5G470L parts and other unapproved candidates are not
assembly substitutes.
Purchases, cancellations and allocation history belong to
[MATERIALS.md](../MATERIALS.md) (**repository-only reference**).

Component **5/20 kA impulse ratings**, heavy copper and paralleled EARTH pins do
not establish an assembled surge rating, equal sharing or a **72 A** terminal
assembly rating. Use [ELECTRICAL.md](ELECTRICAL.md) for circuit/fault limitations
and [DESIGN_BOUNDS.md](DESIGN_BOUNDS.md) for conditional current/thermal screens;
actual continuous-safe TEST and protection qualification remain separate holds.

## Drawing Conventions

- Dimensions are millimetres unless stated otherwise. Global coordinates are
  **top-view KiCad board coordinates**, X increasing east/right and Y increasing
  south/down. North is the edge at Y=94.50. Do not mirror these identification
  coordinates when identifying vias to CAM.
- `F.Fab` is an assembly aid. Diode, resistor and GDT boxes bound the published
  body dimensions, rounding the larger metric/inch limits outward. Kefa boxes
  are **controlled procurement envelopes**, not newly invented manufacturer
  guarantees. Inspect actual parts against them. Courtyards include the stated
  pose and assembly allowances; a drawing stroke is not extra body tolerance.
  LED arrows indicate the required wire-opening direction.
- Local footprint origins follow the placement table, including the authorized
  R1/R2 and D1/D2 moves and the 1.2.1 westward SMT-GDT placement. Use the native
  generated CPL, not a hand-maintained positive screen-Y table: native placement
  Y is negative for these positive board Y coordinates. Rotations -90 and 270
  degrees are equivalent. The assembler must
  approve its actual model origin, orientation and any centroid correction.

The native-generated **Assembly.pdf** overlays F.Fab, pad outlines, F.SilkS,
F.CrtYd and Edge.Cuts. **Assembly.txt** lists all sixteen
footprint anchors with exact MPN/footprint identity and all **34 electrical
terminal centres**, in both PCB and signed-Y fabrication coordinates. Use these
together to compare every supplier-model pin, not just its displayed centre.
Neither a courtyard midpoint nor a body-envelope midpoint is an approved
pick-and-place centroid. No centroid correction has been applied to the CPL.
Use the text's explicit pin numbers/nets: the tested KiCad 9.0.7 PDF
`--sketch-pads-on-fab-layers` output draws pad outlines but did not render pad
numbers, despite the CLI help wording. Saved plot-number toggles did not change
that native export, so no ineffective PCB plot-setting change is retained.

## Placement And Polarity

| References | Origin / rotation | Required placement and inspection |
| :--- | :--- | :--- |
| J_IN | (106.00, 122.50), 0 deg | Wire openings west. Pin 1 A at (106.00, 114.88), pin 2 B at (106.00, 122.50), pin 3 C at (106.00, 130.12). |
| J_EARTH | (155.00, 122.50), 180 deg | Wire openings east. Pin 1 at Y=130.12, pin 2 at Y=122.50, pin 3 at Y=114.88; all X=155.00 and all on EARTH. |
| J_LED_A | (145.50, 103.00), 90 deg | Openings north. Pin 1 LED_A_POS at (142.96, 103.00); pin 2 WIRE_B return at (148.04, 103.00). Embedded local pad tuples: pin 1 **(0,-2.54,90)**, pin 2 **(0,2.54,90)**. |
| J_LED_C | (145.50, 142.00), 270 deg | Openings south. Pin 1 LED_C_POS at (142.96, 142.00); pin 2 WIRE_B return at (148.04, 142.00). Embedded local pad tuples: pin 1 **(0,2.54,270)**, pin 2 **(0,-2.54,270)**. |
| D1, D2 | (130.80, 104.50) / (130.80, 140.50), 0 deg | BYG23T SMA series diodes. Cathode band east/right, K1 at X=132.90 to LED_A_POS/LED_C_POS; A2 at X=128.70 to Net-(D1-A)/Net-(D2-A). No diode insertion holes remain. |
| D3, D4 | (135.00, 99.00) / (135.00, 146.00), 180 deg | Same BYG23T-M3/TR SMA, **negative shunts**, not series parts. Cathode band west/left, K1 at X=132.90 to LED_A_POS/LED_C_POS; A2 at X=137.10 to WIRE_B. No EARTH connection. |
| R1, R2 | (120.00, 104.50) / (120.00, 140.50), 0 deg | Nonpolar, top-side SMT. Pad 1 at X=116.875 to WIRE_A/WIRE_C; pad 2 at X=123.125 to Net-(D1-A)/Net-(D2-A). Use the [prototype BOM population](#reviewed-components) and accept its [alternate-land process](#2512-smt-resistors). No holes or axial standoff/forming. |
| GDT_AB, GDT_BC | (115.00, 118.69) / (115.00, 126.31), 0 deg | Ruilon SMD5050-470NA. Pad 1 north, pad 2 south. AB connects A/B; BC connects B/C. Nonpolar tube, but preserve the specified footprint/net mapping. |
| GDT_AC | (123.70, 122.50), 0 deg | Ruilon SMD5050-470NA, north-south electrode axis. Pad 1 A at **(123.70, 120.50)**; pad 2 C at **(123.70, 124.50)**. Same reviewed SMT geometry as AB/BC; inspect the [front-only takeoffs and rear-B crossover](#smt-ac-crossover), not axial forming. |
| GDT_A_E, GDT_B_E, GDT_C_E | (138.62, 113.50), (138.62, 122.50), (138.62, 131.50), 0 deg | Ruilon 2R470TD-8, horizontal formed pitch 15.24. Pin 1 west at X=131.00 on A/B/C respectively; pin 2 east at X=146.24 on EARTH. Preserve 9.00 body-centre pitch; do not bend bodies together to ease insertion. |

J_LED_A and J_LED_C intentionally have **different local pad-number mappings**.
The embedded tuples are **(local X, local Y, stored pad angle in degrees)**.
Their 180-degree outward flip still leaves positive on the left in the top view;
do not make their rotations or local mappings identical.
Use `DogFence:KF129_5.08_2P_LED_A` and `DogFence:KF129_5.08_2P_LED_C` respectively;
never replace both with the same stock-library footprint. The local diode symbol
also explicitly names its anode-left/cathode-right mapping. Underside reference
text is mirrored for reading from below; it does not change electrical polarity.

Keep the takeoffs at **X=108.38** and the **1.80-wide F.Cu input/series/output
routing**. Straight D1-D3 / D2-D4 cathode links at **X=132.90** are each
**5.50 long, 1.80 wide on F.Cu**, at **Y=99.00..104.50** and
**140.50..146.00** respectively. Shunt anode-to-B routes to **J_LED_A/C pin 2**
are **1.80 wide on F.Cu**. Preserve the B.Cu returns and full-width rails/EARTH
under [Physical Guardrails](#physical-guardrails): **no folded branch or new via**.

## Indicator SMA And Resistor Assembly

All four diodes use the reviewed local **BYG23T_SMA_K_Right** footprint. The
original Vishay **89429, 25-Feb-2020, page 4** figure was visually read for this
selection: land length >=1.52, transverse width >=1.68, inner gap <=1.88 mm;
5.28 overall land span is marked **reference**, not a maximum. The selected
rectangular lands are **2.50 x 2.00 at local X=+/-2.10**, giving **1.70 inner
gap and 6.70 outside span**. Local pad 1 is +X/K, pad 2 -X/A. Copper/mask/paste
use zero effective mask/paste margins. Preserve all **eighteen** top paste
apertures: eight SMA, four resistor and six GDT; no via paste. This source
selection is not processed-stencil approval.

The diode `F.Fab` body box is **4.50 x 2.80**, with body height **<=2.29** and
maximum terminal span rounded outward to **5.29** from the metric/inch drawing.
Courtyard is **7.20 x 3.60**, **X=+/-3.60, Y=+/-1.80**, containing body plus
0.10 pose/0.25 assembly clearance and lands plus 0.25. Check bands and actual
supplier-model rotation. D1/D2 point right; D3/D4 point left. A 75 ns
**reverse-recovery** rating does not prove
instantaneous forward clamping below 5 V; electrical qualification is separate.

### 2512 SMT Resistors

These controls apply to the **TE Connectivity 35212K2FT** prototype population.
The **2026-09-11** independent review visually read **CGS 3521 Series, Data Sheet
9-1773463-5 Rev G, 02/2025, PDF pages 1-5**;
[DFM_EVIDENCE](DFM_EVIDENCE.md#te-3521-prototype-selection) records the source and
limits. The body fits the retained `DogFence:R_2512_6332Metric` envelope. Its
HP/PS-derived lands remain a **project-selected alternative**, not a manufacturer-exact
mechanical/electrical drop-in approval. No geometry change or mandatory reroute
follows from this evidence correction.

| Feature | Retained project geometry / TE body limit |
| :--- | :--- |
| Pad 1 / pad 2 local centres | **(-3.125, 0) / (+3.125, 0)**, both 0 degrees |
| Copper, F.Mask and F.Paste | **1.35 X x 3.70 Y rectangular lands**, undrilled, top only; zero effective mask margin, paste margin and paste ratio |
| Land spacing | **6.25 centres, 4.90 inner gap, 7.60 outside span** |
| Area per nominal copper/paste land | **4.995 mm^2**, not a measured solder deposit |
| Published body, TE p2 | L=6.35 +/-0.10, W=3.20 +/-0.20, H=0.55 +/-0.10; maxima **6.45 x 3.40 x 0.65** |
| Terminal bands, TE p2 | **l1=0.60 +/-0.25 top; l2=0.50 +/-0.20 bottom**; distinct from body height and PCB land dimensions |
| F.Fab maximum-body box | **X=+/-3.225, Y=+/-1.70**, 6.45 x 3.40 |
| F.CrtYd | **X=+/-4.05, Y=+/-2.10**, 8.10 x 4.20; contains lands plus 0.25 and maximum body plus 0.10 pose/0.25 assembly margin |

**TE p3 recommends different lands:** A is transverse width **3.00**, B is
longitudinal pad length **1.50**, and C is inner gap **5.00**. This gives
**1.50 X x 3.00 Y**, **6.50 centre pitch** and **8.00 outside span**; it does not
describe the retained **1.35 X x 3.70 Y / 4.90 gap** alternative above.
Centered toe/heel/side extensions are quantified in
[DFM_EVIDENCE](DFM_EVIDENCE.md#te-3521-body-and-lands-fit), not guaranteed fillets.
Zero additional mask/paste margins are the project's aperture choice, not a
manufacturer stencil specification. **W4 remains open** for supplier acceptance
of the retained alternate lands, actual placement, stencil and solder process.
Inspect actual chip seating, terminal wetting, fillets and solder volume. The
0.65 body-height maximum excludes solder-joint seating height; no arbitrary
axial-style gap is specified for this SMT part.

TE p3 also specifies a **four-layer PCB with 2 oz outer and 4 oz inner layers**.
The project remains **two-layer, 2 oz per side**. Transfer of the catalogue
power/derating basis to this mounting is conditional on adequate heat flow and
accepted assembly, with actual continuous thermal qualification under **W3**.
This is not proof that two layers fail or that 2 W is possible only on four
layers; it is not permission to change the protected stackup or routing.

[TE Rating And Mounting Basis](DFM_EVIDENCE.md#te-rating-and-mounting-basis)
preserves the catalogue ratings, TCR method and overload correction;
[DESIGN_BOUNDS](DESIGN_BOUNDS.md#thermal-screens) owns the conditional loss and
thermal screens. The model's temperature/reference inputs are engineering
assumptions, not TE-confirmed test endpoints. The inspected TE sheet does not
establish PS12's **five-second `2.5*RCWV` overload test**; PS pulse curves and
process limits do not qualify TE.

Heat flows from chip terminations through solder into local copper and the
board; wider traces do not reduce generated heat or establish a temperature.
The cathode links are downstream of D1/D2, not uninterrupted resistor-output
copper. **PR02's hot-spot limit, 75 K/W mounting example and axial standoff do
not apply to 3521.** Inspect actual chip/pad/PCB and gel/cable interface
temperatures for the intended population; no catalogue wattage or AEC-Q200
label establishes continuous-safe closed-OneGel TEST.

### PS12 And HP12 Investigation History

**Historical only, not population or sourcing instructions.** The
[2026-09-08 PS review](DFM_EVIDENCE.md#ps12-smt-selection-historical-review)
preserves Uni-Royal PS122WF2201T4E / C2793873, **SMD-SP-007 V.7, 08-Jan-2026**,
whose body/land recommendation matched the retained geometry. The
[2026-09-07 HP review](DFM_EVIDENCE.md#hp12-investigation-history) preserves
**SMD-SP-003 V.7, 08-Jan-2026**, the former land correction, rejected C-code,
retrieval limits and PDF **100 versus web 75 ppm/C** conflict. Those historical
recommendations, pulse/thermal data and test conditions are not TE specifications.

### Axial Resistor History

**Historical only, not population or assembly instructions:** checkpoint
6ba2a07 specified Vishay PR02000202201FA100 with external sourcing pending,
1.40/2.40 holes/pads, 15.24 formed pitch, <=0.83 wire and a >=1.00 body-gap requirement. Its
12.00 body-length envelope left 1.47 budgeted room per end for setback plus
bend centreline radius; no accepted forming profile or allocation was recorded.
Vishay 28729, 08-Jul-2025 p2/p3 distinguished axial Cu/A1 from radial options
and tape feed spacing. That evidence remains history; **no R1/R2 hole, bend or
axial standoff requirement survives the SMT conversion**.

### Axial Forming Approval

Only **the three earth GDTs** remain formed axial parts. For a simple
90-degree bend, straight setback `s` plus bend centreline radius
`Rc = Ri + d/2` must fit the available horizontal room. The table reserves
0.050 inward insertion-leg pattern error and 0.10 body projection/offset per
end. These are geometric ceilings, **not approved minimum setbacks or bend
radii**. Hole-position and insertion allowances are separate in the fit table.

| Formed part | Nominal pitch | Axial body/envelope maximum | Finished wire limit | Available `s + Rc` after 0.050 leg / 0.10 body allowance | Corresponding `s + Ri` ceiling |
| :--- | ---: | ---: | ---: | ---: | ---: |
| Earth 2R470TD-8 GDTs | 15.24 | 6.30 | 1.05 | **4.32** | **3.795** |

Obtain a dimensioned, accepted forming drawing for the earth-GDT family. It must
state the straight-setback datum/minimum, inside-radius minimum and achieved
maximum, body centring, complete pin-pattern tolerance, standoff range, maximum
assembled height, bottom lead protrusion and trimming/soldering sequence. The
retired AC development envelope remains below **as history only**, not an
earth-GDT height specification or an SMT assembly instruction.
No new height, lead-cut length or acceptable seal/coating stress is invented.

## GDT_AC Forming Drawing

**HISTORICAL, retired 2026-09-14: Bencent B5G470L / C5337217 only.** The drawing
and numbered method below preserve the former design and its unaccepted forming
process; they are **not current assembly, inspection or procurement requirements**.
The SMT conversion removes the AC overpass and its two component barrels, not
the separate protection/insulation qualification holds. Do not apply this
standoff or bend method to SMD5050-470NA or to the retained earth-GDT family.
Use [SMT AC Crossover](#smt-ac-crossover) for current construction.

Retired dimensional evidence, unchanged numerically:

| Former B5G470L control | Historical evidence / design envelope |
| :--- | :--- |
| Body and drawing | A2, 2018-01-03 p2: length 6 +/-0.2, diameter 5.5 +/-0.2, unformed overall 62 +/-2. `F.Fab` **5.72 X x 6.20 Y**, rounding the larger inch diameter outward; courtyard X=+/-3.25, Y=+/-9.30. |
| Forming room | **15.24 pitch**, 6.20 maximum axial body and **E wire <=0.90**; with 0.050 inward leg and 0.10 body allowance per end, `s + Rc <=4.37`, `s + Ri <=3.920`. Geometric ceilings, never approved bend minima. |
| Hole fit | **1.40 / 2.80 hole/pad**, minimum hole **1.32**, nominal ring **0.70**. Original 0.80 round lead has no tolerance; **E <=0.90** left **0.178579** residual after the separate position budget. Actual E/pattern and overpass forming acceptance were not obtained. No current AC hole remains. |

Side view looking along X, through X=125.80; **not to scale**. Z=0 is the highest
finished top PCB surface under the crossing, including its mask. The minimum is
not measured from the bottom of the board or from the component centreline.

```text
                         B5G470L, axis north-south
                         body length <=6.20
                          diameter <=5.72
                  +---------------------------+
       formed lead|        ceramic body       |formed lead
       +----------+---------------------------+----------+
       |          ^                           ^          |
       |          | g >=2.00 throughout the  |          |
       |          | raised body/lead overpass|          |
 Z=0 ==|==========v===========================v==========|== PCB top
       |                    WIRE_B                       |
       |              Y=120.90 to 124.10                 |
       |                                                 |
     A PTH                                             C PTH
   Y=114.88                                          Y=130.12
       |<--------------- pitch 15.24 ------------------->|

                    board centre Y=122.50
             X of both insertion legs =125.80
```

1. Use a supported lead-forming fixture before insertion. Support the lead
   between each bend and the body; do not transmit bending, twisting, or pulling
   force into the ceramic-to-metal seal. Do not bend against the PCB or re-form
   a soldered tube. Reject cracked, dropped, loose or otherwise damaged parts.
2. Form the vertical insertion legs to the 15.24 board pitch. The final forming
   drawing must specify approved bend radius, distance from the seal, pitch and
   height tolerances, springback, lead protrusion, and the process needed to
   hold them. **Those manufacturer/assembler approvals remain open.** Do not
   infer permissible bends from the 62 +/-2 unformed overall length.
3. Fixture the raised span with positive height margin above the 2.00 minimum.
   The development forming target is body underside **2.50 +/-0.25**, with
   **8.50 maximum complete assembled height** above the top PCB surface. These
   are drawing/inspection limits, not a claim of an accepted forming process.
   After soldering, every portion of the raised body, electrodes and lead span
   must maintain that minimum above the PCB. Only the intentional insertion
   legs descend to the A/C pads, outside the B-crossing corridor. No unsupported
   sag, solder bead or loose clipping may reduce the crossing clearance.
4. Inspect on every assembled board, unpowered and before encapsulation. Use a
   calibrated optical height measurement or non-damaging go/no-go gauge, from
   both sides and across the whole raised span, including its lowest point.
   Record the minimum and measurement uncertainty; accept only when the lower
   bound is at least 2.00. A gauge at the centre alone is insufficient.
5. Check the complete 8.50 height envelope, including lead bows and solder,
   with the actual formed part/fixture. The target's 2.75 upper underside plus
   5.72 body uses 8.47 of headroom. The body calculation alone does not bound
   a bowed lead or prove the COMBI lid clears the complete assembly.
6. This is a pre-encapsulation clearance check. Filling the space with gel does
   not preserve an air gap or prove equivalent impulse insulation. Any gel in
   this region requires the approved insulation/material process and relevant
   electrical qualification; do not count gel as an accepted substitute.

## Hole Fit Evidence

Use the selected part's **maximum finished** pin envelope, including plating and
any forming distortion. With the ordinary JLCPCB component-PTH tolerance:

```text
minimum finished hole = nominal finished hole - 0.08
round pin envelope    = maximum finished pin diameter
rectangular envelope  = sqrt(maximum width^2 + maximum thickness^2)
require: minimum finished hole >= maximum envelope + 0.10
```

The 0.10 is a minimum **diametral** assembly allowance after negative hole
tolerance, not a budget for arbitrary pitch/forming error. The design below
now also allocates `2 * (sqrt(2)*0.05 + 0.05) = 0.241421` diametrally for
independent hole-position and part-pattern errors. This uses the ordinary
JLCPCB +/-0.05 hole-position limit conservatively on each axis, plus a required
**0.050 radial per-pin part-pattern envelope after common rigid alignment**.
Inspect lean/non-collinearity through the full insertion length. This is a
procurement/formed-part acceptance requirement, not a manufacturer promise.

Original figures and tolerance associations have now been visually read in
[DFM_EVIDENCE.md](DFM_EVIDENCE.md). Where a finished-pin maximum is absent, the
following **E limits** are deliberately conservative incoming-part limits.
They make the file design explicit without pretending the allocated lot was
measured. Accept only `measured maximum + uncertainty <= limit`, on every
allocated controlled-envelope part for the five prototypes, including attrition.
No qualified yield or assembler acceptance of these limits is yet recorded.

| THT references / exact BOM identity | Nominal hole / pad | Minimum hole | Supported maximum pin envelope / calculation | Status |
| :--- | :--- | :--- | :--- | :--- |
| GDT_A_E, GDT_B_E, GDT_C_E: Ruilon 2R470TD-8, C2836978 | **1.50 / 3.00** | 1.42 | A3/A6 TD figures give **1.00 +/-0.05**, max **1.05**. `1.42 - 1.05 - 0.241421 = 0.128579 >=0.10`. | Known undersize corrected. Verify supplied revision, post-forming pin/pattern and nickel-lead process. |
| J_IN, J_EARTH: Cixi Kefa KF128-7.62-3P, C474957 | **2.00 / 3.20** | 1.92 | Nominal 0.90 x 0.80; **E <=1.10 x 1.00**, diagonal **1.486607**. Residual allowance **0.191972** after position budget. | File envelope selected; finished metal-pin/pattern/body lot acceptance HELD. |
| J_LED_A, J_LED_C: Cixi Kefa KF129-5.08-2P, C475092 | **2.00 / 2.80** | 1.92 | Same-revision drawings conflict, width 0.90/0.95 x thickness 0.80. **E <=1.15 x 1.00**, diagonal **1.523975**, covers both nominal variants. Residual allowance **0.154604**. | File envelope selected; actual variant and E/pattern/body lot acceptance HELD. |

- **Historical C1:** the onsemi diode holes were corrected from 0.90 to 1.10
  against a controlling 0.034-inch / 0.8636 maximum lead. The hybrid now replaces
  those parts with SMT: there are **no D1-D4 PTHs** and no current onsemi forming
  requirement. The prior source and evidence remain in checkpoint ad282e3.
- **Historical AC fit:** the former B5G470L holes and fit/forming limits are
  preserved with the [retired drawing](#gdt_ac-forming-drawing); they do not apply
  to the current undrilled SMT AC lands.
- Kefa's printed small-dimension +/-0.20 general table cites a **plastics**
  tolerance standard. Applying that band to metal cross-sections defines E;
  it does not prove a finished metal-pin guarantee. Its recommended 1.40
  **+0.10/-0.00** PCB hole is also not JLCPCB's ordinary nominal 1.40 process.
  The chosen 2.00 holes trade extra solder volume/fixturing for explicit fit
  margin. Neither stock CAD nor enlargement establishes actual solder fill.
- Nominal component rings are **0.75 earth GDT, 0.60 KF128, 0.40 KF129**.
  These exceed the 0.254 nominal
  two-layer/2 oz component-PTH design requirement; finished ring and barrel
  plating still depend on fabrication/registration tolerances and the quote.
- Inspect the earth-GDT formed patterns and accepted standoff after seating as
  well as before insertion. Larger holes must not permit collapse, tilt or
  unstable assembly. Do not spend the same allowance twice or force a rigid
  connector to meet a nominal gauge.
- Do not force insertion, clip rectangular pins to make them fit, or ream
  plated finished boards. Resolve the approved part/hole/process in the source,
  then regenerate and inspect production data.

## Body And Courtyard Evidence

Indicator envelopes and their drawing provenance are maintained with the
[SMA assembly controls](#indicator-sma-and-resistor-assembly) and
[2512 SMT resistor controls](#2512-smt-resistors). The retained Kefa/GDT
envelopes follow; do not trim any courtyard to hide interference.

| Item | Drawing evidence used | Source representation / remaining hold |
| :--- | :--- | :--- |
| Ruilon SMD5050-470NA, all three inter-core GDTs | SP-GDT-006 A3, 2024-08-19 p3: square **end face** A/B=5.0 +/-0.2; **axial** C=4.2 +/-0.3; electrode D=0.5 +/-0.1. | Retained `F.Fab` **5.21 X x 4.50 Y**; courtyard **6.00 X x 7.50 Y**, X=+/-3.00, Y=+/-3.75. Body height **<=5.21 before solder seating**, not 4.2. Metric lands selected below; actual assembled height still needs inspection. |
| Ruilon 2R470TD-8 | SP-GDT-017 A3, 2023-11-02 p3 and A6, 2025-10-16 p5, visually read TD figures agree: diameter 8 +/-0.2, length 6 +/-0.3. | `F.Fab` **6.30 X x 8.21 Y**, outward inch rounding; courtyard X=+/-9.40, Y=+/-4.46. Retain 9.00 centre pitch. |
| KF128-7.62-3P | Manufacturer and C474957 drawings A / 21.03.13; actual depth/rear datum, general tolerance table and end key now read. | **E body box** X=-6.00..5.40, Y=+/-12.50; courtyard X=-6.35..5.75, Y=+/-12.85. E includes end keys and uncertain pin-to-end datum, with allocated pose margin. Body height bound 14.60 above seating plane. |
| KF129-5.08-2P | Manufacturer and C475092 drawings A / 21.03.13; pin-width conflict retained. Body depth/rear datum, height, end key and table now read. | **E body box** X=-5.10..6.40, Y=+/-6.10; courtyard X=-5.45..6.75, Y=+/-6.45, in each existing local frame. Body height bound 18.80. Both intentional pad mappings remain unchanged. |

Require actual projected bodies to stay within these boxes expanded by **0.10
per side**, including translation/tilt, not additional unbounded rotation.
Courtyards include this projection plus >=0.25 assembly margin. The silk is a
placement aid, not the maximum-body envelope. DFM_EVIDENCE contains the complete
tolerance stack and incoming inspection method.

J_EARTH uses a three-sided silk aid: its west/rear silk edge would cross the
intentional EARTH via mask openings, so that edge is omitted. The full F.Fab
and courtyard envelopes are retained; no physical clearance is concealed.
J_IN likewise omits only its east/rear silk edge where the relocated rail-via
openings cross it. Its mirrored B.SilkS reference is at **(106.00,108.50)**,
outside those openings. The input footprint's pads, F.Fab and complete courtyard
are unchanged; a three-sided silk aid does not relax the body/fit controls.

Earth-GDT maximum projected gap is bounded below by
`9.00 - 8.21 - 2*0.10 = 0.59`; courtyard gap is 0.08. This is a dimensional
acceptance condition, **not a 1.00 air gap or an impulse-insulation claim**.
LED courtyards stop at **X=151.95**; H2/H4's protected courtyard west bounds are
now **X=157.50 - 3.45 = 154.05**, leaving **2.10 nominal gap**.

### Earth Terminal Edge Clearance

The **2026-09-15 approved mechanical extension** leaves J_EARTH at
**(155.00,122.50), 180 degrees**, with its existing E body reaching **X=161.00**,
or **161.10 including 0.10 projected pose**. Against the revised nominal east
edge **X=162.00**, the body including pose has **0.90 nominal margin**; the
retained courtyard at **X=161.35** has **0.65 nominal margin**. Both envelopes
are inside the nominal outline, not proven inside every manufactured board.
The [dated extension record](DFM_EVIDENCE.md#east-board-extension) distinguishes
this geometry from the old edge/mount calculations.

Retain the prior **CONDITIONAL 0.20 inward-route allowance** as a calculation
case only: an edge at **X=161.80** leaves **0.70 body margin including pose**
and **0.45 courtyard margin**. The 0.20 is **not an accepted supplier outline
tolerance**; these conditional margins are not guaranteed manufactured margins
or hardware approval. Obtain actual outline/edge and hole-position tolerances,
part/pose and panel/process acceptance before relying on them. Do not trim the
body/courtyard or move earth copper.

Use these **top-view PCB-coordinate** extents on the supplier's panel drawing:

| J_EARTH feature | X minimum..maximum | Y minimum..maximum |
| :--- | :--- | :--- |
| Controlled body envelope | 149.60..161.00 | 110.00..135.00 |
| Body including 0.10 projected pose | 149.50..161.10 | 109.90..135.10 |
| Retained F.CrtYd assembly envelope | 149.25..161.35 | 109.65..135.35 |

Use the full courtyard and revised outline/mounts in the panel, clamping and
depanelization review, together with source-matched assembly outputs. A rail,
adjacent board, clamp or cutter sweep must not occupy the envelope during the
relevant assembly/depanelization operation. The
assembler must specify any larger tool/wire/screwdriver clearance; the courtyard
alone is not a machining clearance or an approved panel design. Preserve the
four mounting keepouts and all functional copper. Five individual boards, not
five panels, remain the quantity requirement.

## SMT Via Relocation

The **2026-09-14 approved westward selection, hardware 1.2.1-dev**, changes
global placement, not local lands, body/courtyard geometry, parts or nets.
Only J_IN's overlapping silk edge/reference are corrected in the source/local
definition as described above. The **1.2.0-dev AC conversion** already adopted the same reviewed
SMT footprint as AB/BC. The shared metric land/process controls still apply to
**all six lands on all three SMT GDTs**. The AB/BC-specific via calculation below
is separate from AC's clearance to the retained GDT_B_E hole/pad.

- GDT_AB and GDT_BC are at **X=115.00**, moved **4.50 west from X=119.50**,
  retaining Y=118.69/126.31, zero rotation and nets. All three SMT GDTs use
  **5.50 X x 1.20 Y rectangular lands at local Y=+/-2.00** on
  F.Cu/F.Mask/F.Paste, undrilled, with zero effective
  mask margin, paste margin and paste ratio. SP-GDT-006 A3 p3's
  X1 leader is centre spacing, not the inner gap. **Select its printed metric
  4.00 spacing explicitly**; the contradictory 0.165-inch entry is not a
  manufacturer-approved erratum. The decision and tolerance-overlap calculation
  are in DFM_EVIDENCE. Supplier confirmation/processed stencil remain open.
- The four **F.Cu-only** AB/BC connection stubs move with the parts to **X=115.00**
  and retain **3.20 width**. The nine rail vias move **3.50 west**, from
  X=112.50/114.00/115.50 to **109.00/110.50/112.00**, with all Y coordinates,
  **1.00 drill / 1.80 copper** and untented process unchanged. All five EARTH
  vias, A/C main rails and EARTH geometry are unchanged. AC's **2.10 west** move
  and the front-B shortening follow the [crossover controls](#smt-ac-crossover);
  the rear rail/return geometry is unchanged from 1.2.0-dev.
- J_IN courtyard ends at global **X=111.75**, AB/BC courtyards begin at
  **112.00**, leaving **0.25**, reduced from **4.75** in 1.2.0-dev. The user
  explicitly approved this reduced drawing space; **no nominal courtyard clash
  is indicated, but physical fit, soldering and tool access are not proven**.
  Current AC neighbour gaps are in
  [Westward Clearance Evidence](DFM_EVIDENCE.md#westward-clearance-evidence),
  not inferred from either earlier AC placement.
- Keep the four 3.20-wide stub endpoints at **(115.00,116.19), (115.00,121.19),
  (115.00,123.81), (115.00,128.81)**. Their rail-side Y coordinates remain
  **114.88, 122.50, 122.50, 130.12**, respectively. They overlap the retained
  lands without extending the rounded copper further beneath the tubes.
  The land/mask/paste inner gap is **2.80**; the underlying
  connected copper gap is **1.80**. These are different dimensions. Do not
  blindly extend the tracks to the pad centres and reduce that copper gap.
  The **2.42** facing gap between **GDT_AB.2 and GDT_BC.1** is on the same
  **WIRE_B**, not an unlike-net differential-flashover case. Neither that gap
  nor the new **3.20 inter-GDT pad minimum** imposes a blanket front-side 3.00 rule.

**Historical relocation, not current AC construction:** the former B5G470L
moved from X=124.00 to 125.80, retaining A/C holes at Y=114.88/130.12 and 15.24
pitch. AB/BC courtyard east X=122.50 to its west X=122.55 left **0.05**; its
east X=129.05 to earth-GDT west X=129.22 left **0.17**. Those old drawing gaps
and the [raised-span method](#gdt_ac-forming-drawing) were not physical access
or forming approval. They are superseded for AC, not silently reused as SMT data.

Historical overlap at A: the via at Y=114.88 with radius 0.50 reached 115.38;
the original SMT aperture started at Y=115.19, overlapping the hole by **0.19**.
The three X positions on each rail lay inside the old aperture's X extent.
All nine rail holes were affected; the three B-rail holes faced both SMT parts.

Each current AB/BC aperture starts at **X=112.25**. For the nearest protected
via at **X=112.00**, the nearest aperture corner is offset by **dx=0.25, dy=1.21**:

```text
corner distance                  = sqrt(0.25^2 + 1.21^2) = 1.235556555
nominal drill-circle to aperture  = distance - 0.50      = 0.735556555
nominal full annulus to aperture  = distance - 0.90      = 0.335556555
```

The same minimum applies to all four AB/BC pads for `F.Mask` and `F.Paste` in the
saved zero-margin source. None exposes a protected via annulus. All vias now
have intentional mask openings, so **0.335556555** is the nominal open-annulus
to SMT-aperture budget, **not** a registration or solder-process guarantee.
Recheck actual processed mask/stencil apertures,
drill sizes, registration allowances and solder spread, not just pad centres.
The earlier **1.239713 hole / 0.839713 annulus** proof is preserved as
[1.2.0-dev historical evidence](DFM_EVIDENCE.md#smt-land-resolution), not the
current clearance.

At **X=109.00**, each first rail via is **3.00** from its J_IN pad centre at
X=106.00. The nominal via-opening to component-mask gap is
`3.00 - 0.90 - 1.60 = 0.50`; drill-circle to drill-circle gap is
`3.00 - 0.50 - 1.00 = 1.50`. A via drill to the component-mask edge is **0.90**,
not the drill-to-drill value. **Same-net component mask/paste is not exempt**
from full-hole/aperture checks.

The first two via centres on each rail, **X=109.00/110.50**
(VA1/VA2, VB1/VB2, VC1/VC2), now lie under the conservative **J_IN body/courtyard
projection**. Inspect complete openings/annuli, including the partial western
annulus projection at X=112.00, against actual moulding, seating, solder ingress,
drain-through and beads. No body-envelope drawing proves a physical collision
or safe seating over solder. Obtain actual fit/process acceptance; do not tent,
fill, shrink drills, trim courtyards or change the connector to hide a problem.

**Remaining W1 order/process hold, all three SMT GDTs:** figure associations
and the selected metric implementation are resolved, but the manufacturer's
contradictory inch entry and the actual solder process remain to accept. Paste area is **6.60
mm^2 per land**. For AB/BC this was down from 10.40 (36.54% at equal stencil
thickness); retired THT AC had no paste apertures. These areas are not measured
deposited solder volumes. Obtain the actual processed stencil and joint/profile
acceptance for all three tubes, preserving the below-tube insulation space.

## SMT AC Crossover

**Approved westward placement 2026-09-14, hardware 1.2.1-dev.** GDT_AC uses the
same reviewed `DogFence:SMD5050-470NA` geometry as AB/BC, at the [specified origin and pin
datums](#placement-and-polarity). Use the shared [metric land/process controls](#smt-via-relocation)
and [body/pose envelope](#body-and-courtyard-evidence); do not form or raise this
SMT part to recreate the retired overpass.

| Feature | Current construction / inspection control |
| :--- | :--- |
| A takeoff | **F.Cu only, 3.20 wide, X=123.70, Y=114.88..120.00** from the unchanged A rail. |
| C takeoff | **F.Cu only, 3.20 wide, X=123.70, Y=130.12..125.00** from the unchanged C rail. |
| Takeoff endpoints | Each stops **0.50 outward from its land centre**; round ends leave **1.80 connected-copper gap** under AC, distinct from the **2.80 land/mask/paste gap**. Do not extend either track to the land centre or add a rear A/C takeoff. |
| Front B cutback | Main **3.20** segment ends at **(115.00,122.50)**, shortened from X=121.00; its round cap reaches **X=116.60**. Retain **GDT_B_E pin 1's front PTH pad at (131.00,122.50)**, connected through the rear. No unnecessary right-hand front-B track stub is retained. |
| Rear B crossover | Main **6.00-wide B.Cu** segment remains **(106.00,122.50)..(131.00,122.50)**. It passes below **both AC lands and the entire body**, through nominal **1.440 FR-4**, not through an approved mask/gel insulation barrier. The return stem follows the approved **X=136.50** guardrail. |
| Interlayer links | The 1.2.0-dev conversion removed both old AC component holes/barrel links at **(125.80,114.88/130.12)**; they remain absent. All **14 dedicated stitching vias** are retained, with the nine rail vias moved west under the [current inventory](#stitching-via-identification). The five EARTH vias, main A/C rails, input and earth-GDT PTH links are unchanged. Removing the old AC barrels was not preservation of every former parallel path. |

AC and its two takeoffs move **2.10 west from X=125.80 to 123.70**, keeping all
Y coordinates and zero part rotation. Together with the specified AB/BC/stub,
nine rail-via and front-B changes, this exhausts the **2026-09-14 westward
placement/routing scope**. No other component, A/C main rail, rear B/return,
EARTH copper or indicator route change is authorized. The later
[east board extension](DFM_EVIDENCE.md#east-board-extension) changes only the east
outline and H2/H4; all other mounting controls remain protected. The
[dated clearance evidence](DFM_EVIDENCE.md#westward-clearance-evidence) records
full round-cap/land/hole/annulus and body-pose distances. In particular, no front
B copper is under the AC body, including the **0.10 projected pose allowance**;
this does not remove rear-B coupling or qualify the through-board crossover.

Retain the **>=3.00 rear A/B/C copper rule** and independent full-source
geometry guard **on B.Cu only**; do not extend it to the reviewed F.Cu SMT gaps.
The nominal **3.02** rear minimum has only **0.02** margin above that design
threshold, not a guaranteed finished-etch gap. Likewise **3.20 nominal inter-GDT
pad spacing is not a guaranteed finished 3.00 gap**. Accept actual processed CAM and
fabrication tolerances, stencil, seating and workmanship before an order/assembly
acceptance claim. See the [copper-area comparison](DFM_EVIDENCE.md#smt-ac-crossover-selection):
6.00 rear B does not restore the old ideal dual-layer cross-section or establish
a board current/surge rating. No physical impulse, mask/gel insulation or hardware
qualification is closed by removing the axial AC overpass.
Earth-GDT forming and **W5 enclosure/support/material/process acceptance**
remain open.

## Stitching Via Identification

Every listed location is a **via**, with 1.00 drill / 1.80 copper diameter through
F.Cu and B.Cu. IDs below are drawing identifiers, not extra electrical parts.
Compare this table with processed CAM by coordinates; do not select by drill
diameter alone.

| ID | Net | X | Y |
| :--- | :--- | ---: | ---: |
| VA1 | WIRE_A | 109.00 | 114.88 |
| VA2 | WIRE_A | 110.50 | 114.88 |
| VA3 | WIRE_A | 112.00 | 114.88 |
| VB1 | WIRE_B | 109.00 | 122.50 |
| VB2 | WIRE_B | 110.50 | 122.50 |
| VB3 | WIRE_B | 112.00 | 122.50 |
| VC1 | WIRE_C | 109.00 | 130.12 |
| VC2 | WIRE_C | 110.50 | 130.12 |
| VC3 | WIRE_C | 112.00 | 130.12 |
| VE1 | EARTH | 150.00 | 114.88 |
| VE2 | EARTH | 150.00 | 118.69 |
| VE3 | EARTH | 150.00 | 122.50 |
| VE4 | EARTH | 150.00 | 126.31 |
| VE5 | EARTH | 150.00 | 130.12 |

```text
TOP VIEW, X east ->          109.00  110.50  112.00           150.00
Y south
 114.88  WIRE_A                VA1     VA2     VA3               VE1
 118.69                                                        VE2
 122.50  WIRE_B                VB1     VB2     VB3               VE3
 126.31                                                        VE4
 130.12  WIRE_C                VC1     VC2     VC3               VE5
                                                               EARTH
```

- No filling by size. R1/R2 and GDT_AC have **no holes** after their SMT
  conversions. All sixteen remaining component PTH holes stay open for insertion; hole function,
  not size, remains controlling and no via is an insertion pad.
- Preserve all fourteen **1.2.1-dev** via locations, hole diameters and copper
  diameters.
  Obtain written CAM agreement not to reduce the protected via drills under
  ordinary via-hole adjustment practices.
- **Selected standard process: Untented, both sides, no fill/plug/cap.** Source
  openings are nominal **1.80 circular F.Mask/B.Mask**, no via paste. ENIG is
  exposed and wettable. Adjacent same-net rail-via mask openings intentionally
  overlap at 1.50 pitch; this is not an exception for a component paste opening
  over a hole. No reliable 1.00 tenting or special filling process is required.
- Inspect processed openings/drills and qualify solder ingress, drain-through,
  beads and cleanliness, including the [rail vias under J_IN's projection](#smt-via-relocation).
  Standard via drill adjustment is not authorized to shrink the protected
  geometry. Neither untented ENIG nor OneGel seals a hole.
- 70 micrometre surface copper is **not** 70 micrometre barrel copper. Agree and
  record any required minimum finished barrel copper separately from exterior
  copper weight and the fabricator's published average plating value.

## Thickness And Process

Use readily available **two-layer FR-4, 2 oz / 70 micrometres copper per side,
ENIG, nominal 1.60 finished thickness**. Green mask is the quote default, not
a performance qualification. Do not impose high-Tg laminate, a gold-thickness
upgrade or filled-via processing without reviewed need and supplier acceptance.
The source stackup is reconciled arithmetically to nominal **1.60**:

| Layer | Model thickness |
| :--- | ---: |
| F.Mask | 0.010 |
| F.Cu | 0.070 |
| FR-4 core | 1.440 |
| B.Cu | 0.070 |
| B.Mask | 0.010 |
| Total | 1.600 |

The former 1.510 core made the listed total 1.670. Copper remains 70 micrometres
on each side. The core value is a reconciled design model, not evidence of a
supplier's exact stock laminate. Confirm the finished-thickness measurement
convention, over-mask thickness, tolerance and ENIG process in the quote.
ENIG is a solderable finish, not a hermetic seal or terminal-corrosion guarantee.
Essentra LCBSBM-6-01A-RT listings give nominal 3.18 support hole, 1.57 panel and
9.53 spacing; they do not prove that the full finished-board tolerance fits.
Obtain the exact support drawing and approve latch engagement on actual boards
without changing the protected 3.20 mounting holes.

1. Confirm the exact order/lots, drawings, BOM identities, pin fit and forming
   approval before assembly. Do not substitute optional parts by pitch or a
   standard-looking footprint name. Approve five individual assembled boards,
   not five multi-up panels, with **no field soldering**; allocate any process
   samples/attrition explicitly.
2. Obtain order-specific acceptance for 2 oz both sides, ENIG, mixed SMT/THT,
   nickel/tin lead finishes, heavy solid-copper thermal load and any selective
   solder tooling. SMT reflow followed by controlled THT soldering is a candidate
   sequence, not an approved universal profile.
3. Establish a compatible profile for **all** installed parts, including SMA
   BYG23T and **TE 35212K2FT**. TE Rev G p5 lists solderability and resistance-to-
   soldering-heat tests, not an accepted JLCPCB stencil/reflow recipe. The PS V.7
   p8 SAC305 profile and two-reflow-cycle recommendation remain
   [historical PS evidence](DFM_EVIDENCE.md#rating-and-process), not automatically
   transferred TE process limits. The former onsemi solder limit applies only
   to the retired diode. The previously reviewed Ruilon/Bencent wave tables use
   up to 280 degrees C and 2-5 seconds; Bencent is now retired, so its table is
   historical evidence, not a fitted-part process limit. Different
   measurement locations and heat-test limits are not permission to expose
   every part to the most permissive number. Record actual joint/body
   temperatures, time, preheat and the approved alloy/flux/cleaning process.
4. Do not narrow the protected rails/returns, including **6.00 rear B**, delete
   vias, add restrictive thermal spokes, slit the earth bus or reduce isolation
   to ease soldering. Inspect wetting,
   hole fill, cold joints, solder volume and damage using accepted workmanship
   criteria for the agreed process. Escalate an incompatible process to design
   review instead of altering surge geometry in CAM.
5. Approve manufacturer-added panel rails, fiducials, tooling and depanelization
   clearance for the [revised outline and mounts](#physical-guardrails), including
   [J_EARTH edge-clearance acceptance](#earth-terminal-edge-clearance).
   No cuts/holes are permitted in protected copper or mounting keepouts.
   Check the actual processed top paste and mask,
   separate PTH/NPTH drills and placement model; raw exports alone are not CAM
   acceptance. Retain the agreed coordinate transform and sign convention.

## COMBI Dry-Fit Hold

These are later assembled-prototype/pre-encapsulation activities, **not
prerequisites for generating prototype artifacts**. No new enclosure, gel,
environmental or switch research is assigned by this board-only update.
Use an actual WISKA COMBI 308, actual Essentra supports and fully formed/soldered
board before potting. Its published **85 x 85 x 51 external** dimensions are not
usable internal space. Assembly height, tolerances and tool access are not
simulated by DRC.

1. Dry-fit the board/supports, three WAGO 221-613 through-splices, incoming and
   outgoing cable, actual glands, taps, earth wiring and lid-mounted indicators.
   Include cable bend radii, conductor stripping/ferrules if approved, wire
   opening directions, screwdriver reach, lid travel and service slack.
2. Measure minimum lid-to-component/lead clearance, actual seated SMT-GDT and
   formed earth-GDT heights, [J_EARTH body-to-edge clearance](#earth-terminal-edge-clearance)
   and support engagement. Nothing may press on the tubes, seals, solder joints
   or PCB. Record photographs and toleranced measurements;
   do not infer fit from a 65 x 56 bare-board rectangle.
3. Keep each A/B/C through-splice intact and connect the PCB as a tap, not a
   serial perimeter-current link. Keep EARTH separate from fence conductors and
   connect it only under the approved site bonding design. Do not directly bond
   a fence core or assume that TEST negative is protective earth.
4. Verify actual APEM Q10F5SXXSG02E polarity and mounting requirements. Family
   guidance is 0.20-0.25 Nm, not the legacy 1.5-2.0 Nm; use the exact supplied
   model instructions. Do not perform powered reversal tests until the
   protection design and controlled test method are approved.
5. Clean, dry and inspect before any WISKA **OneGel** encapsulation. It is a
   single-component silicone cartridge, **no mixing**, not MP0100. Resolve the
   manufacturer's conflicting cure/temperature fields and approve the actual
   dispensing, materials, cleanliness, thermal behavior and crossover insulation
   using [OneGel evidence](ENVIRONMENT_EVIDENCE.md#wiska-onegel). Retain **one unpotted
   reference prototype**. Potting and the enclosure's unmodified IP rating do
   not qualify the completed coastal installation.

## Acceptance Record

Before an actual prototype order, retain the accepted exact BOM/sourcing route,
applicable part drawings/fit limits, GDT forming and mixed-assembly process,
placement-model approval, processed CAM/stencil/drill review, panel plan and
accepted outline/edge/hole-position tolerances.
After assembly, record board serial/revision, BOM/lot, measured forming/pitch/
height, outline/mount positions, J_EARTH body-to-edge clearance with measurement
uncertainty, solder/workmanship and electrical inspection results. Compare with
the accepted limits; stop and resolve any unaccepted fit or process conflict.
Record later support/enclosure, continuous-duty and protection results under their separate
acceptance scopes, not as prerequisites for generating prototype files.

Open supplier facts are specific: quote/job allocation of **ten fitted TE
35212K2FT resistors and fifteen fitted Ruilon SMD5050-470NA tubes, each plus
supplier-defined attrition**, for five boards; acceptance of **TE's alternate
lands and the GDTs' selected metric lands**, stencil/solder process and actual placement;
allocated Kefa/GDT drawing/E/pattern/body compliance; **earth-GDT forming**; KF129 variant
and Ruilon metric/inch clarification; solder fill/profile; protected drills and
any required barrel minimum; actual J_IN seating/solder around the moved vias
and its **0.25 courtyard gap** to AB/BC; and the revised outline/mounts and
[J_EARTH edge/panel/fit acceptance](#earth-terminal-edge-clearance), not a
guaranteed finished margin from nominal or conditional arithmetic.
Untented fabrication is standard, not an unresolved 1.00 filling request. Apply the
[population/substitution restrictions](#reviewed-components) and
[artifact scope](#prototype-artifacts). No lot, supplier email, CAM acceptance
or hardware PASS is implied; basic workmanship on five boards is not field or
surge qualification. Fitted requirements are not purchases or allocation;
[MATERIALS](../MATERIALS.md) remains the procurement authority (**repository-only**).

## Evidence Links

Initial evidence was retrieved 2026-09-06; original figures were subsequently
resolved as recorded in DFM_EVIDENCE, with hybrid sources added 2026-09-07.
The 02661d8 HP12 visual/sourcing review is historical. The **2026-09-08 PS12
replacement review** independently visually checked PS pages **1/2/4/5/6/7/8**.
The **2026-09-11 TE evidence correction** independently visually checked original
Data Sheet **9-1773463-5 Rev G, 02/2025, PDF pages 1-5**: ratings/derating,
body/terminal bands, recommended lands/reference PCB and performance tables.
The earlier **03/2023** citation was not supported by the served PDF; no such
edition was retained in the inspected project `tmp/` or `/tmp/opencode`, so no
revision-to-revision comparison is asserted. Repeatable original-page access is
recorded in [DFM_EVIDENCE](DFM_EVIDENCE.md#figure-access).
PDF text extraction and public PDF-viewer page images are retrieval aids, not
supplier approval. The earlier BYG23T outline/land review remains identified
above. The **2026-09-14 AC selection** reuses the already reviewed Ruilon
**SP-GDT-006 A3, 2024-08-19** geometry; no fresh manufacturer retrieval or
approval is claimed. The later **1.2.1-dev westward selection on the same date**
changes only the approved global placement/routing, not those land/body sources
or their qualification status. The **2026-09-15 east board extension** changes
only the outline and H2/H4, with no fresh part/datasheet or supplier approval.
PS12/HP12/PR02/onsemi/MBE/B5G470L links preserve history,
not current population instructions.

- [Selected Vishay BYG23T-M3/TR, 89429, 25-Feb-2020](https://www.vishay.com/docs/89429/byg23t.pdf), [C145454 identity](https://www.lcsc.com/product-detail/C145454.html).
- [Selected TE Connectivity 35212K2FT, Data Sheet 9-1773463-5 Rev G, 02/2025](https://www.te.com/commerce/DocumentDelivery/DDEController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), [JLCPCB C4129105](https://jlcpcb.com/partdetail/C4129105), [LCSC C4129105](https://www.lcsc.com/product-detail/C4129105.html). Active prototype selection; pp1-2 catalogue ratings/working voltage/body, p3 different recommended lands and four-layer reference PCB, pp4-5 performance tests. These do not approve the retained alternate pattern or establish the former PS12 overload test for TE.
- [Unpopulated production variant: Yageo SR2512FK-7W2K2L / JLCPCB C876850](https://jlcpcb.com/partdetail/C876850). Direct listing verified 2026-09-11: YAGEO, exact MPN/code, 2.2 kohm / 2 W / 1% / +/-100 ppm/C / 2512. The earlier [Yageo PDF URL](https://www.yageo.com/upload/products/datasheet/r-chip/PYu-SR_51_RoHS_L_9.pdf) returned 404 during review; no complete current manufacturer/model/footprint/process/thermal acceptance is established here. No substitution into the TE prototype BOM is authorized by that identity check.
- [Historical PS12 family, SMD-SP-007 V.7, 08-Jan-2026](https://www.uni-royal.cn/en/images/userfile/file/1784854235b7c79f8d8a205c5d.pdf), [manufacturer PS12 page](https://www.uni-royal.cn/en/article.php?id=10109), [JLCPCB C2793873](https://jlcpcb.com/partdetail/C2793873), [LCSC C2793873](https://www.lcsc.com/product-detail/C2793873.html). Not current population or transferable TE process data.
- [Historical HP12 family, SMD-SP-003 V.7, 08-Jan-2026](https://www.uni-royal.cn/en/images/userfile/file/1784806233a2e6d381ea80b5d9.pdf), [manufacturer HP listing with conflicting TCR](https://www.uni-royal.cn/en/product.php?s=High-Power+Thick+Film+Chip+Res), [former intended HP122WF2201T4E distributor identity](https://store.nacsemi.com/products/detail?stock=XSJMZ0000010410). Retrieved NAC MOQ 3,600; no HP JLCPCB code mapping or allocation was established.
- Historical rejected C2791283 mapping: [LCSC identity](https://www.lcsc.com/product-detail/C2791283.html), [JLCPCB identity](https://jlcpcb.com/partdetail/UniRoyalElec-HP122WJ0472T4E/C2791283). Both identify HP122WJ0472T4E, **4.7 kohm / 5%**, neither the former intended HP122WF2201T4E nor PS122WF2201T4E.
- [Historical PR02, 28729, 08-Jul-2025](https://www.vishay.com/docs/28729/pr010203.pdf), [former PR02000202201FA100 sourcing reference](https://www.vishay.com/search?type=inv&query=PR02000202201FA100). Retired from the selected board; no past allocation or forming approval is implied.
- [onsemi 1N4001/D family/case drawing](https://www.onsemi.com/pdf/datasheet/1n4001-d.pdf), [C232439 onsemi identity](https://www.lcsc.com/product-detail/C232439.html).
- [Vishay document 28766](https://www.vishay.com/docs/28766/mbxsma.pdf).
- [Historical, retired Bencent B5G470L A2 via LCSC](https://datasheet.lcsc.com/datasheet/pdf/6471acbc3d87a8a4a9e5f7b8a245655d.pdf?productCode=C5337217).
- [Ruilon SMD5050 SP-GDT-006 A3 via LCSC](https://datasheet.lcsc.com/datasheet/pdf/ce8e2bf652ab9d180a3e88b2584bb613.pdf?productCode=C39692533).
- [Ruilon 2RD-8 SP-GDT-017 A3 via LCSC](https://datasheet.lcsc.com/datasheet/pdf/d0869b141c45d22998b36dee1e5e4d4c.pdf?productCode=C2836978), [manufacturer A6](https://www.ruilon.com.cn/Uploads/pdf/017-2rd-8%20series_a6.pdf). Confirm the revision applying to the allocated parts; do not merge differing temperature/other claims without approval.
- [Kefa KF128 manufacturer product/drawing links](https://www.kefaelectronic.com/KF128-7-5-7-62-PCB-Terminal-Block-pd45490974.html), [manufacturer KF128-7.62 drawing](https://jirorwxhqiillo5p.ldycdn.com/KF128-7.62-aidqiBpqKirRliSqmrqirloj.pdf), [exact C474957 distributed drawing](https://datasheet.lcsc.com/datasheet/pdf/2bd9ccda2e0f72df8237e78ea70a6d85.pdf?productCode=C474957).
- [Kefa KF129 manufacturer product/drawing links](https://www.kefaelectronic.com/KF129-5-0-5-08-PCB-Terminal-Block-pd47789974.html), [manufacturer KF129-5.08 drawing](https://irrorwxhqiillo5p.ldycdn.com/KF129-5.08-aidqiBpqKirRljSjorlrqlri.pdf), [exact C475092 distributed drawing](https://datasheet.lcsc.com/datasheet/pdf/99269cbb2dd06cf5383cf1cad04f20f7.pdf?productCode=C475092).
- [Supplementary KF128 family drawing image](https://www.alldatasheet.com/htmldatasheet2/1253243/ETC1/KF128/109/1/KF128.png), viewed at full resolution. This secondary, insufficiently identified nominal drawing does not replace the exact Kefa maximum/tolerance drawing. Manufacturer product-page and distributor ratings also differ; obtain exact supplied-part ratings rather than selecting the largest claim.
- [JLCPCB capabilities](https://jlcpcb.com/capabilities/pcb-capabilities), [component-hole tolerance](https://jlcpcb.com/help/article/difference-and-tolerance-explanation-between-via-and-pad-holes), [via covering](https://jlcpcb.com/help/article/pcb-via-covering).
- [WISKA COMBI 308 LG](https://www.wiska.co.uk/en/30/pde/10060400/combi-308-lg.html), [Essentra support listing](https://www.digikey.com/en/products/detail/essentra-components/LCBSBM-6-01A-RT/392198), [APEM indicator](https://www.apem.com/led-indicators/professional-grade-panel-mount-led-indicators/q10/q10f5sxxsg02e).

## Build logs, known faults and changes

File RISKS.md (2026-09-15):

# Electrical and Environmental Risks

**Draft revision: 1.2.1-dev. Production/field-release hold; prototype-file authorization is not hardware approval.**

This is a risk register and qualification boundary, not a safety certificate or measured reliability prediction. [Agreed requirements](REMEDIATION.md#agreed-requirements), the [issue register](REMEDIATION.md#issue-register) and [release gates](REMEDIATION.md#release-gates) control decisions. The [implemented circuit](pcb/ELECTRICAL.md#1-implemented-model) and [reviewed population](pcb/ASSEMBLY.md#reviewed-components) define the design under assessment, not qualified hardware. **C4, C5, W3, W1 and W4 remain open.**

**Gate P permits file-verified prototype artifacts with all five holds deferred, not closed.** Unresolved external sourcing still blocks publication; files do not authorize upload or order. Supplier CAM/placement/allocated parts and board-specific process/fit acceptance remain order tasks. Environmental/switch qualification and enclosure dry-fit after prototype receipt remain separate from file generation and the original A/B/C production/field gates.

Use [INSTALL.md](INSTALL.md) for safe installation/operation and [ACCEPTANCE.md](ACCEPTANCE.md) for separate workmanship, normal, selected negative-voltage protection, thermal, visibility, hub, material, RF/site and powered fault/surge qualification. No numerical failure probability, guaranteed service life, board surge-current rating or direct-strike protection is established here. Missing evidence is not proof of inevitable failure, but it prevents an unsupported safety claim.

Manufacturer sources and unresolved discrepancies are in [ENVIRONMENT_EVIDENCE](pcb/ENVIRONMENT_EVIDENCE.md). [MATERIALS](MATERIALS.md) owns purchases, reel labels and allocation, including [resistor procurement/history](MATERIALS.md#resistor-procurement-and-history).

## System Boundary

The design has **41 stations at 0, 100, ..., 4000 m and 82 external LEDs**, including distinct 0 m and 4000 m stations at the shed. Retaining the five earth-connected locations at 0, 1000, 2000, 3000 and 4000 m leaves **36 standard stations**. The five-prototype order is for controlled evaluation, not five-board proof of a full perimeter installation.

WAGO 221-613 through-splices maintain each core's perimeter path and tap the local PCB. Normal perimeter current does not traverse every PCB rail in series. Surge discharge current through a station's tap, PCB, terminals and earth path is a separate load case. A standard station without an external earth connection has no assured local common-mode discharge path.

Apply [INSTALL's six-independent-end functional matrix](INSTALL.md#functional-matrix), not an assumed switch terminal-number table. **TEST feeds Start A/C positive and returns at Start B DC negative; End A/B/C stay separately isolated.** OFF leaves all six ends independently accessible/isolated at the hub.

T1/T2 retain the actual transmitter's required **OEM protector arrangement**. RUN and TEST ties belong on the corresponding **source-side contacts**, not permanent boundary-side straps. No **End A/C common, opposite-end B return or dual-B negative return** is permitted in TEST; these can destroy the required cut indications.

### Containment and Switching

- **TEST and OFF disable RF containment.** Secure animals independently before either mode or any maintenance; do not use animals to test the boundary. Clear hub mode indication and the operator's deliberate restoration and verification of **RUN** are required. Typical TEST use is one to two hours, but continuous-safe normal TEST is required for accidental extended use; a timer or automatic RUN restoration is not the baseline safeguard.
- OFF is ordinary disconnection, not demonstrated lightning isolation, removal of all induced voltage, or safe maintenance isolation. Cable transients can flash over unsuitable contacts or couple into disconnected equipment. Do not handle the outdoor circuit or earthing during storms.
- The provisional **CA10.A364/WAA364** has eight poles, with **two extra poles unassigned**; follow [INSTALL's switch acceptance controls](INSTALL.md#switch-and-supply). Its 20 A thermal rating does not establish actual DC load breaking, contact development, insulation for this exposure, or **global break-before-make**. Manufacturer confirmation for the exact offered program must show all old-source paths open before any new-source path makes across the whole used program, in both directions. Physical terminal numbers remain unapproved; individual pole timing and static continuity alone are insufficient. Until confirmed, overlap or miswiring could inject TEST DC into the transmitter or defeat fault detection.
- RUN combines the cores only through the approved source contacts. In an ideal isolated AC loop, interchanging transmitter outputs may simply change phase; that is not a zero-risk conclusion for a real nonstandard loop, its protection, receiver response or coupled sources. Record the actual RF configuration and qualify it. No direction selector is required or approved.

## Diagnostic Limits

Use [INSTALL's clean-cut indications](INSTALL.md#clean-cut-indications) only for one clean cut site, healthy boards/GDTs and no extra inter-core short. The **first applicable state transition** locates the adjacent 100 m span, including **3900-4000 m**; it does not uniquely classify the broken cores. For multiple sites, follow [repair and retest](INSTALL.md#repair-and-retest): isolate sources and all six ends, repair the first located span and repeat TEST across all 41 stations. Qualification must exercise **all seven combinations over all 40 spans** using the real hub/final branch behavior, not merely disconnect one input from a single board.

| Failure / error | Consequence and diagnostic limitation | Required response |
| :--- | :--- | :--- |
| Failed-open LED, resistor, tap or terminal | A dark local indicator can resemble a cable fault. Healthy stations beyond a dark station suggest local trouble, but do not establish the cause alone. | Isolate and inspect the station and neighboring span; repair and retest. Do not label every dark LED a cable cut. |
| LED short or failed branch protection | May lose indication, change current/power or expose the LED to damage. A series resistor limits some current, not every fault stress. | Analyze final single-fault behavior and measure it; replace defective assemblies rather than improvise field soldering. |
| A-B or B-C cable short | Can collapse TEST voltage, trigger PSU hiccup or sustain a cable-limited current; RUN behavior may also change. | Do not assume the fuse clears. Isolate, locate and repair using the approved fault procedure. |
| A-C short or unintended field-side tie | Equal-potential conductors can look normal in healthy TEST yet backfeed across a later open and mask it. | Test shorts separately; the clean-cut truth table does not promise mixed open/short localization. No permanent field-side straps. |
| Additional End B negative connection | Provides another return and can mask a B-only cut. | Keep all three End connections separately isolated in TEST; verify the actual hub, not just an empty switch throw. |
| Failed-short or persistently conducting GDT | Can join cores or connect a core to earth, alter RF/TEST behavior and carry sustained source current. | Qualify shutdown/extinction and inspect/retest after a suspected event. No assumption that the fuse or low nominal voltage makes it safe. |
| Failed-open/degraded GDT | Normal LEDs and a DMM-open reading may persist while surge protection is lost or firing voltage has changed. | Use appropriate arrester/post-stress qualification and replacement criteria, not a continuity-only health claim. |
| Open fuse, source shutdown, wrong mode/polarity or poor hub connection | May make all indicators dark without a boundary cut. | Check the 0 m station, actual source status, voltage and accepted hub wiring first. Do not repeatedly reset or replace fuses without identifying the fault. |

Both LEDs on only demonstrate the expected local indication under the tested conditions, not freedom from all shorts, hidden arrester damage or RF problems. [Optional DMM checks](INSTALL.md#optional-dmm-checks) require the transmitter/PSU/backups disconnected and **all six boundary ends isolated**. Measure Start-to-End on each individual core, using verified cable data and commissioning baselines rather than zero or parallel-core resistance. Account for connected branch paths, and never megger through electronics.

## LED Reversal

The purchased baseline **APEM Q10F5SXXSG02E** is the **no-internal-resistor** indicator. Published family limits are **20 mA maximum forward current and 5 V maximum reverse voltage**, subject to exact-model temperature/pulse conditions. `02` does not make it a regulated 2 V device.

| Condition | Implemented behavior / remaining limitation |
| :--- | :--- |
| Reversed TEST supply / negative connector voltage | D3/D4 now provide forward-conducting negative shunts at LED_POS-to-B, after the series diodes. Unlike the retired series-only circuit, a local shunt path exists; its dynamic voltage and the physical LED harness remain unqualified. This is not proof of <=5 V reverse stress. |
| Reversed LED flying leads with correct supply | The series rectifier can be forward-biased while the LED is reverse-biased through the resistor. Limiting current does not establish a safe reverse voltage or prevent damage. |
| Swapped core taps / mixed polarity errors | Branches may see unexpected polarity, current paths or local voltage. They cannot be called harmless because the indicators remain dark. |
| Transient or RF stress | A DC clamp's nominal voltage and a rectifier's rating alone do not establish peak LED reverse voltage or forward pulse current. Switching, parasitic coupling and protection tolerances must be included. |

**User-accepted risk, 2026-09-07:** indicator damage from accidental low-voltage installation polarity errors is accepted, with spare LEDs for replacement. Reversed flying-lead survival is no longer a required feature; D3/D4 are also reverse-biased in that condition and do not protect it. Accepting replacement is not evidence of immunity or permission to continue powering suspect wiring. [Installation spares](MATERIALS.md#1-station-inventory) remain unallocated and must be additional to field and test requirements.

**C4 remains open for the implemented protection's ordinary-transient response.** D3/D4 BYG23T shunts have cathodes to LED positive and anodes to B; they are not extra series parts or positive-voltage/current regulators. The **75 ns reverse-recovery rating is not forward-clamp speed**; the [typical forward-recovery evidence](pcb/DESIGN_BOUNDS.md#fault-screen) does not establish a <=5 V LED transient bound. Assess actual RUN/TEST, switching and nearby-lightning response without imposing the historical 40-part circuit. The one-way cut model is not a reverse-leakage or transient solver.

Measure voltage at the **physical LED**, current and temperature with suitable isolated/differential methods and stated uncertainty, accounting for probe loading. Darkness, a **0.00 mA** display or a working LED after rewiring is not proof of safe reverse stress or negligible leakage. Correct suspect wiring only while isolated; do not continue energizing a miswired indicator to diagnose it visually.

## Source and Heating

### Fuse Coordination

The specified fuse is **Littelfuse 0217002.MXP, 2 A, 217 series**, in **Phoenix Contact UK 5-HESILED 60 / 3004139**. Published 217 data includes **DC interrupting ratings** applicable to the relevant variant/conditions. It is not correct to reject it solely because of a 250 V marking, nor to assume every overcurrent opens it immediately. Interrupting capacity concerns safely breaking an established fault; **time-current clearing coordination is the unresolved design issue** here.

Cable resistance can hold fault current below or near the fuse rating for a sustained period. A current-limited/hiccup PSU may supply short pulses and retries without enough heating to clear a fuse promptly. Use the exact fuse's time-current/I^2t and ambient data with the **actual source waveform**, prospective current and fault location. A calculated current above 2 A is not an automatic fuse-opening result. Include holder indication/leakage paths where relevant; its lamp is not proof of isolation or protection health.

The authorized [source configuration](INSTALL.md#switch-and-supply) uses **one MEAN WELL LRS-75-36 for TEST and the second as a disconnected spare**. No parallel, series, separate-channel or opposite-end feeding is authorized. Verify received nameplates and output settings. Adjustable output and hiccup overload behavior are not a coordination fix; a larger supply can change fault energy as well as normal margin. Do not substitute the legacy fault calculations, change a fuse value, or assume an ideal current source without a new analysis of the agreed same-end topology.

### Follow Current

Nominal **470 V DC sparkover** describes ignition under specified conditions, not the voltage needed to keep a GDT conducting. After ignition, these tubes have arc voltages roughly **10-15 V**. A powered 36 V source may therefore supply follow current, depending on the actual path, cable resistance, device extinction behavior and source dynamics. A glow-to-arc transition current is not a demonstrated holding-current limit.

Analyze/test hard and resistive faults, ignited and failed-short GDTs, near/middle/far locations, floating or bonded earth return paths, and source hiccup/restart sequences. Some resistive faults cause sustained heating without high enough current for prompt fuse operation. A tube may fail open and silently lose protection, or fail short and continue loading the circuit. Determine and verify a coordinated safe shutdown/extinction/recovery arrangement where needed. **C5 cannot be closed by documentation, a PSU upgrade, a fuse calculation alone, or an unpowered surge test.**

The [current fault screens](pcb/DESIGN_BOUNDS.md#fault-screen) illustrate limits on overcurrent-only protection: cable-limited ignited-GDT paths and resistive faults can dissipate sustained heat at source currents below the fuse rating. These are selected prospective load lines, not maximum fault bounds or observed latched failures. They do not establish physical extinction or non-extinction; actual holdover/source-recovery evidence remains necessary. D3/D4 do not alter the upstream GDT follow-current paths.

### Normal Duty

Same-end TEST has distributed loading and a source-to-far-end current gradient. Use the [TE-prototype / BYG23T load cases](pcb/ELECTRICAL.md#2-calculated-results) and [declared source/cable envelope](pcb/DESIGN_BOUNDS.md#evidence-and-inputs), not enforced source limits or guaranteed combined ratings. The historical restricted-voltage window was only a proposal; include actual adjustment, hub/interface losses, ripple and startup rather than treating PSU OVP as a precision operating limiter. Qualifying the real normal source range is an alternative to imposing an active cutoff. Include credible negligible-cable staging, not just five boards.

Use [DESIGN_BOUNDS's nonuniform current cases](pcb/DESIGN_BOUNDS.md#normal-current) and loose comparison floor, not retired PS12/PR02 evidence or unreviewed Yageo extrapolations. The high-drop/Rmax branch, zero-drop/Rmin neighbours and conditional clamp diversion are screening assumptions, not an exhaustive joint-tolerance minimum, measurement or guaranteed optical floor. Uniform loads can overstate the weakest LED's current. Clamp leakage diverts branch current rather than adding it again to source demand. Series-diode reverse leakage and OFF-state glow are not solved by the ideal one-way cut model.

The [thermal screens](pcb/DESIGN_BOUNDS.md#thermal-screens) depend on engineering resistance-reference and temperature assumptions, not verified TE test conditions. Resistor temperature is an input, not a self-heating result or qualified operating point. [TE's four-layer reference mounting](pcb/DFM_EVIDENCE.md#te-rating-and-mounting-basis) differs from this two-layer PCB. Applying catalogue power/derating requires evidence and measured chip/termination/pad/PCB and material-interface temperatures. The difference does not prove two-layer failure, but the catalogue curve alone cannot close W3; its zero-power ambient endpoint is not an acceptable powered-chip or gel temperature.

SMT terminations, solder lands and PCB copper may help heat rejection, but do not lower electrical loss or prove a cooler result. PR02's hot-spot, mounted thermal-resistance and axial standoff/forming data do not apply. No closed/gel-filled thermal test has been performed; the rating does not establish cool operation, material compatibility or long life.

Qualify **continuous-safe normal TEST**, separately from fault safety, using instrumented closed/potted source-end and far-end assemblies at the worst credible source/solar conditions. Check LEDs, resistors, new protection parts, terminals, cable, gel, seals and adhesive. Measure temperature, not touch. Also demonstrate **5 m daylight ON/OFF distinction at the final minimum field current and real angles**; increasing current to improve brightness requires renewed electrical/thermal/fit approval.

**TE prototype results do not qualify Yageo production.** Apply the [independent population/substitution review](pcb/ASSEMBLY.md#reviewed-components): manufacturer rating, land-pattern, thermal, pulse and process evidence, controlled BOM/CAD/library/model/note updates, reverification and applicable qualification. Matching resistance/wattage or procurement status does not establish interchangeable qualification or an implemented production BOM.

## Surges and Insulation

The user accepts potentially wholesale rebuilding after a **direct strike**.
No numerical probability follows from that decision. A damaging surge need
not be a direct hit: nearby lightning can induce voltage in the long cable or
raise local earth potential relative to remote cable/earth. The close A/B/C
cores can share much of the induced voltage (common mode), but imbalance,
connections and unequal protection firing can convert some to differential
voltage across an indicator branch. No station waveform has been measured.

More ordinary candidates are switching/interruption of cable current, contact
bounce or loose/arcing connections, and source startup/disturbances. These are
mechanisms to assess, not a claim that normal operation currently produces
destructive pulses. **Energized cattle fencing is now prohibited near the whole
boundary cable, stations and hub**; close-parallel cattle-wire coupling is a
withdrawn exposure scenario, not part of the accepted installation. Reintroducing
it requires reassessment before use, not an assumed safe clearance or automatic
acceptance of repeated failures. Ordinary switching/RUN and nearby-lightning
damage have not been waived wholesale.

There is no universal voltage threshold for "severe": peak voltage/current,
duration, source impedance, deposited energy, repetition and path determine
damage. The historical 950/1200 V screens are not measured field conditions.
[Bourns' exposed-DC note, 04/25](https://www.bourns.com/docs/technical-documents/technical-library/gas-discharge-tubes/application-notes/bourns_surge_protection_for_exposed_dc_power_supplies_applica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)
provides manufacturer context for direct/indirect lightning and powered GDT
follow current; its telecom test levels are **not adopted as DogFence requirements**.

Use the [reviewed arrester population](pcb/ASSEMBLY.md#reviewed-components) and [component evidence](pcb/ELECTRICAL.md#7-evidence-register). Keep component data distinct from complete-system performance:

| Mechanism | Risk / evidence needed |
| :--- | :--- |
| Impulse sparkover and residual voltage | A nominal 470 V GDT is not a 470 V transient clamp. Reviewed data at 1 kV/us gives up to **950 V** for SMD5050-470NA at all three inter-core positions, including GDT_AC, and **1100 V** for the 2R470TD-8 earth GDTs. Retired Bencent data does not bound the current AC part. Include lead/trace inductive overshoot and the final protected-load voltage. |
| Unequal firing and current paths | Different tubes, wire lengths, contact resistances and inductances prevent assuming simultaneous firing or equal sharing. One path may carry most of a transient, and common-mode firing can create differential stress. Measure the complete intended path and vulnerable residual voltages. |
| Component versus board ratings | Component 5/20 kA figures apply to their specified waveforms and test conditions. They do not rate the board, WAGO tap, terminal, solder joint, via barrel, cable or electrode path. The three `J_EARTH` positions share a net; individual terminal ampere ratings cannot simply be added. No assembled surge-current rating is established. |
| Pulse coordination | A rectifier's repetitive reverse rating or single forward-surge rating and a resistor's steady wattage do not establish arbitrary pulse survival or protect a 5 V-reverse LED. [TE's family ceilings and power-limited working-voltage calculation](pcb/DESIGN_BOUNDS.md#thermal-screens) are conditional catalogue data, not a system or pulse rating. The cited TE sheet does not establish the historical PS12 overload test or one-pulse curves. Do not transfer those data to TE or use TE results to qualify Yageo. Verify exact-part voltage, current, pulse energy, timing, repetition and powered recovery for the actual network. |
| Insulation | Cable working voltage, switch/terminal nominal voltage, PCB spacing and gel dielectric data are not a coordinated impulse-withstand specification. The possible residual voltage must be compatible with the actual cable, hub, indicators and wet/coastal assembly, or an approved protection/insulation change is needed. |
| Physical construction | Breaching the [layer-specific physical guardrails](pcb/ASSEMBLY.md#physical-guardrails) can weaken a discharge path or short conductors. Preserve A/C main rails on both faces, the exactly 6.00 mm rear B main rail, the front-B stop/rear-return geometry, all protected vias and EARTH copper/isolation. The **>=3.00 mm A/B/C inter-core rule applies to B.Cu only**; its nominal clearance does not qualify impulse insulation. GDT_AC is now SMT, not a formed overpass. Actual seating, body/electrode/fillet limits, laminate integrity and contamination still matter. |
| Manufacturing defects | Selected [via treatment](pcb/ASSEMBLY.md#stitching-via-identification) is **UNTENTED both sides, no via paste and no fill/plug/cap**. Adjacent same-net rail-via mask overlap is intentional; SMT mask/paste apertures must not overlap via holes or annuli. Exposed ENIG is wettable, not sealed: solder ingress/drain-through, loose beads, poor component barrel fill, damaged plating or placement can weaken a path. Inspect processed CAM/stencil/assembly data and samples; no protected-drill reduction is authorized. 2 oz surface copper does not specify barrel plating. |

[Assembly controls](pcb/ASSEMBLY.md#physical-guardrails) and [DFM evidence](pcb/DFM_EVIDENCE.md) distinguish body boxes, SMT lands and retained holes from actual fit. TE body containment does not approve its [alternate project lands](pcb/ASSEMBLY.md#2512-smt-resistors); supplier placement/stencil/solder acceptance remains required. No resistor/diode/AC insertion holes or axial resistor/AC forming/standoff remain. Retained Kefa [E limits](pcb/ASSEMBLY.md#hole-fit-evidence) are procurement envelopes, not guaranteed or measured lots; **W4 actual pin/pattern/body fit and solder/earth-GDT-forming acceptance remain open**. **W1 retains the Ruilon metric/inch contradiction and actual solder/stencil/CAM acceptance at all three SMT GDT positions**, alongside TE/BYG23T process review. File choices do not authorize further guardrail changes, folded routing or extra vias, or close production/field holds.

The SMT GDT_AC crossing separates front A/C copper from rear B through
**nominal 1.440 mm FR-4**, not the retired 2.00 mm raised air-gap construction.
That stackup model is neither a guaranteed finished dielectric minimum nor
qualified impulse insulation. Solder mask, a sleeve/tape or gel supplies no such
approval. Inspect actual post-assembly workmanship and qualify the intended
insulation/transient paths under [ACCEPTANCE](ACCEPTANCE.md#qualified-fault-tests).
The SMT body's **5.21 mm height maximum before solder seating** is not an assembled
height or COMBI-fit guarantee. There is no AC forming/height-gauge task; the
three earth GDTs still need accepted axial forming, and **W5's remaining
forming, support/enclosure and material/process holds stay open**. Supplier
manufacturing-process acceptance remains an order task; full COMBI dry-fit follows
prototype receipt before enclosure/field acceptance, not before Gate P files.

Qualified fault/surge work must cover the actual source, fuse/interface, boards, cable samples, enclosure/material system, OEM protectors and earthing as relevant to the declared exposure. Use rated differential/isolated instruments and competent laboratory methods; ordinary DMM or grounded-scope practices are not safe substitutes. Capture powered recovery and post-stress hidden damage. No direct-strike survival or untested rating follows from a passing bare-board continuity test or an individual arrester datasheet.

## Earthing and Touch

- A qualified installer must review the **actual building PE/electrodes**, regional DogWatch protection instructions and the site's bonding/lightning arrangements. The user proposes sharing local earth between the DogWatch protection and both shed-end boards; this is a site-design proposal to confirm, not permission to join arbitrary grounds.
- Five earth-connected station locations do not automatically require five separate rods. Do not install unbonded electrodes by default, directly earth an A/B/C core, or assume DC negative must be bonded to earth. Purchased rods, clamps and paired 2.5 mm^2 conductors do not establish acceptable sizing, placement, multiwire clamping or impulse performance.
- Retain the OEM transmitter protector(s) and applicable PE connection. Station GDTs do not replace the OEM network. Any LRS mains/chassis PE, overcurrent protection and enclosure segregation must follow the exact supply instructions and regional installation requirements; do not omit protective earth to float a measurement.
- Earth-potential rise, inductive voltage on earth leads and different remote electrode potentials can transfer a surge into the shed or nearby metalwork. **Touch and step potential** can endanger people and animals near conductors, electrodes and supporting fences. Specify conductor routes, bonding, accessible-metal treatment and electrode locations through the installer, including buried-service checks before ground work.
- Loose/corroded earth connections and unequal contact paths can increase residual voltage or redirect discharge. Multiple terminal positions are not guaranteed redundant protection or equal sharing. Provide compatible clamps, mechanical protection and inspectable connections; record the required site verification and maintenance.
- OFF or a removed source fuse does not make a long outdoor line lightning-safe. Isolate mains/PSU/transmitter/backups and all six ends before ordinary wiring checks, verify de-energization, and avoid storms. Do not disconnect protective earth casually during troubleshooting. Use the separate laboratory procedure for abnormal-voltage testing.

## Site and Materials

| Exposure / material | Known facts and remaining controls |
| :--- | :--- |
| Coastal climate / sun | Site is on the Isle of Man, less than 1 km from the coast, with frequent rain, salt and condensation. Observed ambient is about **-10 to +30 degrees C**, with some boxes in direct sun. This is not a lifetime weather envelope; internal gel/component temperature can exceed ambient. Establish solar/thermal, moisture and corrosion limits for the actual assembly. |
| Cable identity | User-confirmed **AMC Oceanflex CM03/05.100** reel labels and **red, black and PLAIN green** cores are recorded in MATERIALS. [AMC 2026 Update V.3](pcb/ENVIRONMENT_EVIDENCE.md#amc-oceanflex-cable) gives **60 V max DC, -30 to +70 degrees C** complete-cable service. The [standard-resistance ceiling](pcb/DESIGN_BOUNDS.md#evidence-and-inputs) is conditional, not a reel measurement; reconcile the labelled-strand/standard construction discrepancy and supplied-revision applicability, not product identity or colours. |
| Cable suitability | The older listing's 105-degree core reference is not a complete-cable rating. Long-term exposed-weather/UV, wet-conduit and impulse suitability need evidence; do not assume arctic or mains ratings. A 60 V working rating does not establish surge withstand or inevitable failure at every short overvoltage. **GREEN/YELLOW IS NOT AN ACTIVE FENCE CONDUCTOR**, even if re-sleeved; the confirmed core is plain green. |
| Route and mechanics | Cable is mostly 0.3-1.0 m above ground on timber fencing with horizontal metal wire strands and no electrical connection to them. Driveway/gate conduit may be wet. Prevent abrasion, strain, animal/strimmer damage, water tracking and unsuitable bends. Raised COMBI installations are not intended for continuous submersion. |
| Enclosure / entry seals | COMBI 308 is **polypropylene (PP) with a TPE gasket, not polycarbonate**. Its original IP66 membrane/IP67 specified-gland arrangements do not automatically rate drilled indicator holes, different glands, plugs or a gel-filled assembly. Select glands for actual jacket diameter and validate the complete seal/strain-relief arrangement. No hermetic or automatic IP68 claim is supported. |
| OneGel | Confirmed **WISKA OneGel, not MP0100: single-component cartridge, no mixing**. [Manufacturer cure/temperature conflicts](pcb/ENVIRONMENT_EVIDENCE.md#wiska-onegel) require supplied-lot clarification, not an assumed curing step or self-levelling pour. **No thermal conductivity is published in the reviewed sources.** Validate material compatibility, dispensing/coverage/voids and re-entry, including actual WAGO 221-613 contacts/housings; unrelated Gelbox system evidence is not approval. Gel can alter heat flow or retain contamination and does not guarantee sealing or lifetime. |
| Supports and fit | Essentra **LCBSBM-6-01A-RT** nominal hole/panel/spacing data must be checked against finished board tolerances, COMBI 308's PP substrate, adhesive instructions and retention. Use the [current J_EARTH edge/body/pose and courtyard controls](pcb/ASSEMBLY.md#earth-terminal-edge-clearance) with the revised outline/mounts; nominal in-board margins and a bare-board rectangle are not enclosure-fit approval. Complete dry-fit includes WAGOs, glands, cable bends, earth wires, complete GDT height, lid LEDs and screwdriver access. Do not assume gel permanently carries the PCB after adhesive failure. |
| LED seals and visibility | Use exact **Q10F5SXXSG02E** mounting instructions; published Q10 torque guidance is **0.20-0.25 Nm**, subject to model confirmation. Excess torque can damage the lid/seal. Confirm 5 m full-daylight visibility at minimum current and actual angles; sunlight can make an OFF lens appear coloured. |
| Surface finish / ageing | ENIG is an assembly finish, not a pore-free lifetime seal over all conductors. Tinned cores, connector plating and gel do not eliminate salt ingress, capillary wicking, loosened joints, solder fatigue, polymer ageing or maintenance needs. Verify actual material compatibility and use bounded evidence, not multi-decade guarantees. |

### Cattle-Fence Prohibition

The supporting fence is **not energized**. Apply [INSTALL's prohibition](INSTALL.md#cattle-fence-prohibition) on energized cattle fencing near the **entire 4 km boundary cable, every station and the hub**, not only the shed. Inspect and maintain this restriction instead of testing the withdrawn close-parallel exposure. If land use changes or the hazard returns, stop work/use, arrange safe isolation and reassess before use.

No numerical safe separation follows from the prohibition, and plastic conduit is not electromagnetic shielding. It removes the previously declared close-cattle-wire exposure from the installation scope, not every induced voltage, nearby-lightning event or earth-potential difference. RF/site qualification still uses the actual cable, station loading, fence construction/height, transmitter/receiver and regional earthing arrangement. A short five-board bench exercise does not establish site behavior or endurance.

## Residual Holds

**Gate P is the authorized file-verified prototype-artifact scope, separate from the original A/B/C production/field gates.** It retains all strict file/sourcing checks and records all five engineering holds as deferred, not closed. Original Gate A remains held by unresolved electrical and part/land-pattern acceptance; B by the required order/fit/process/CAM evidence; C by hardware/site qualification. Neither P nor a generated ZIP authorizes upload, purchase or use. Refer to [REMEDIATION.md](REMEDIATION.md), not this draft as a live completion checklist.

In particular, **C4 LED transient qualification**, **C5 source/GDT coordination**, **W3 actual continuous thermal behavior** and **W1/W4 process/fit acceptance** remain open. Unresolved external rows still block both publication modes. Neither stock nor an order establishes PCBA-job allocation; whole-BOM `allocation_verified` remains `false`. Latest file/publication results belong to [REMEDIATION](REMEDIATION.md#east-board-extension), not this risk register; an earlier package does not verify the east extension or changed controlled notes. Keep outstanding switch, source, cable, OneGel, enclosure, thermal/visibility/RF/site and earthing qualification explicit without restarting that research for prototype files. Retain an unpotted reference and obtain approval for additional samples when the existing qualification scope requires them.

After suspected surge damage, ingress, mechanical impact, repeated source trips or anomalous indications, independently contain animals, isolate safely, inspect and repair, then repeat the relevant checks and the TEST repair/retest workflow before the operator restores RUN. Agree inspection/replacement intervals for the actual coastal site and OEM/material requirements. Visible normal operation alone cannot certify a hidden arrester or insulation path as healthy, and no zero-risk or fixed multi-decade service promise is made.

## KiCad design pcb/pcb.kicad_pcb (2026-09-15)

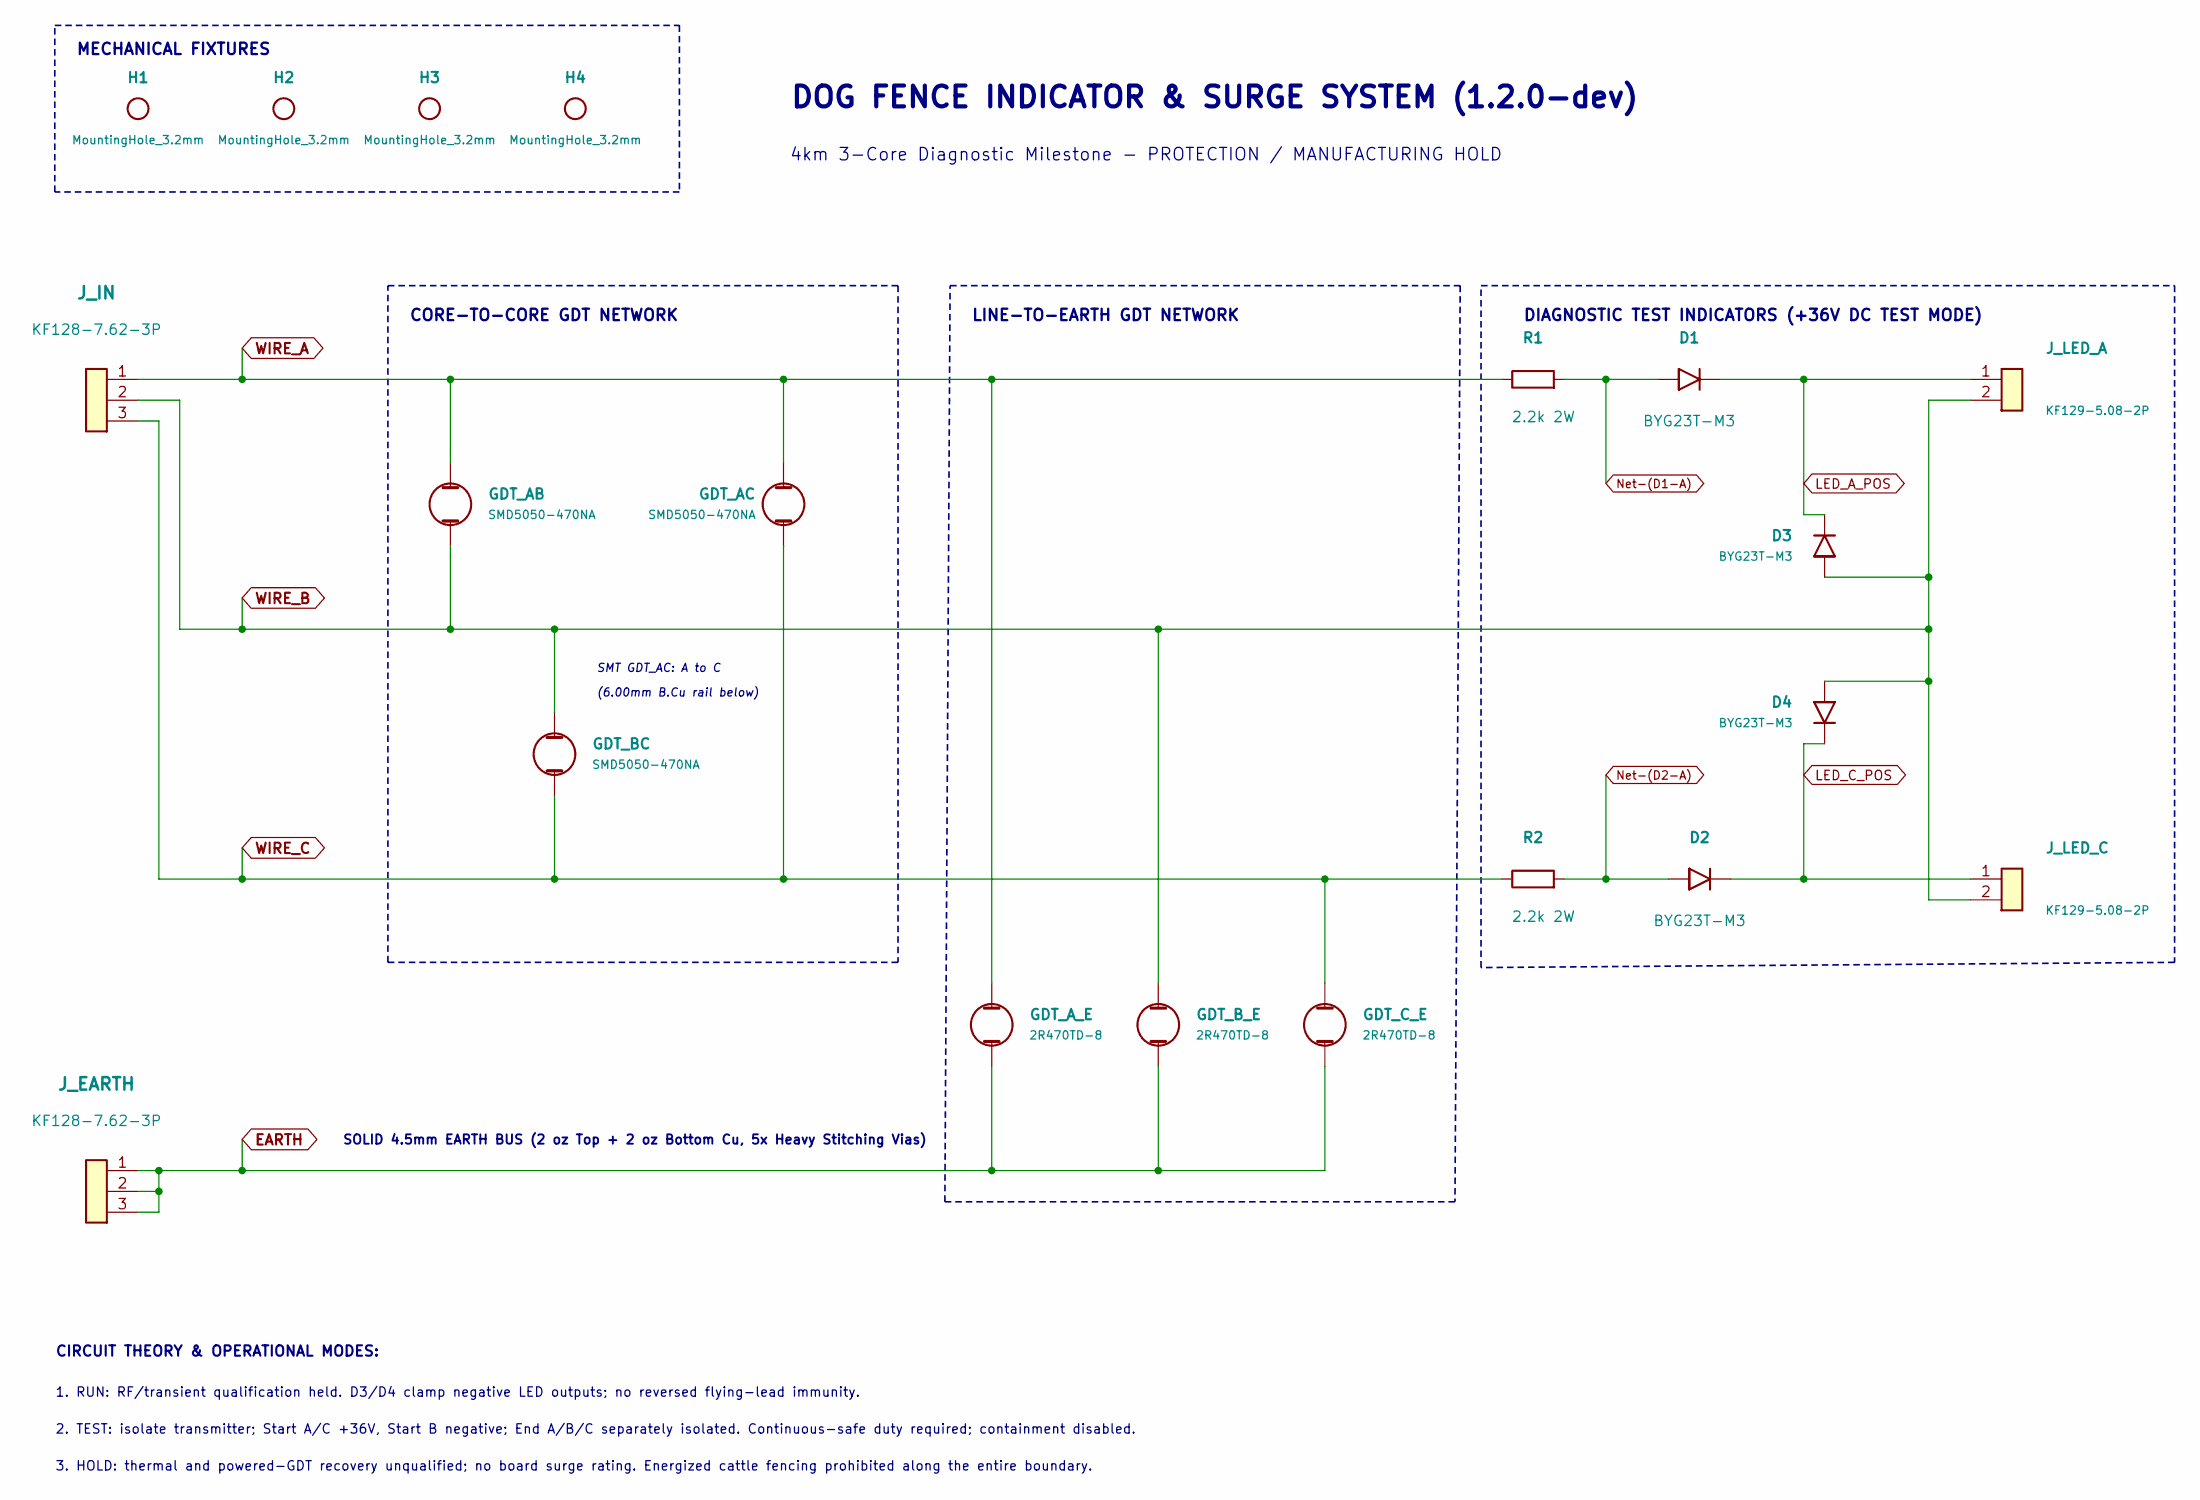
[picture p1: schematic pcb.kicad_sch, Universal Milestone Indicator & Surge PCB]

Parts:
D1, D2, D3, D4: BYG23T-M3; BYG23T_SMA_K_Right; MPN BYG23T-M3/TR; LCSC C145454
GDT_AB: SMD5050-470NA; MPN SMD5050-470NA; LCSC C39692533
GDT_AC: SMD5050-470NA; MPN SMD5050-470NA; LCSC C39692533
GDT_A_E: 2R470TD-8; 2R470TD-8_P15.24mm; MPN 2R470TD-8; LCSC C2836978
GDT_BC: SMD5050-470NA; MPN SMD5050-470NA; LCSC C39692533
GDT_B_E: 2R470TD-8; 2R470TD-8_P15.24mm; MPN 2R470TD-8; LCSC C2836978
GDT_C_E: 2R470TD-8; 2R470TD-8_P15.24mm; MPN 2R470TD-8; LCSC C2836978
H1, H2, H3, H4: MountingHole_3.2mm
J_EARTH: KF128-7.62-3P; KF128_7.62_3P_Earth; MPN KF128-7.62-3P; LCSC C474957
J_IN: KF128-7.62-3P; KF128_7.62_3P_Input; MPN KF128-7.62-3P; LCSC C474957
J_LED_A: KF129-5.08-2P; KF129_5.08_2P_LED_A; MPN KF129-5.08-2P; LCSC C475092
J_LED_C: KF129-5.08-2P; KF129_5.08_2P_LED_C; MPN KF129-5.08-2P; LCSC C475092
R1, R2: 2.2k 2W; R_2512_6332Metric; MPN 35212K2FT; LCSC C4129105

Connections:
EARTH: GDT_A_E.2, GDT_B_E.2, GDT_C_E.2, J_EARTH.1, J_EARTH.2, J_EARTH.3
LED_A_POS: D1.1 (K), D3.1 (K), J_LED_A.1
LED_C_POS: D2.1 (K), D4.1 (K), J_LED_C.1
unnamed: D1.2 (A), R1.2
unnamed: D2.2 (A), R2.2
WIRE_A: GDT_AB.1, GDT_AC.1, GDT_A_E.1, J_IN.1, R1.1
WIRE_B: D3.2 (A), D4.2 (A), GDT_AB.2, GDT_BC.1, GDT_B_E.1, J_IN.2, J_LED_A.2, J_LED_C.2
WIRE_C: GDT_AC.2, GDT_BC.2, GDT_C_E.1, J_IN.3, R2.1

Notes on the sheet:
MECHANICAL FIXTURES
CORE-TO-CORE GDT NETWORK
LINE-TO-EARTH GDT NETWORK
DIAGNOSTIC TEST INDICATORS (+36V DC TEST MODE)
DOG FENCE INDICATOR & SURGE SYSTEM (1.2.0-dev)
4km 3-Core Diagnostic Milestone - PROTECTION / MANUFACTURING HOLD
CIRCUIT THEORY & OPERATIONAL MODES:
SMT GDT_AC: A to C
SOLID 4.5mm EARTH BUS (2 oz Top + 2 oz Bottom Cu, 5x Heavy Stitching Vias)
1. RUN: RF/transient qualification held. D3/D4 clamp negative LED outputs; no reversed flying-lead immunity.
2. TEST: isolate transmitter; Start A/C +36V, Start B negative; End A/B/C separately isolated. Continuous-safe duty required; containment disabled.
3. HOLD: thermal and powered-GDT recovery unqualified; no board surge rating. Energized cattle fencing prohibited along the entire boundary.
(6.00mm B.Cu rail below)

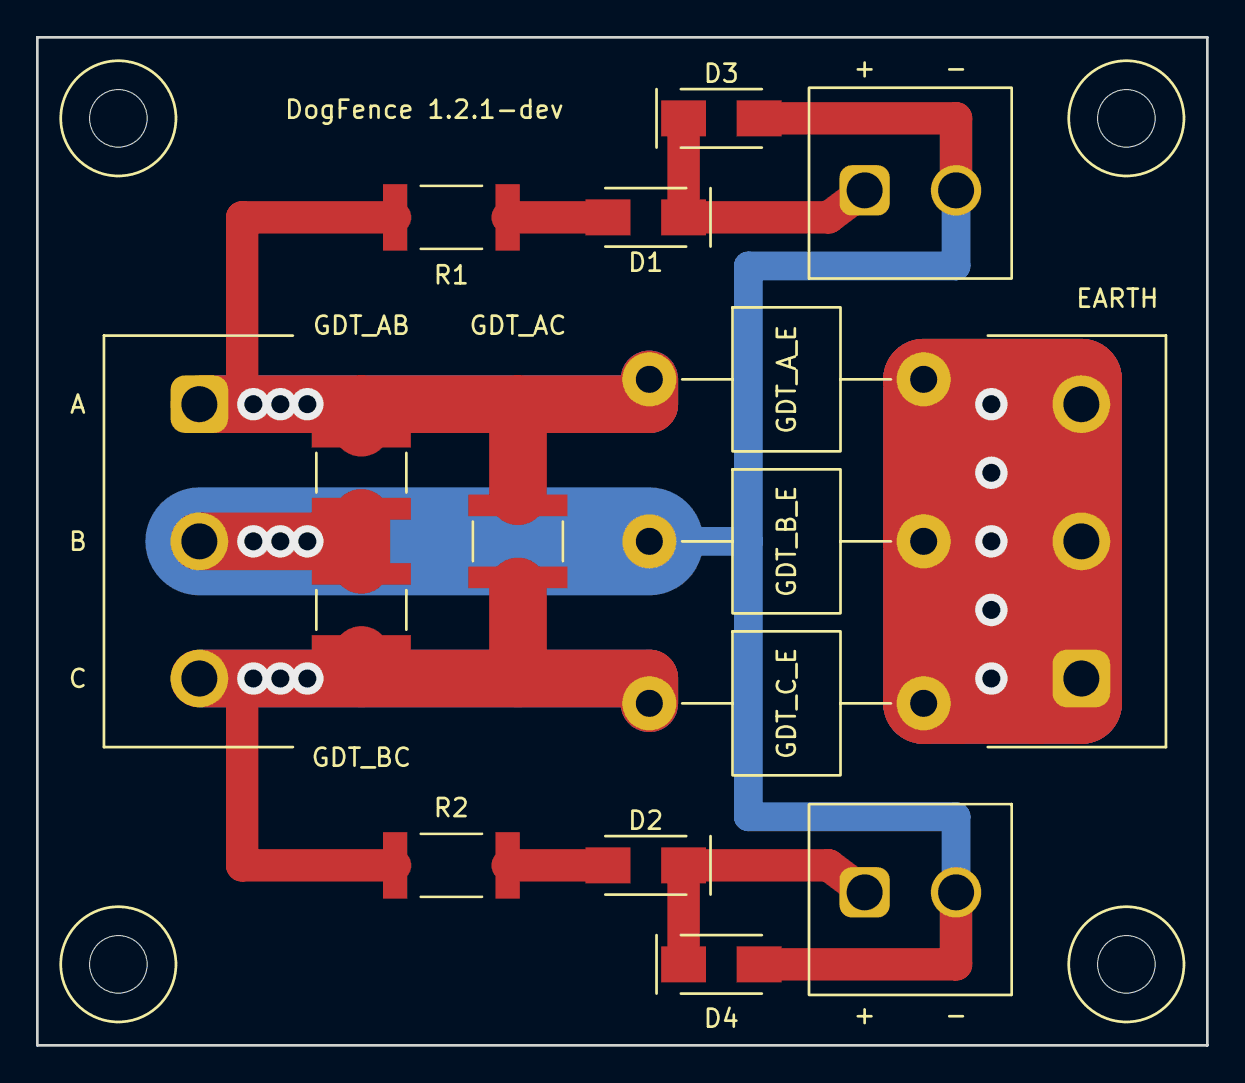
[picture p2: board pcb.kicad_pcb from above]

Board: 2 copper layers, 65.0 x 56.0 mm, 20 parts (0 on the bottom side), 8 nets.

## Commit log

2026-08-23 Dogfence milestone indicators 1.0
    [BOM.csv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]
2026-08-23 Shift to 2.2k resistors and 2V LEDs for brightness
    [BOM.csv, pcb.kicad_pcb, pcb.kicad_sch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]
2026-08-23 Regenerate Gerbers
    [pcb-B_Adhesive.gbr, pcb-B_Courtyard.gbr, pcb-B_Cu.gbr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]
2026-08-23 Add makefile for order automation
    [pcb.kicad_pcb]
2026-08-23 Clean up pcb/ generated files in favour of Makefile and build/ dir
    [pcb-B_Adhesive.gbr, pcb-B_Courtyard.gbr, pcb-B_Cu.gbr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]
2026-08-23 v1.0.2 thanks to Kimi K3, cleanup LED_C pin semantics and docs
    [pcb.kicad_pcb, pcb.kicad_sch]
2026-08-23 Clarify LED_C orientation text for order process
2026-09-05 Gemini 3.8 Flash improvements to GDT locations and completeness
    [BOM.csv, pcb.kicad_pcb, pcb.kicad_sch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]
2026-09-05 Avoid short on back side Wire B return and wires A&C. Gemini 3.8 Flash.
    [pcb.kicad_pcb]
2026-09-05 Addressed surge flash concern between Wire B returns and EARTH on the back side
    [pcb.kicad_pcb]
2026-09-05 Add courtyards for components that were clashing.
    [pcb.kicad_pcb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]
2026-09-06 Widen the board for better clearances
    [pcb.kicad_pcb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]
2026-09-06 Clean up font usage
    [pcb.kicad_pcb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]
2026-09-06 Improve board layout symmetry
    [pcb.kicad_pcb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]
2026-09-06 Widen the board and shift components for clearer legibility of guide marks
    [pcb.kicad_pcb]
2026-09-06 Review component assignments in light of JLCPCB stock availability
    [BOM.csv, pcb.kicad_pcb, pcb.kicad_sch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]
2026-09-06 Review courtyards and clearances
    [pcb.kicad_pcb]
2026-09-06 COnduct review for board correctness and part availability
2026-09-06 Clean up schematic to align with PCB
    [pcb.kicad_pcb, pcb.kicad_sch]
2026-09-06 Improve EARTH front and back side design
    [pcb.kicad_pcb]
2026-09-06 Clean up schematic for visual clarity and overlaps
    [pcb.kicad_sch]
2026-09-06 Ignore all KiCad lock files
2026-09-06 Tweak schematic for visual clarity
    [pcb.kicad_sch]
2026-09-06 Tighten the two review prompts
2026-09-06 Make note of vertical air gap standoff requirement
2026-09-06 Improve review prompt and record LED options
2026-09-07 Implement guarded remediation and manufacturing verification
    Add complete-project checks, native manufacturing validation, electrical regressions, and bounded PCB/library corrections for 1.2.0-dev. Preserve unresolved protection, fit/process, and hardware qualification holds.
    [BOM.csv, pcb.kicad_pcb, pcb.kicad_sch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]
2026-09-07 Checkpoint DFM remediation and simplified protection scope
    [pcb.kicad_pcb]
2026-09-07 Add diode to PCB to prevent reverse flow across LEDs
    [BOM.csv, pcb.kicad_pcb, pcb.kicad_sch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]
2026-09-07 Progressed P2 switch considerations
2026-09-07 Reviewed and improved PCB pad details
2026-09-07 Split prototype/gerbers and release/production makefile output and gates
    [BOM.csv, pcb.kicad_pcb, pcb.kicad_sch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]
2026-09-08 Review of Gemini simplification by GPT
    [BOM.csv, pcb.kicad_pcb, pcb.kicad_sch]
2026-09-08 Finalize R1/R2 as Uni-Royal PS122WF2201T4E
    [BOM.csv, pcb.kicad_pcb, pcb.kicad_sch]
2026-09-08 Widen clamp trace to match rest of board
    [pcb.kicad_pcb]
2026-09-11 Move to a TE R1/R2 prototype with Yageo for production
    [BOM.csv, pcb.kicad_pcb, pcb.kicad_sch]
2026-09-11 Tighten up text through careful dedup
2026-09-14 Rework GDT_AC as SMT using back sire WIRE_B only
    [BOM.csv, pcb.kicad_pcb, pcb.kicad_sch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]
2026-09-14 Finish the move to WIRE_B on the back side
2026-09-15 Space out inter-core GDTs to avoid flashover
    [pcb.kicad_pcb, pcb.kicad_sch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]
2026-09-15 Re-align board title
    [pcb.kicad_pcb]
2026-09-15 Expand the station PCB to remove EARTH terminal overhang
    [pcb.kicad_pcb]
2026-09-15 Plan for a Hub PCB which will serve to handle major power-related issues and checks
